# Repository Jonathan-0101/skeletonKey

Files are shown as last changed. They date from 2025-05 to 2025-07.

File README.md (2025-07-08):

# Skeleton Key




Final year BEng Project, creating a Penetration Testing Device based on an ESP32 microcontroller, to highlight common and prevelent security vulnerabilities in devices and networks.

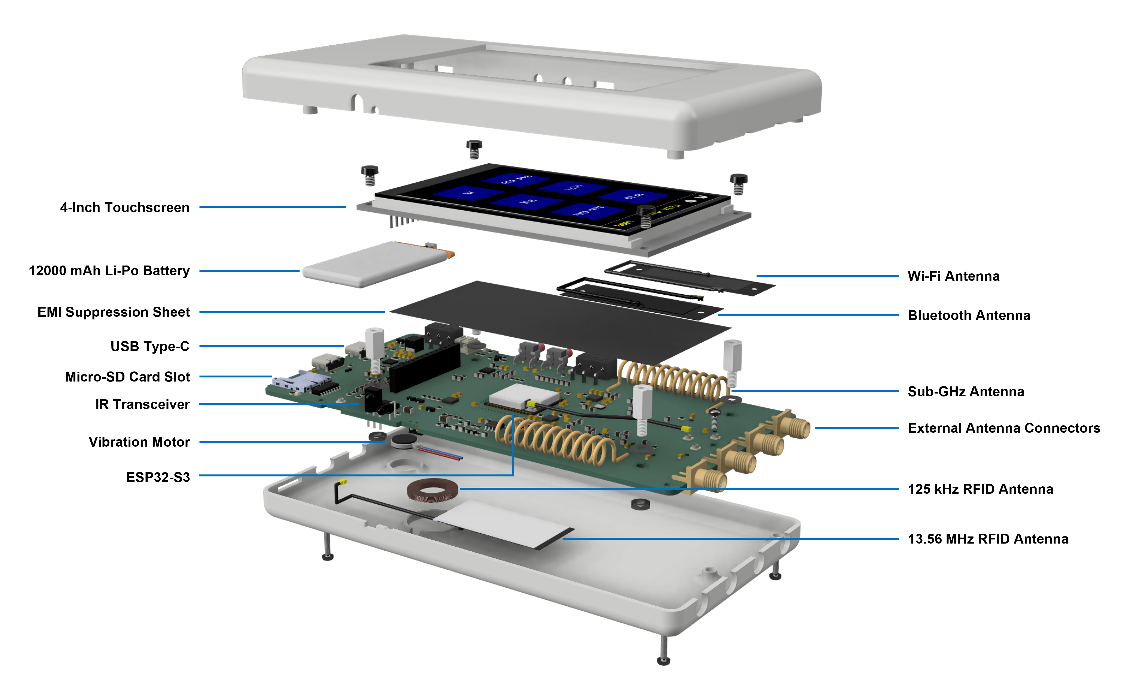
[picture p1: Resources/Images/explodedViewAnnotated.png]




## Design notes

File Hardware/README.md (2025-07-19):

# Project Hardware

The schematics and PCB designs for the device are contained in this directory, designed in KiCad.

It would not have been possible to create the project without the assistance of open source designs and resources, most notibly from [Adafruit Industries](https://github.com/adafruit) and [Flipper Devices](https://github.com/flipperdevices)

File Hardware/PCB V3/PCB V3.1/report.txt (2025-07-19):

Plotted to 'C:\Users\Jonathan Woolf\OneDrive - The University of Nottingham\Documents\0 Project\1_PCB\PCB V3\PCB V3.1\Jonathan_Woolf_PCB_V3_Gerber\PCB V3.1-F_Cu.gbr'.
Plotted to 'C:\Users\Jonathan Woolf\OneDrive - The University of Nottingham\Documents\0 Project\1_PCB\PCB V3\PCB V3.1\Jonathan_Woolf_PCB_V3_Gerber\PCB V3.1-In1_Cu.gbr'.
Plotted to 'C:\Users\Jonathan Woolf\OneDrive - The University of Nottingham\Documents\0 Project\1_PCB\PCB V3\PCB V3.1\Jonathan_Woolf_PCB_V3_Gerber\PCB V3.1-In2_Cu.gbr'.
Plotted to 'C:\Users\Jonathan Woolf\OneDrive - The University of Nottingham\Documents\0 Project\1_PCB\PCB V3\PCB V3.1\Jonathan_Woolf_PCB_V3_Gerber\PCB V3.1-B_Cu.gbr'.
Plotted to 'C:\Users\Jonathan Woolf\OneDrive - The University of Nottingham\Documents\0 Project\1_PCB\PCB V3\PCB V3.1\Jonathan_Woolf_PCB_V3_Gerber\PCB V3.1-F_Paste.gbr'.
Plotted to 'C:\Users\Jonathan Woolf\OneDrive - The University of Nottingham\Documents\0 Project\1_PCB\PCB V3\PCB V3.1\Jonathan_Woolf_PCB_V3_Gerber\PCB V3.1-B_Paste.gbr'.
Plotted to 'C:\Users\Jonathan Woolf\OneDrive - The University of Nottingham\Documents\0 Project\1_PCB\PCB V3\PCB V3.1\Jonathan_Woolf_PCB_V3_Gerber\PCB V3.1-F_Silkscreen.gbr'.
Plotted to 'C:\Users\Jonathan Woolf\OneDrive - The University of Nottingham\Documents\0 Project\1_PCB\PCB V3\PCB V3.1\Jonathan_Woolf_PCB_V3_Gerber\PCB V3.1-B_Silkscreen.gbr'.
Plotted to 'C:\Users\Jonathan Woolf\OneDrive - The University of Nottingham\Documents\0 Project\1_PCB\PCB V3\PCB V3.1\Jonathan_Woolf_PCB_V3_Gerber\PCB V3.1-F_Mask.gbr'.
Plotted to 'C:\Users\Jonathan Woolf\OneDrive - The University of Nottingham\Documents\0 Project\1_PCB\PCB V3\PCB V3.1\Jonathan_Woolf_PCB_V3_Gerber\PCB V3.1-B_Mask.gbr'.
Plotted to 'C:\Users\Jonathan Woolf\OneDrive - The University of Nottingham\Documents\0 Project\1_PCB\PCB V3\PCB V3.1\Jonathan_Woolf_PCB_V3_Gerber\PCB V3.1-Edge_Cuts.gbr'.
Created Gerber job file 'C:\Users\Jonathan Woolf\OneDrive - The University of Nottingham\Documents\0 Project\1_PCB\PCB V3\PCB V3.1\Jonathan_Woolf_PCB_V3_Gerber\PCB V3.1-job.gbrjob'.
Info: Done.

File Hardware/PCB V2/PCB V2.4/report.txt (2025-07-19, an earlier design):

Info: Output directory 'C:\Users\Jonathan Woolf\OneDrive - The University of Nottingham\Documents\0 Project\1_PCB\PCB V2\PCB V2.4\Gerber' created.
Plotted to 'C:\Users\Jonathan Woolf\OneDrive - The University of Nottingham\Documents\0 Project\1_PCB\PCB V2\PCB V2.4\Gerber\PCB V2.4-F_Cu.gbr'.
Plotted to 'C:\Users\Jonathan Woolf\OneDrive - The University of Nottingham\Documents\0 Project\1_PCB\PCB V2\PCB V2.4\Gerber\PCB V2.4-In1_Cu.gbr'.
Plotted to 'C:\Users\Jonathan Woolf\OneDrive - The University of Nottingham\Documents\0 Project\1_PCB\PCB V2\PCB V2.4\Gerber\PCB V2.4-In2_Cu.gbr'.
Plotted to 'C:\Users\Jonathan Woolf\OneDrive - The University of Nottingham\Documents\0 Project\1_PCB\PCB V2\PCB V2.4\Gerber\PCB V2.4-B_Cu.gbr'.
Plotted to 'C:\Users\Jonathan Woolf\OneDrive - The University of Nottingham\Documents\0 Project\1_PCB\PCB V2\PCB V2.4\Gerber\PCB V2.4-F_Paste.gbr'.
Plotted to 'C:\Users\Jonathan Woolf\OneDrive - The University of Nottingham\Documents\0 Project\1_PCB\PCB V2\PCB V2.4\Gerber\PCB V2.4-B_Paste.gbr'.
Plotted to 'C:\Users\Jonathan Woolf\OneDrive - The University of Nottingham\Documents\0 Project\1_PCB\PCB V2\PCB V2.4\Gerber\PCB V2.4-F_Silkscreen.gbr'.
Plotted to 'C:\Users\Jonathan Woolf\OneDrive - The University of Nottingham\Documents\0 Project\1_PCB\PCB V2\PCB V2.4\Gerber\PCB V2.4-B_Silkscreen.gbr'.
Plotted to 'C:\Users\Jonathan Woolf\OneDrive - The University of Nottingham\Documents\0 Project\1_PCB\PCB V2\PCB V2.4\Gerber\PCB V2.4-F_Mask.gbr'.
Plotted to 'C:\Users\Jonathan Woolf\OneDrive - The University of Nottingham\Documents\0 Project\1_PCB\PCB V2\PCB V2.4\Gerber\PCB V2.4-B_Mask.gbr'.
Plotted to 'C:\Users\Jonathan Woolf\OneDrive - The University of Nottingham\Documents\0 Project\1_PCB\PCB V2\PCB V2.4\Gerber\PCB V2.4-Edge_Cuts.gbr'.
Created Gerber job file 'C:\Users\Jonathan Woolf\OneDrive - The University of Nottingham\Documents\0 Project\1_PCB\PCB V2\PCB V2.4\Gerber\PCB V2.4-job.gbrjob'.
Plotted to 'C:\Users\Jonathan Woolf\OneDrive - The University of Nottingham\Documents\0 Project\1_PCB\PCB V2\PCB V2.4\Gerber\PCB V2.4-F_Cu.gbr'.
Plotted to 'C:\Users\Jonathan Woolf\OneDrive - The University of Nottingham\Documents\0 Project\1_PCB\PCB V2\PCB V2.4\Gerber\PCB V2.4-In1_Cu.gbr'.
Plotted to 'C:\Users\Jonathan Woolf\OneDrive - The University of Nottingham\Documents\0 Project\1_PCB\PCB V2\PCB V2.4\Gerber\PCB V2.4-In2_Cu.gbr'.
Plotted to 'C:\Users\Jonathan Woolf\OneDrive - The University of Nottingham\Documents\0 Project\1_PCB\PCB V2\PCB V2.4\Gerber\PCB V2.4-B_Cu.gbr'.
Plotted to 'C:\Users\Jonathan Woolf\OneDrive - The University of Nottingham\Documents\0 Project\1_PCB\PCB V2\PCB V2.4\Gerber\PCB V2.4-F_Paste.gbr'.
Plotted to 'C:\Users\Jonathan Woolf\OneDrive - The University of Nottingham\Documents\0 Project\1_PCB\PCB V2\PCB V2.4\Gerber\PCB V2.4-B_Paste.gbr'.
Plotted to 'C:\Users\Jonathan Woolf\OneDrive - The University of Nottingham\Documents\0 Project\1_PCB\PCB V2\PCB V2.4\Gerber\PCB V2.4-F_Silkscreen.gbr'.
Plotted to 'C:\Users\Jonathan Woolf\OneDrive - The University of Nottingham\Documents\0 Project\1_PCB\PCB V2\PCB V2.4\Gerber\PCB V2.4-B_Silkscreen.gbr'.
Plotted to 'C:\Users\Jonathan Woolf\OneDrive - The University of Nottingham\Documents\0 Project\1_PCB\PCB V2\PCB V2.4\Gerber\PCB V2.4-F_Mask.gbr'.
Plotted to 'C:\Users\Jonathan Woolf\OneDrive - The University of Nottingham\Documents\0 Project\1_PCB\PCB V2\PCB V2.4\Gerber\PCB V2.4-B_Mask.gbr'.
Plotted to 'C:\Users\Jonathan Woolf\OneDrive - The University of Nottingham\Documents\0 Project\1_PCB\PCB V2\PCB V2.4\Gerber\PCB V2.4-Edge_Cuts.gbr'.
Created Gerber job file 'C:\Users\Jonathan Woolf\OneDrive - The University of Nottingham\Documents\0 Project\1_PCB\PCB V2\PCB V2.4\Gerber\PCB V2.4-job.gbrjob'.
Info: Done.
Info: Done.

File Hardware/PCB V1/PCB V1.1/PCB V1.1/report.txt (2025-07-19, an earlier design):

Plotted to 'C:\Users\Jonathan Woolf\OneDrive - The University of Nottingham\Documents\0 Project\PCB test\PCB V1.1\PCB V1.1\Gerber\PCB V1.1-F_Cu.gbr'.
Plotted to 'C:\Users\Jonathan Woolf\OneDrive - The University of Nottingham\Documents\0 Project\PCB test\PCB V1.1\PCB V1.1\Gerber\PCB V1.1-B_Cu.gbr'.
Plotted to 'C:\Users\Jonathan Woolf\OneDrive - The University of Nottingham\Documents\0 Project\PCB test\PCB V1.1\PCB V1.1\Gerber\PCB V1.1-F_Paste.gbr'.
Plotted to 'C:\Users\Jonathan Woolf\OneDrive - The University of Nottingham\Documents\0 Project\PCB test\PCB V1.1\PCB V1.1\Gerber\PCB V1.1-B_Paste.gbr'.
Plotted to 'C:\Users\Jonathan Woolf\OneDrive - The University of Nottingham\Documents\0 Project\PCB test\PCB V1.1\PCB V1.1\Gerber\PCB V1.1-F_Silkscreen.gbr'.
Plotted to 'C:\Users\Jonathan Woolf\OneDrive - The University of Nottingham\Documents\0 Project\PCB test\PCB V1.1\PCB V1.1\Gerber\PCB V1.1-B_Silkscreen.gbr'.
Plotted to 'C:\Users\Jonathan Woolf\OneDrive - The University of Nottingham\Documents\0 Project\PCB test\PCB V1.1\PCB V1.1\Gerber\PCB V1.1-F_Mask.gbr'.
Plotted to 'C:\Users\Jonathan Woolf\OneDrive - The University of Nottingham\Documents\0 Project\PCB test\PCB V1.1\PCB V1.1\Gerber\PCB V1.1-B_Mask.gbr'.
Plotted to 'C:\Users\Jonathan Woolf\OneDrive - The University of Nottingham\Documents\0 Project\PCB test\PCB V1.1\PCB V1.1\Gerber\PCB V1.1-Edge_Cuts.gbr'.
Created Gerber job file 'C:\Users\Jonathan Woolf\OneDrive - The University of Nottingham\Documents\0 Project\PCB test\PCB V1.1\PCB V1.1\Gerber\PCB V1.1-job.gbrjob'.
Info: Done.

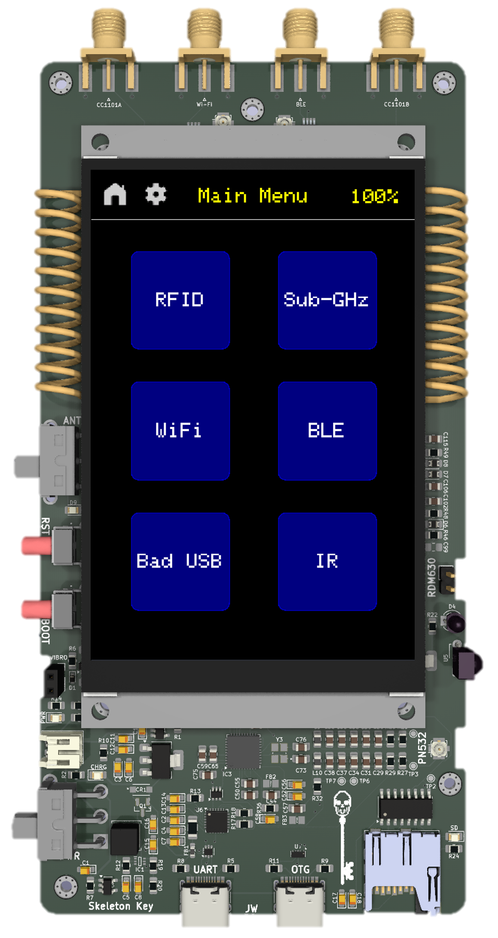
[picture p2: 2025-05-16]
Resources/Images/deviceTopDown.png

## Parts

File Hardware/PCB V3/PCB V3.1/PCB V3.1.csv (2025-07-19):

Id | Designator | Footprint | Quantity | Designation | Supplier and ref
1 | C82,C100,C101,C123,C84,C99,C53,C54,C96,C113,C118,C71,C80,C121,C45 | C_0805_2012Metric_Pad1.18x1.45mm_HandSolder | 15 | ~
2 | TP3 | TestPoint_Pad_D1.0mm | 1 | TX2_PRE
3 | C62,C31,C108,C30,C63,C107 | C_0805_2012Metric_Pad1.18x1.45mm_HandSolder | 6 | 100p
4 | C17,C87,C122,C88,C12,C40,C6,C70,C39,C66,C72,C68,C85,C111,C19,C24,C110,C25,C20,C112,C60,C52,C93,C32,C105,C114,C103,C91,C67,C92,C58,C94,C21,C109 | CP_EIA-2012-12_Kemet-R_Pad1.30x1.05mm_HandSolder | 34 | 0.1u
5 | L24,L13 | L_0805_2012Metric_Pad1.15x1.40mm_HandSolder | 2 | 6.8n
6 | L10,L9 | L_0805_2012Metric_Pad1.15x1.40mm_HandSolder | 2 | 560n
7 | C76,C73 | C_0805_2012Metric_Pad1.18x1.45mm_HandSolder | 2 | 33p
8 | C14,C4,C10 | CP_EIA-2012-12_Kemet-R_Pad1.30x1.05mm_HandSolder | 3 | 100n
9 | Q5 | TSOT-23_HandSoldering | 1 | Q_NPN_BEC
10 | R26,R27 | R_0805_2012Metric_Pad1.20x1.40mm_HandSolder | 2 | NC
11 | C69 | C_0805_2012Metric_Pad1.18x1.45mm_HandSolder | 1 | 0.3p
12 | C13,C16,C8,C15,C2 | CP_EIA-2012-12_Kemet-R_Pad1.30x1.05mm_HandSolder | 5 | 22u
13 | L2 | L_0805_2012Metric_Pad1.15x1.40mm_HandSolder | 1 | 8.2n
14 | TP6 | TestPoint_Pad_D1.0mm | 1 | TX2_POST
15 | C35,C28,C29,C38 | C_0805_2012Metric_Pad1.18x1.45mm_HandSolder | 4 | NC
16 | TP1 | TestPoint_Pad_D1.0mm | 1 | TX1_PRE
17 | Q6 | TSOT-23_HandSoldering | 1 | Q_PNP_BEC
18 | R51,R39,R38,R53 | R_0805_2012Metric_Pad1.20x1.40mm_HandSolder | 4 | 0
19 | L17,L26 | L_0805_2012Metric_Pad1.15x1.40mm_HandSolder | 2 | 2.2n
20 | L12,L23 | L_0805_2012Metric_Pad1.15x1.40mm_HandSolder | 2 | 3.3n
21 | L1 | L_Changjiang_FNR5045S | 1 | 1u
22 | J6 | PinHeader_1x02_P2.54mm_Vertical | 1 | RDM630_ANT_CONN
23 | Q4 | SOT-223-3_TabPin2 | 1 | PZT3904
24 | C18,C22,C86,C41,C119,C3,C56,C64,C11 | CP_EIA-2012-12_Kemet-R_Pad1.30x1.05mm_HandSolder | 9 | 10u
25 | R14,R59,R10,R24 | R_0805_2012Metric_Pad1.20x1.40mm_HandSolder | 4 | 1.5K
26 | R33,R47 | R_0805_2012Metric_Pad1.20x1.40mm_HandSolder | 2 | 56K
27 | R25 | R_0805_2012Metric_Pad1.20x1.40mm_HandSolder | 1 | 22k
28 | USB_OTG1,USB_UART1 | USB_C_Receptacle_HRO_TYPE-C-31-M-12 | 2 | USB_C_Receptacle_USB2.0_16P
29 | J10,J8 | PinSocket_1x14_P1.27mm_Vertical | 2 | Conn_01x14
30 | L18,L19,L4,L5,L20,L7 | L_0805_2012Metric_Pad1.15x1.40mm_HandSolder | 6 | 0
31 | R12,R20,R7 | R_0805_2012Metric_Pad1.20x1.40mm_HandSolder | 3 | 100k
32 | R1 | R_0805_2012Metric_Pad1.20x1.40mm_HandSolder | 1 | 4.7K
33 | L14,L15 | L_0805_2012Metric_Pad1.15x1.40mm_HandSolder | 2 | 2.4n
34 | C48 | C_0805_2012Metric_Pad1.18x1.45mm_HandSolder | 1 | 4.7p
35 | R16,R15,R2,R23,R4,R43 | R_0805_2012Metric_Pad1.20x1.40mm_HandSolder | 6 | 10K
36 | FB1 | L_0603_1608Metric_Pad1.05x0.95mm_HandSolder | 1 | BLM21PG221
37 | C115,C102 | C_0805_2012Metric_Pad1.18x1.45mm_HandSolder | 2 | 1n
38 | U9 | ESP32-S3-WROOM-1U_EXP | 1 | ESP32-S3-WROOM-1U-N16R2
39 | C104,C61 | C_0805_2012Metric_Pad1.18x1.45mm_HandSolder | 2 | 0.6p
40 | R49,R48,R52,R31,R57 | R_0805_2012Metric_Pad1.20x1.40mm_HandSolder | 5 | 1M
41 | C47 | C_0805_2012Metric_Pad1.18x1.45mm_HandSolder | 1 | 2.2n
42 | FB2,FB4 | BEADC2012X145N | 2 | FerriteBead
43 | U7 | Diodes_UDFN-10_1.0x2.5mm_P0.5mm | 1 | ESD7104MUTAG
44 | R35,R34,R36 | R_0805_2012Metric_Pad1.20x1.40mm_HandSolder | 3 | 1K
45 | R58,R55,R45,R50,R41,R54,R40,R56,R44 | R_0805_2012Metric_Pad1.20x1.40mm_HandSolder | 9 | 1k
46 | U13,U20,U11,U17,U16,U18,U15,U14 | Infineon_PG-TSNP-6-10_0.7x1.1mm_0.7x1.1mm_P0.4mm | 8 | BGS12WN6E6327XTSA1
47 | L25,L16 | L_0805_2012Metric_Pad1.15x1.40mm_HandSolder | 2 | ~
48 | PWR_SW1,ANT_SW1 | PWR-SW | 2 | 734-7296
49 | R37 | R_0805_2012Metric_Pad1.20x1.40mm_HandSolder | 1 | 20K
50 | C55,C59,C65,C83,C44 | C_0805_2012Metric_Pad1.18x1.45mm_HandSolder | 5 | 0.1u
51 | C1,C5 | CP_EIA-2012-12_Kemet-R_Pad1.30x1.05mm_HandSolder | 2 | 1u
52 | U4 | SOT-223-3_TabPin2 | 1 | AMS1117-3.3
53 | RESET1,BOOT1 | 118250272 | 2 | 1-1825027-2
54 | IC1 | SOTFL50P160X60-6N | 1 | TPS61023DRLT
55 | R46 | R_0805_2012Metric_Pad1.20x1.40mm_HandSolder | 1 | 10R
56 | IC7,IC5 | SOT95P284X110-6N | 2 | DG2001EDV-T1-GE3
57 | D7,D6,D8 | D_0805_2012Metric_Pad1.15x1.40mm_HandSolder | 3 | D
58 | U1 | SOT-23-5 | 1 | MCP73831-2-OT
59 | U19 | SOIC127P600X175-8N | 1 | LM358
60 | C57 | C_0805_2012Metric_Pad1.18x1.45mm_HandSolder | 1 | 1000p
61 | L11,L22 | L_0805_2012Metric_Pad1.15x1.40mm_HandSolder | 2 | 56n
62 | C97,C46 | C_0805_2012Metric_Pad1.18x1.45mm_HandSolder | 2 | 8.2p
63 | IC4 | QFN50P400X400X100-21N-D | 1 | C8051F330-GM
64 | IC3 | HVQFN-40-1EP_6x6mm_P0.5mm_EP4.1x4.1mm_ThermalVias | 1 | PN5321A3HN_C106,55
65 | IC2,IC6 | QFN50P400X400X100-21N-D | 2 | CC1101RGPR
66 | Y3 | XTAL_7M-27.120MAAJ-T | 1 | 27.12M
67 | J1 | PinSocket_1x02_P2.54mm_Vertical | 1 | Conn_01x02
68 | R5,R8,R11,R9 | R_0805_2012Metric_Pad1.20x1.40mm_HandSolder | 4 | 5k1
69 | C77,C116 | C_0805_2012Metric_Pad1.18x1.45mm_HandSolder | 2 | 1.2p
70 | C98,C95 | C_1206_3216Metric_Pad1.33x1.80mm_HandSolder | 2 | 3.3n
71 | C43,C33,C42,C34 | C_0805_2012Metric_Pad1.18x1.45mm_HandSolder | 4 | 22p
72 | Q7 | SOT-23 | 1 | MMBT5551L
73 | D4 | LED_D3.0mm_IRBlack | 1 | IR204A
74 | L8,L21,L3 | L_0805_2012Metric_Pad1.15x1.40mm_HandSolder | 3 | 2.7n
75 | R32 | R_0805_2012Metric_Pad1.20x1.40mm_HandSolder | 1 | 1.69K
76 | Q2 | SOT-23 | 1 | DMN2058U
77 | C49,C78,C79,C74,C81 | C_0805_2012Metric_Pad1.18x1.45mm_HandSolder | 5 | 1.5p
78 | FL2,FL1 | B0310J50100AHF | 2 | B0310J50100AHF
79 | U3 | SOT-23-5 | 1 | TLV70036_SOT23-5
80 | JSTPH1 | JST_PH_S2B-PH-K_1x02_P2.00mm_Horizontal | 1 | Battery Plug
81 | TP5,TP2 | TestPoint_Pad_D1.0mm | 2 | TGND
82 | R3 | R_0805_2012Metric_Pad1.20x1.40mm_HandSolder | 1 | 150
83 | J3 | GCT_MEM2061-01-188-00-A_REVA | 1 | MEM2061-01-188-00-A_REVA
84 | C37,C36 | C_0805_2012Metric_Pad1.18x1.45mm_HandSolder | 2 | 220p
85 | C23 | C_0805_2012Metric_Pad1.18x1.45mm_HandSolder | 1 | 33n
86 | R19 | R_0805_2012Metric_Pad1.20x1.40mm_HandSolder | 1 | 732k
87 | U2 | SOT-666 | 1 | USBLC6-2P6
88 | U6 | QFN-24-1EP_4x4mm_P0.5mm_EP2.6x2.6mm | 1 | CP2104
89 | C27,C90,C89,C26 | C_0805_2012Metric_Pad1.18x1.45mm_HandSolder | 4 | 9p
90 | D9 | LED_0805_2012Metric_Pad1.15x1.40mm_HandSolder | 1 | ANT_LED
91 | AE3 | SMA_Molex_73251-1153_EdgeMount_Horizontal | 1 | Antenna_CC1101B_SMA
92 | U5 | Vishay_MINICAST-3Pin | 1 | TSOP382xx
93 | AE8 | U.FL_Molex_MCRF_73412-0110_Vertical | 1 | Antenna_Wi-Fi_TBAR
94 | R13 | R_0805_2012Metric_Pad1.20x1.40mm_HandSolder | 1 | 10k
95 | R6 | R_0805_2012Metric_Pad1.20x1.40mm_HandSolder | 1 | 22
96 | R18,R17 | R_0805_2012Metric_Pad1.20x1.40mm_HandSolder | 2 | 22R
97 | C106,C120 | C_0805_2012Metric_Pad1.18x1.45mm_HandSolder | 2 | 4.7u
98 | Y2 | XTAL_7M-27.120MAAJ-T | 1 | 16M
99 | CR1 | SDO_SOD-123FL498_OSI | 1 | MBR120
100 | TP7 | TestPoint_Pad_D1.0mm | 1 | RX
101 | Y1,Y4 | Crystal_SMD_3225-4Pin_3.2x2.5mm_HandSoldering | 2 | 26MHz
102 | R22 | R_0805_2012Metric_Pad1.20x1.40mm_HandSolder | 1 | 50
103 | D3 | LED_0805_2012Metric_Pad1.15x1.40mm_HandSolder | 1 | Power_LED
104 | AE4 | XDCR_ANT-433-HESM | 1 | Antenna_CC1101B_PCB
105 | R42,R30,R21 | R_0805_2012Metric_Pad1.20x1.40mm_HandSolder | 3 | 330
106 | R28,R29 | R_0805_2012Metric_Pad1.20x1.40mm_HandSolder | 2 | 1.5
107 | C75,C50 | C_0805_2012Metric_Pad1.18x1.45mm_HandSolder | 2 | 10u
108 | U10 | QFN-20-1EP_4x4mm_P0.5mm_EP2.5x2.5mm | 1 | nRF24L01P
109 | FB3 | BEADC2012X145N | 1 | FerriteBead_Small
110 | D5 | LED_0805_2012Metric_Pad1.15x1.40mm_HandSolder | 1 | SD_ACT_LED
111 | Q1 | SOT95P240X105-3N | 1 | DMG3415U
112 | C51 | C_0805_2012Metric_Pad1.18x1.45mm_HandSolder | 1 | 1p
113 | F1 | Fuse_1206_3216Metric_Pad1.42x1.75mm_HandSolder | 1 | Polyfuse 1A
114 | D2 | LED_0805_2012Metric_Pad1.15x1.40mm_HandSolder | 1 | Charging_LED
115 | C7 | CP_EIA-2012-12_Kemet-R_Pad1.30x1.05mm_HandSolder | 1 | 4u7
116 | J5 | U.FL_Molex_MCRF_73412-0110_Vertical | 1 | PN532_Antenna_Coax
117 | U8 | SOIC-16_3.9x9.9mm_P1.27mm | 1 | 4050
118 | D1 | D_SOD-523 | 1 | 1N4148WT
119 | Q3 | SOT-363_SC-70-6 | 1 | UMH3N
120 | AE1 | SMA_Molex_73251-1153_EdgeMount_Horizontal | 1 | Antenna_CC1101A_SMA
121 | AE7 | SMA_Molex_73251-1153_EdgeMount_Horizontal | 1 | Antenna_Wi-Fi_SMA
122 | SCREEN1 | 4.0_TFT_Display | 1 | ~
123 | J9 | PinSocket_1x12_P1.27mm_Vertical | 1 | Conn_01x12
124 | TP4 | TestPoint_Pad_D1.0mm | 1 | TX1_POST
125 | C117 | C_0805_2012Metric_Pad1.18x1.45mm_HandSolder | 1 | 100n
126 | U12 | RFX2401C_SKY | 1 | RFX2401C
127 | AE2 | XDCR_ANT-433-HESM | 1 | Antenna_CC1101A_PCB
128 | J7 | U.FL_Molex_MCRF_73412-0110_Vertical | 1 | Wi-Fi_ANT_Coax
129 | L6 | L_0805_2012Metric_Pad1.15x1.40mm_HandSolder | 1 | 3.9n
130 | AE6 | U.FL_Molex_MCRF_73412-0110_Vertical | 1 | Antenna_NRF24_IPEX
131 | AE5 | SMA_Molex_73251-1153_EdgeMount_Horizontal | 1 | Antenna_NRF24_SMA

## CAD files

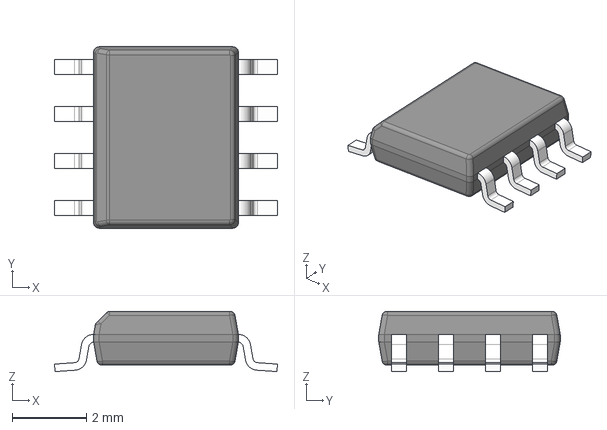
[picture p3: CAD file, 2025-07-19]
Hardware/Symbols_Footprints_3D_Models/3D Models/LM358MX_NOPB.stp
6.02 x 4.90 x 1.63 mm
BODY-SO
LEAD-D0008A x 8

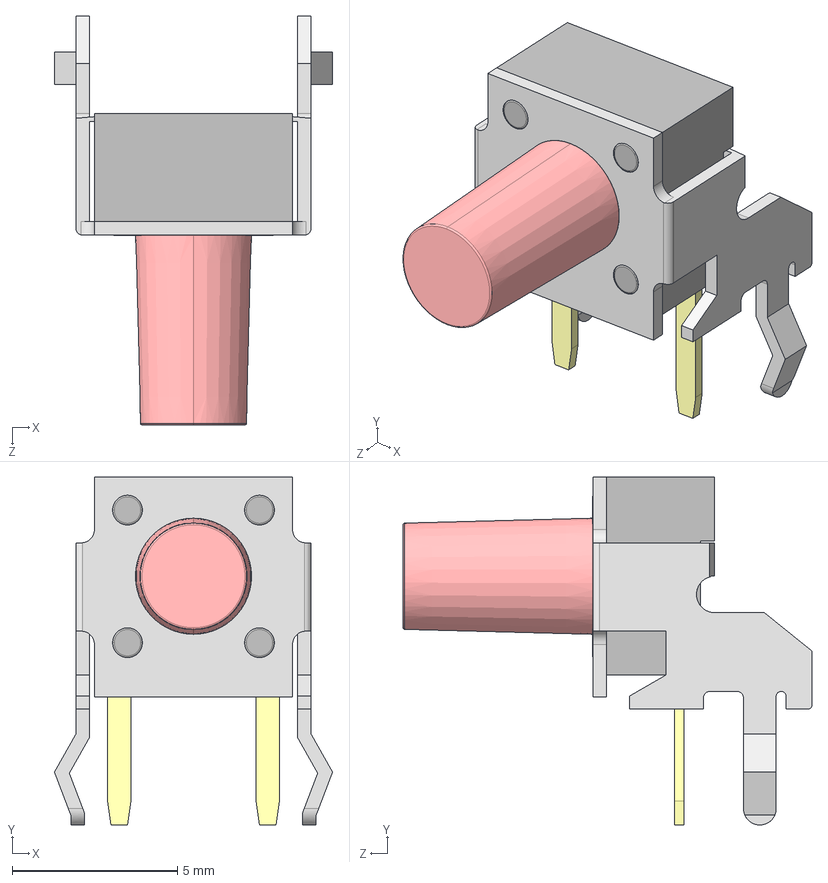
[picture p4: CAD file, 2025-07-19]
Hardware/Symbols_Footprints_3D_Models/3D Models/1-1825027-2.stp
8.41 x 10.5 x 12.4 mm

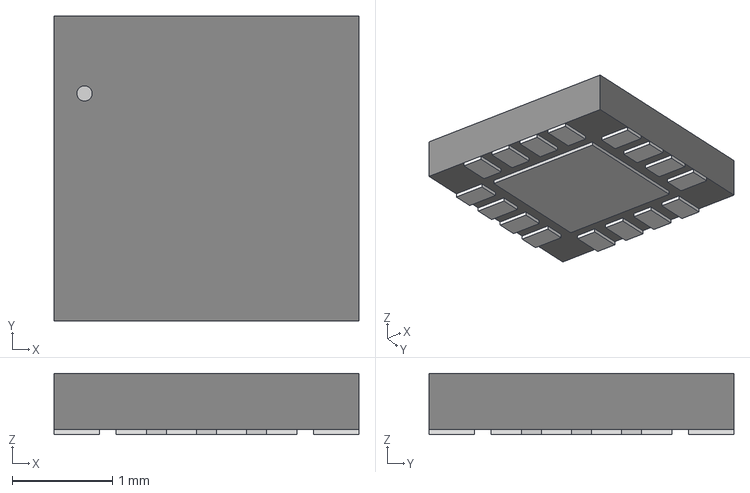
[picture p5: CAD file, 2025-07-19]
Hardware/Symbols_Footprints_3D_Models/3D Models/RFX2401C_SKY.step
3.05 x 3.05 x 0.612 mm

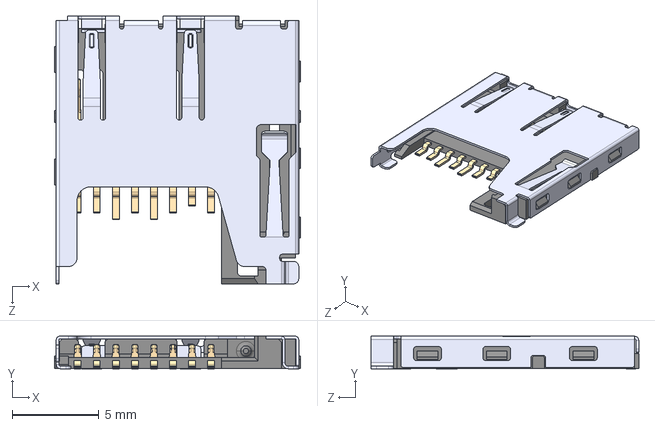
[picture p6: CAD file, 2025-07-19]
Hardware/Symbols_Footprints_3D_Models/3D Models/MEM2061-01-188-00-A_REVA.step
14.2 x 1.88 x 15.4 mm

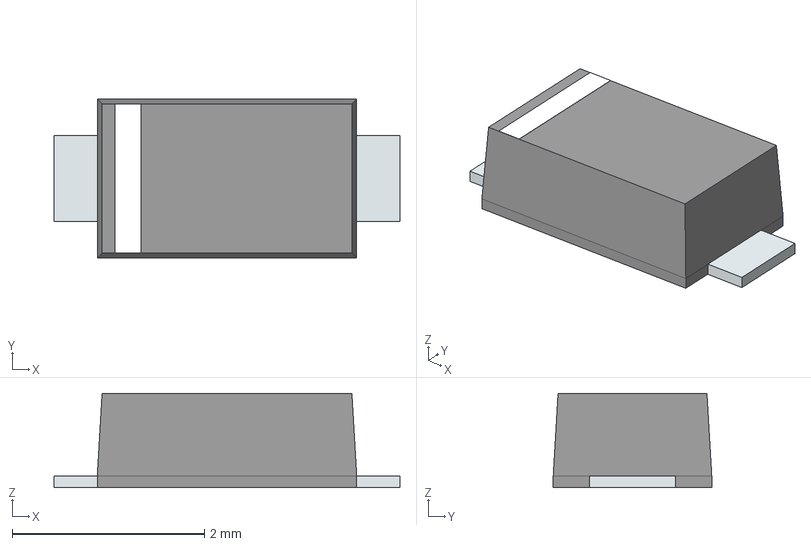
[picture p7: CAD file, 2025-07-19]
Hardware/Symbols_Footprints_3D_Models/3D Models/MBR120ESFT3G.stp
3.60 x 1.65 x 0.98 mm
PinKIdent
PinK
PinA

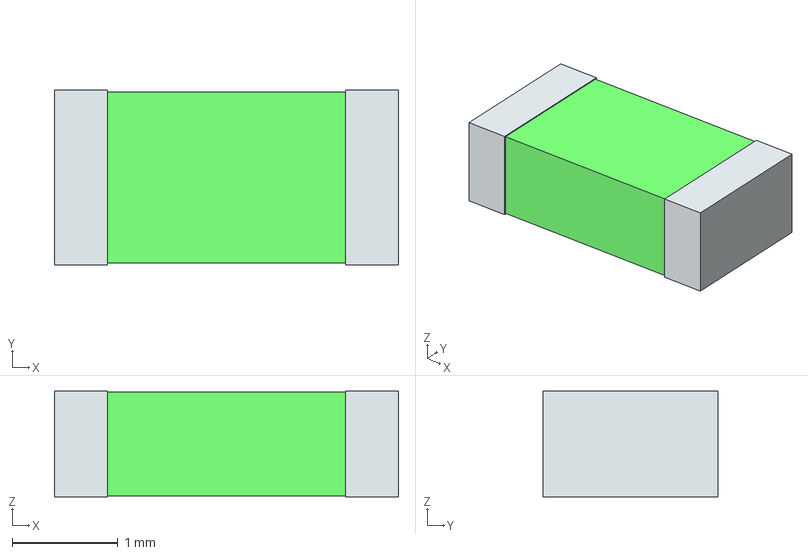
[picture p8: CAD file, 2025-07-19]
Hardware/Symbols_Footprints_3D_Models/3D Models/0ZCJ0100FF2E.stp
3.25 x 1.65 x 1.00 mm
term1
term2

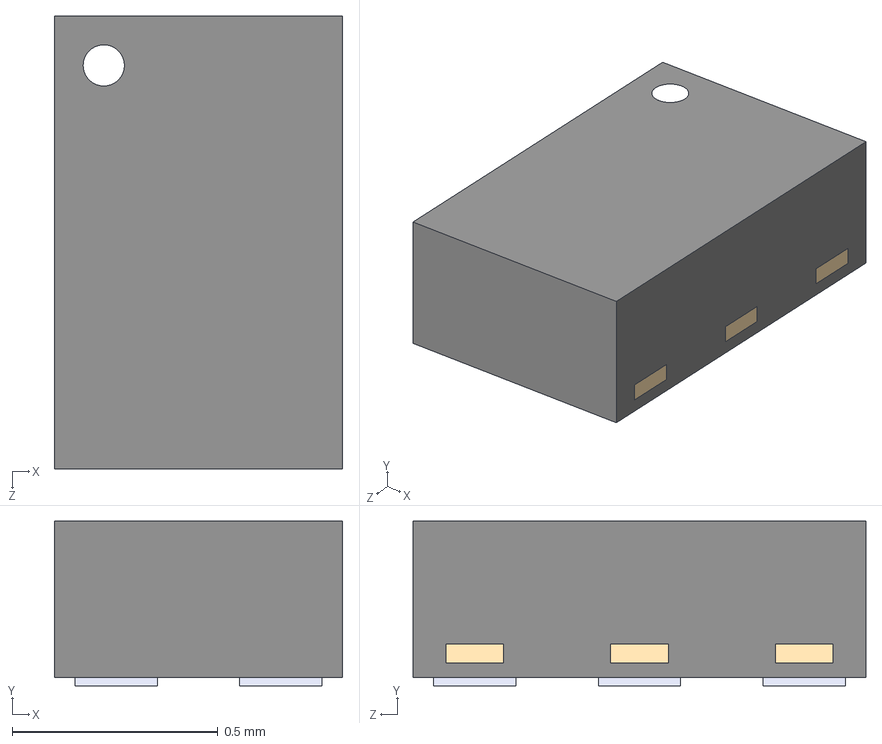
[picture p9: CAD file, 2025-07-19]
Hardware/Symbols_Footprints_3D_Models/3D Models/BGS12WN6E6327XTSA1.stp
0.7 x 0.4 x 1.10 mm

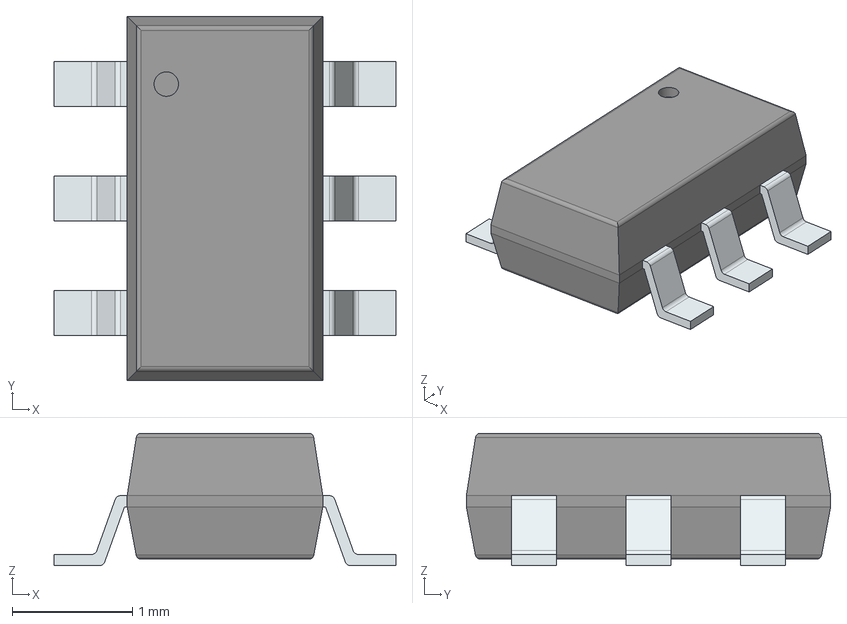
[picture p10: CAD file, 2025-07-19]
Hardware/Symbols_Footprints_3D_Models/3D Models/DG2001EDV-T1-GE3.stp
2.84 x 3.02 x 1.10 mm
PinsArrayLR

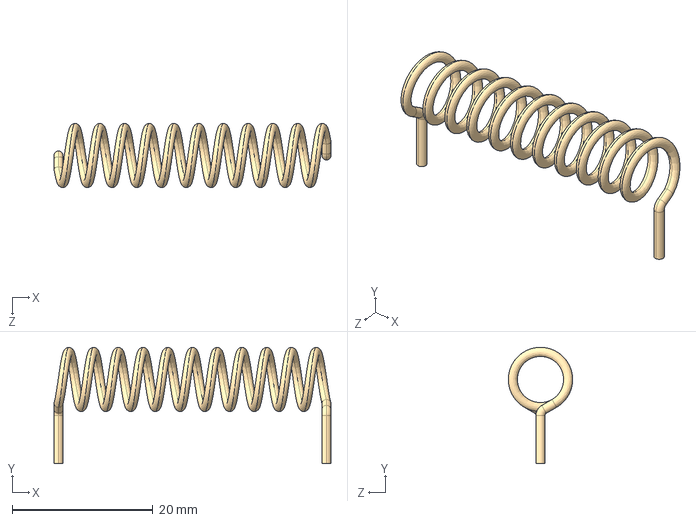
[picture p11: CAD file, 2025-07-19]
Hardware/Symbols_Footprints_3D_Models/3D Models/ANT-433-HETH.step
39.4 x 16.5 x 9.14 mm

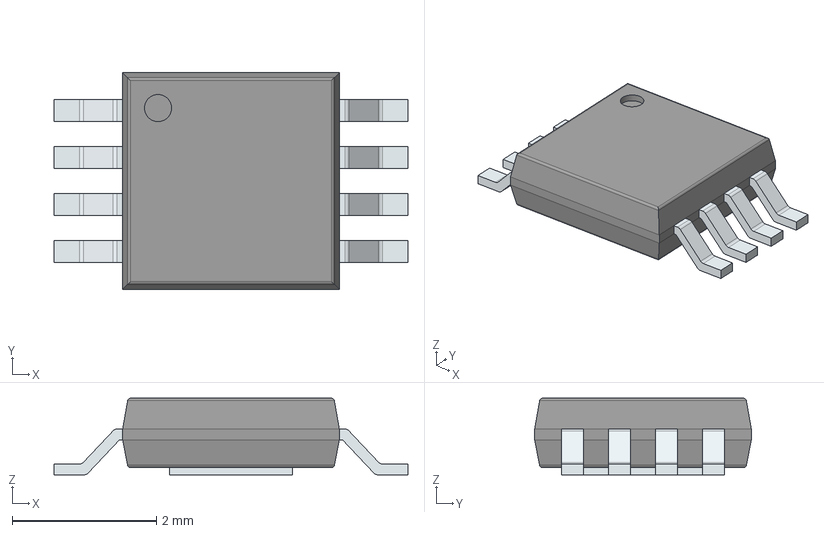
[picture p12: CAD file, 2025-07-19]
Hardware/Symbols_Footprints_3D_Models/3D Models/PE4251MLI-Z.stp
4.90 x 3.00 x 1.06 mm
PinsArrayLR
ThermalPad

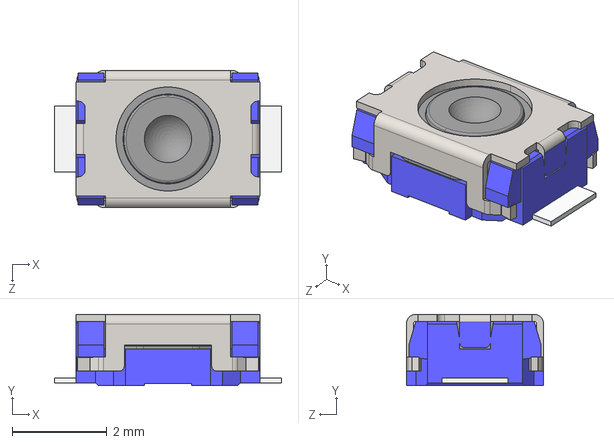
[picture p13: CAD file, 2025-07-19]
Hardware/Symbols_Footprints_3D_Models/3D Models/SKRKAGE020.stp
4.80 x 1.51 x 2.90 mm

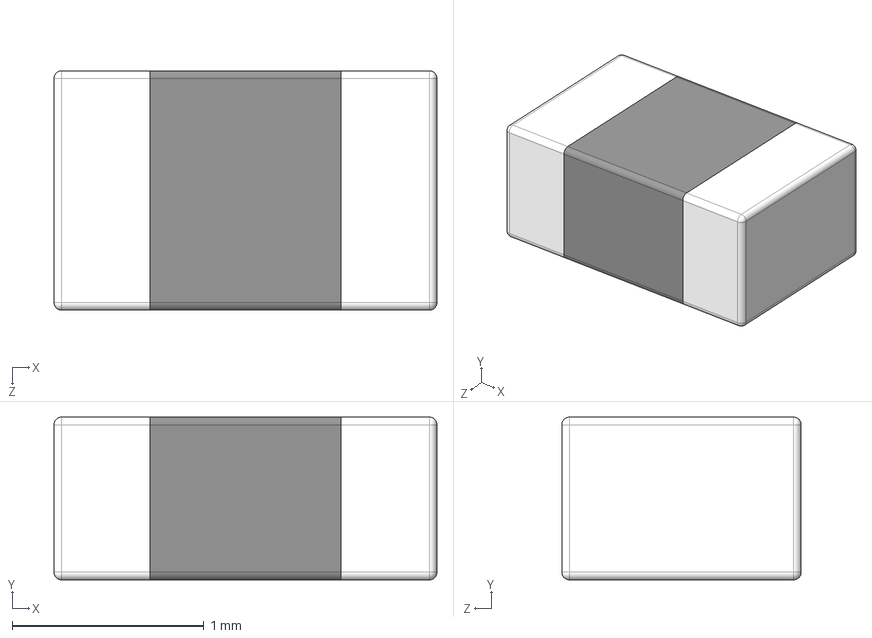
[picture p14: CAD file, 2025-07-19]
Hardware/Symbols_Footprints_3D_Models/3D Models/BLM21AG601SH1D.stp
2.00 x 0.85 x 1.25 mm

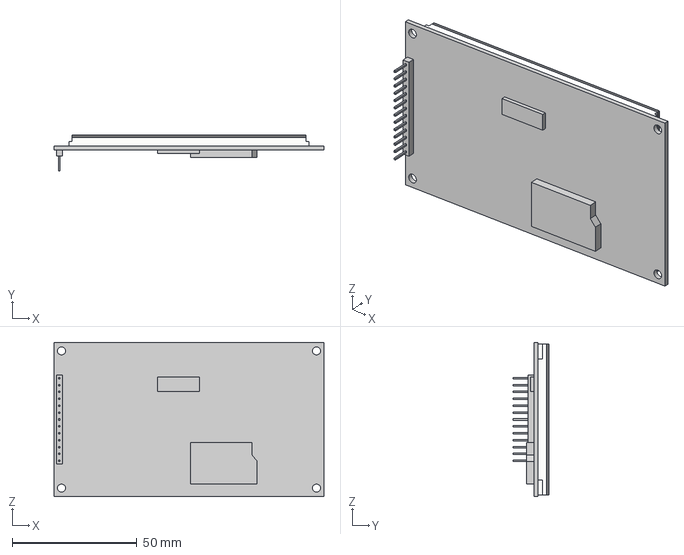
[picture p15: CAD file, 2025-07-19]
Hardware/Symbols_Footprints_3D_Models/3D Models/4 Inch TFT SPI 480x320 V1.2.step
108.0 x 14.5 x 61.6 mm

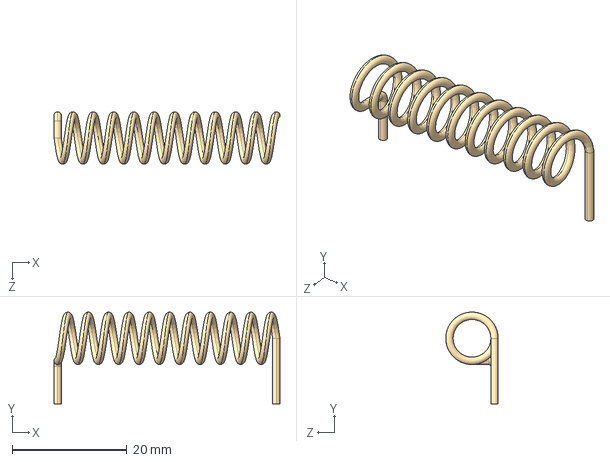
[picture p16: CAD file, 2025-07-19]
Hardware/Symbols_Footprints_3D_Models/3D Models/ANT-433-HESM.step
39.4 x 16.0 x 9.14 mm

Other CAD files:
Hardware/Symbols_Footprints_3D_Models/3D Models/DMG3415UQ-7.stp
Hardware/Symbols_Footprints_3D_Models/3D Models/C8051F330-GM.stp
Hardware/Symbols_Footprints_3D_Models/3D Models/B0310J50100AHF.stp
Hardware/Symbols_Footprints_3D_Models/3D Models/PN5321A3HN_C106,55.stp
Hardware/PCB V1/PCB V1.0/PCB V1.0/PCB V1.0.step
Hardware/PCB V1/PCB V1.1/PCB V1.1/PCB V1.1.step
Hardware/PCB V1/PCB/PCB.step
Hardware/PCB V2/PCB V2.0/PCB V2.0.step
Hardware/Symbols_Footprints_3D_Models/3D Models/7347296.stp
Hardware/Symbols_Footprints_3D_Models/3D Models/CC1101RGPR.stp
Hardware/Symbols_Footprints_3D_Models/3D Models/TPS61023DRLT.stp

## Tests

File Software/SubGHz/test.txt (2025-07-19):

//
// CC1101 interactive terminal tool
// allows for sending / receiving data over serial port
// on selected radio channel, modulation, ..
//
// (C) Adam Loboda '2023 , adam.loboda@wp.pl
//
// based on great SmartRC library by Little_S@tan
// Please download ZIP from
// https://github.com/LSatan/SmartRC-CC1101-Driver-Lib
// and attach it as ZIP library for Arduino
//
// Also uses Arduino Command Line interpreter by Edgar Bonet
// from https://gist.github.com/edgar-bonet/607b387260388be77e96
//
// This code will ONLY work with ESP32 board
//

#include <EEPROM.h>
#include <ELECHOUSE_CC1101_SRC_DRV.h>

#define CCBUFFERSIZE 64
#define RECORDINGBUFFERSIZE 4096  // Buffer for recording the frames
#define EPROMSIZE 512             // Size of EEPROM in your Arduino chip. For ESP32 it is Flash simulated so very slow
#define BUF_LENGTH 128            // Buffer for the incoming command.

// defining PINs set for ESP32 module
// Example for XIAO ESP32 C3
/* byte sck = 8;
byte miso = 4;
byte mosi = 10;
byte ss = 20;
int gdo0 = 21;
int gdo2 = 7; */

// defining PINs set for ESP32 WROOM module

// // ---------------------------------------
// // CC1101A
// byte sck = 39;
// byte miso = 41;
// byte mosi = 40;
// byte ss = 8;
// int gdo0 = 9;
// int rfSwitch = 10;
// // ---------------------------------------

// ---------------------------------------
// CC1101B
byte sck = 17;
byte miso = 15;
byte mosi = 16;
byte ss = 3;
int gdo0 = 11;
int rfSwitch = 12;
// ---------------------------------------

// position in big recording buffer
int bigrecordingbufferpos = 0;

// number of frames in big recording buffer
int framesinbigrecordingbuffer = 0;

// check if CLI receiving mode enabled
int receivingmode = 0;

// check if CLI jamming mode enabled
int jammingmode = 0;

// check if CLI recording mode enabled
int recordingmode = 0;

// check if CLI chat mode enabled
int chatmode = 0;

static bool do_echo = true;

// buffer for receiving  CC1101
byte ccreceivingbuffer[CCBUFFERSIZE] = {0};

// buffer for sending  CC1101
byte ccsendingbuffer[CCBUFFERSIZE] = {0};
// char ccsendingbuffer[CCBUFFERSIZE] = {0};

// buffer for recording and replaying of many frames
byte bigrecordingbuffer[RECORDINGBUFFERSIZE] = {0};

// buffer for hex to ascii conversions
byte textbuffer[BUF_LENGTH];
// char textbuffer[BUF_LENGTH];

// convert bytes in table to string with hex numbers
void asciitohex(byte *ascii_ptr, byte *hex_ptr, int len) {
    byte i, j, k;
    for (i = 0; i < len; i++) {
        // high byte first
        j = ascii_ptr[i] / 16;
        if (j > 9) {
            k = j - 10 + 65;
        } else {
            k = j + 48;
        }
        hex_ptr[2 * i] = k;
        // low byte second
        j = ascii_ptr[i] % 16;
        if (j > 9) {
            k = j - 10 + 65;
        } else {
            k = j + 48;
        }
        hex_ptr[(2 * i) + 1] = k;
    };
    hex_ptr[(2 * i) + 2] = '\0';
}

// convert string with hex numbers to array of bytes
void hextoascii(byte *ascii_ptr, byte *hex_ptr, int len) {
    byte i, j;
    for (i = 0; i < (len / 2); i++) {
        j = hex_ptr[i * 2];
        if ((j > 47) && (j < 58)) ascii_ptr[i] = (j - 48) * 16;
        if ((j > 64) && (j < 71)) ascii_ptr[i] = (j - 55) * 16;
        if ((j > 96) && (j < 103)) ascii_ptr[i] = (j - 87) * 16;
        j = hex_ptr[i * 2 + 1];
        if ((j > 47) && (j < 58)) ascii_ptr[i] = ascii_ptr[i] + (j - 48);
        if ((j > 64) && (j < 71)) ascii_ptr[i] = ascii_ptr[i] + (j - 55);
        if ((j > 96) && (j < 103)) ascii_ptr[i] = ascii_ptr[i] + (j - 87);
    };
    ascii_ptr[i++] = '\0';
}

// Initialize CC1101 board with default settings, you may change your preferences here
static void cc1101initialize(void) {
    // initializing library with custom pins selected
    ELECHOUSE_cc1101.setSpiPin(sck, miso, mosi, ss);
    // ELECHOUSE_cc1101.setGDO(gdo0, gdo2);

    // Main part to tune CC1101 with proper frequency, modulation and encoding
    ELECHOUSE_cc1101.Init();                 // must be set to initialize the cc1101!
    ELECHOUSE_cc1101.setGDO0(gdo0);          // set lib internal gdo pin (gdo0). Gdo2 not use for this example.
    ELECHOUSE_cc1101.setCCMode(1);           // set config for internal transmission mode. value 0 is for RAW recording/replaying
    ELECHOUSE_cc1101.setModulation(2);       // set modulation mode. 0 = 2-FSK, 1 = GFSK, 2 = ASK/OOK, 3 = 4-FSK, 4 = MSK.
    ELECHOUSE_cc1101.setMHZ(433.92);         // Here you can set your basic frequency. The lib calculates the frequency automatically (default = 433.92).The cc1101 can: 300-348 MHZ, 387-464MHZ and 779-928MHZ. Read More info from datasheet.
    ELECHOUSE_cc1101.setDeviation(47.60);    // Set the Frequency deviation in kHz. Value from 1.58 to 380.85. Default is 47.60 kHz.
    ELECHOUSE_cc1101.setChannel(0);          // Set the Channelnumber from 0 to 255. Default is cahnnel 0.
    ELECHOUSE_cc1101.setChsp(199.95);        // The channel spacing is multiplied by the channel number CHAN and added to the base frequency in kHz. Value from 25.39 to 405.45. Default is 199.95 kHz.
    ELECHOUSE_cc1101.setRxBW(812.50);        // Set the Receive Bandwidth in kHz. Value from 58.03 to 812.50. Default is 812.50 kHz.
    ELECHOUSE_cc1101.setDRate(9.6);          // Set the Data Rate in kBaud. Value from 0.02 to 1621.83. Default is 99.97 kBaud!
    ELECHOUSE_cc1101.setPA(10);              // Set TxPower. The following settings are possible depending on the frequency band.  (-30  -20  -15  -10  -6    0    5    7    10   11   12) Default is max!
    ELECHOUSE_cc1101.setSyncMode(2);         // Combined sync-word qualifier mode. 0 = No preamble/sync. 1 = 16 sync word bits detected. 2 = 16/16 sync word bits detected. 3 = 30/32 sync word bits detected. 4 = No preamble/sync, carrier-sense above threshold. 5 = 15/16 + carrier-sense above threshold. 6 = 16/16 + carrier-sense above threshold. 7 = 30/32 + carrier-sense above threshold.
    ELECHOUSE_cc1101.setSyncWord(211, 145);  // Set sync word. Must be the same for the transmitter and receiver. Default is 211,145 (Syncword high, Syncword low)
    ELECHOUSE_cc1101.setAdrChk(0);           // Controls address check configuration of received packages. 0 = No address check. 1 = Address check, no broadcast. 2 = Address check and 0 (0x00) broadcast. 3 = Address check and 0 (0x00) and 255 (0xFF) broadcast.
    ELECHOUSE_cc1101.setAddr(0);             // Address used for packet filtration. Optional broadcast addresses are 0 (0x00) and 255 (0xFF).
    ELECHOUSE_cc1101.setWhiteData(0);        // Turn data whitening on / off. 0 = Whitening off. 1 = Whitening on.
    ELECHOUSE_cc1101.setPktFormat(0);        // Format of RX and TX data. 0 = Normal mode, use FIFOs for RX and TX. 1 = Synchronous serial mode, Data in on GDO0 and data out on either of the GDOx pins. 2 = Random TX mode; sends random data using PN9 generator. Used for test. Works as normal mode, setting 0 (00), in RX. 3 = Asynchronous serial mode, Data in on GDO0 and data out on either of the GDOx pins.
    ELECHOUSE_cc1101.setLengthConfig(1);     // 0 = Fixed packet length mode. 1 = Variable packet length mode. 2 = Infinite packet length mode. 3 = Reserved
    ELECHOUSE_cc1101.setPacketLength(0);     // Indicates the packet length when fixed packet length mode is enabled. If variable packet length mode is used, this value indicates the maximum packet length allowed.
    ELECHOUSE_cc1101.setCrc(0);              // 1 = CRC calculation in TX and CRC check in RX enabled. 0 = CRC disabled for TX and RX.
    ELECHOUSE_cc1101.setCRC_AF(0);           // Enable automatic flush of RX FIFO when CRC is not OK. This requires that only one packet is in the RXIFIFO and that packet length is limited to the RX FIFO size.
    ELECHOUSE_cc1101.setDcFilterOff(0);      // Disable digital DC blocking filter before demodulator. Only for data rates ≤ 250 kBaud The recommended IF frequency changes when the DC blocking is disabled. 1 = Disable (current optimized). 0 = Enable (better sensitivity).
    ELECHOUSE_cc1101.setManchester(0);       // Enables Manchester encoding/decoding. 0 = Disable. 1 = Enable.
    ELECHOUSE_cc1101.setFEC(0);              // Enable Forward Error Correction (FEC) with interleaving for packet payload (Only supported for fixed packet length mode. 0 = Disable. 1 = Enable.
    ELECHOUSE_cc1101.setPRE(0);              // Sets the minimum number of preamble bytes to be transmitted. Values: 0 : 2, 1 : 3, 2 : 4, 3 : 6, 4 : 8, 5 : 12, 6 : 16, 7 : 24
    ELECHOUSE_cc1101.setPQT(0);              // Preamble quality estimator threshold. The preamble quality estimator increases an internal counter by one each time a bit is received that is different from the previous bit, and decreases the counter by 8 each time a bit is received that is the same as the last bit. A threshold of 4∙PQT for this counter is used to gate sync word detection. When PQT=0 a sync word is always accepted.
    ELECHOUSE_cc1101.setAppendStatus(0);     // When enabled, two status bytes will be appended to the payload of the packet. The status bytes contain RSSI and LQI values, as well as CRC OK.
}

// Execute a complete CC1101 command.

static void exec(char *cmdline) {
    char *command = strsep(&cmdline, " ");
    int setting, setting2, len;
    uint16_t brute, poweroftwo;
    byte j, k;
    float settingf1;
    float settingf2;
    // variables for frequency scanner
    float freq;
    long compare_freq;
    float mark_freq;
    int rssi;
    int mark_rssi = -100;

    // identification of the command & actions

    if (strcmp_P(command, PSTR("help")) == 0) {
        Serial.println(F(
            "setmodulation <mode> : Set modulation mode. 0 = 2-FSK, 1 = GFSK, 2 = ASK/OOK, 3 = 4-FSK, 4 = MSK.\r\n\r\n"
            "setmhz <frequency>   : Here you can set your basic frequency. default = 433.92).The cc1101 can: 300-348 MHZ, 387-464MHZ and 779-928MHZ.\r\n\r\n"
            "setdeviation <deviation> : Set the Frequency deviation in kHz. Value from 1.58 to 380.85.\r\n\r\n"
            "setchannel <channel> : Set the Channelnumber from 0 to 255. Default is cahnnel 0.\r\n\r\n"
            "setchsp <spacing>  :  The channel spacing is multiplied by the channel number CHAN and added to the base frequency in kHz. Value from 25.39 to 405.45. \r\n\r\n"
            "setrxbw <Receive bndwth> : Set the Receive Bandwidth in kHz. Value from 58.03 to 812.50. \r\n\r\n"
            "setdrate <datarate> : Set the Data Rate in kBaud. Value from 0.02 to 1621.83.\r\n\r\n"
            "setpa <power value> : Set RF transmission power. The following settings are possible depending on the frequency band.  (-30  -20  -15  -10  -6    0    5    7    10   11   12) Default is max!\r\n\r\n"
            "setsyncmode  <sync mode> : Combined sync-word qualifier mode. 0 = No preamble/sync. 1 = 16 sync word bits detected. 2 = 16/16 sync word bits detected. 3 = 30/32 sync word bits detected. 4 = No preamble/sync, carrier-sense above threshold. 5 = 15/16 + carrier-sense above threshold. 6 = 16/16 + carrier-sense above threshold. 7 = 30/32 + carrier-sense above threshold.\r\n"));
        Serial.println(F(
            "setsyncword <decimal LOW, decimal HIGH> : Set sync word. Must be the same for the transmitter and receiver. (Syncword high, Syncword low) Default is 211,145\r\n\r\n"
            "setadrchk <address chk> : Controls address check configuration of received packages. 0 = No address check. 1 = Address check, no broadcast. 2 = Address check and 0 (0x00) broadcast. 3 = Address check and 0 (0x00) and 255 (0xFF) broadcast.\r\n\r\n"
            "setaddr <address> : Address used for packet filtration. Optional broadcast addresses are 0 (0x00) and 255 (0xFF).\r\n\r\n"
            "setwhitedata <whitening> : Turn data whitening on / off. 0 = Whitening off. 1 = Whitening on.\r\n\r\n"
            "setpktformat <pktformat> : Format of RX and TX data. 0 = Normal mode, use FIFOs for RX and TX. 1 = Synchronous serial mode, Data in on GDO0 and data out on either of the GDOx pins. 2 = Random TX mode; sends random data using PN9 generator.  3 = Asynchronous serial mode\r\n\r\n"
            "setlengthconfig <mode> : Set packet Length mode : 0 = Fixed packet length mode. 1 = Variable packet length mode. 2 = Infinite packet length mode. 3 = Reserved \r\n\r\n"
            "setpacketlength <mode> : Indicates the packet length when fixed packet length mode is enabled. If variable packet length mode is used, this value indicates the maximum packet length allowed.\r\n\r\n"
            "setcrc <mode> : Switches on/of CRC calculation and check. 1 = CRC calculation in TX and CRC check in RX enabled. 0 = CRC disabled for TX and RX.\r\n\r\n"
            "setcrcaf <mode> : Enable automatic flush of RX FIFO when CRC is not OK. This requires that only one packet is in the RXIFIFO and that packet length is limited to the RX FIFO size.\r\n"));
        Serial.println(F(
            "setdcfilteroff <mode> : Disable digital DC blocking filter before demodulator. Only for data rates ≤ 250 kBaud The recommended IF frequency changes when the DC blocking is disabled. 1 = Disable (current optimized). 0 = Enable (better sensitivity).\r\n\r\n"
            "setmanchester <mode> : Enables Manchester encoding/decoding. 0 = Disable. 1 = Enable.\r\n\r\n"
            "setfec <mode> : Enable Forward Error Correction (FEC) with interleaving for packet payload (Only supported for fixed packet length mode. 0 = Disable. 1 = Enable.\r\n\r\n"
            "setpre <mode> : Sets the minimum number of preamble bytes to be transmitted. Values: 0 : 2, 1 : 3, 2 : 4, 3 : 6, 4 : 8, 5 : 12, 6 : 16, 7 : 24\r\n\r\n"
            "setpqt <mode> : Preamble quality estimator threshold. \r\n\r\n"
            "setappendstatus <mode> : When enabled, two status bytes will be appended to the payload of the packet. The status bytes contain RSSI and LQI values, as well as CRC OK.\r\n\r\n"
            "getrssi : Display quality information about last received frames over RF\r\n\r\n"
            "scan <start> <stop> : Scan frequency range for the highest signal.\r\n\r\n"
            "chat :  Enable chat mode between many devices. No exit available, disconnect device to quit\r\n"));
        Serial.println(F(
            "rx : Sniffer. Enable or disable printing of received RF packets on serial terminal.\r\n\r\n"
            "tx <hex-vals> : Send packet of max 60 bytes <hex values> over RF\r\n\r\n"
            "jam : Enable or disable continous jamming on selected band.\r\n\r\n"
            "brute <microseconds> <number-of-bits> : Brute force garage gate with <nb-of-bits> keyword where symbol time is <usec>.\r\n\r\n"
            "rec : Enable or disable recording frames in the buffer.\r\n\r\n"
            "add <hex-vals> : Manually add single frame payload (max 64 hex values) to the buffer so it can be replayed\r\n\r\n"
            "show : Show content of recording buffer\r\n\r\n"
            "flush : Clear the recording buffer\r\n\r\n"
            "play <N> : Replay 0 = all frames or N-th recorded frame previously stored in the buffer.\r\n\r\n"
            "rxraw <microseconds> : Sniffs radio by sampling with <microsecond> interval and prints received bytes in hex.\r\n\r\n"
            "recraw <microseconds> : Recording RAW RF data with <microsecond> sampling interval.\r\n"));
        Serial.println(F(
            "addraw <hex-vals> : Manually add chunks (max 60 hex values) to the buffer so they can be further replayed.\r\n\r\n"
            "showraw : Showing content of recording buffer in RAW format.\r\n\r\n"
            "playraw <microseconds> : Replaying previously recorded RAW RF data with <microsecond> sampling interval.\r\n\r\n"
            "showbit : Showing content of recording buffer in RAW format as a stream of bits.\r\n\r\n"
            "save : Store recording buffer content in non-volatile memory\r\n\r\n"
            "load : Load the content from non-volatile memory to the recording buffer\r\n\r\n"
            "echo <mode> : Enable or disable Echo on serial terminal. 1 = enabled, 0 = disabled\r\n\r\n"
            "x : Stops jamming/receiving/recording packets.\r\n\r\n"
            "init : Restarts CC1101 board with default parameters\r\n\r\n"));

        // Handling SETMODULATION command
    } else if (strcmp_P(command, PSTR("setmodulation")) == 0) {
        setting = atoi(cmdline);
        ELECHOUSE_cc1101.setModulation(setting);
        Serial.print(F("\r\nModulation: "));
        if (setting == 0) {
            Serial.print(F("2-FSK"));
        } else if (setting == 1) {
            Serial.print(F("GFSK"));
        } else if (setting == 2) {
            Serial.print(F("ASK/OOK"));
        } else if (setting == 3) {
            Serial.print(F("4-FSK"));
        } else if (setting == 4) {
            Serial.print(F("MSK"));
        };
        Serial.print(F(" \r\n"));

        // Handling SETMHZ command
    } else if (strcmp_P(command, PSTR("setmhz")) == 0) {
        settingf1 = atof(cmdline);
        ELECHOUSE_cc1101.setMHZ(settingf1);
        Serial.print(F("\r\nFrequency: "));
        Serial.print(settingf1);
        Serial.print(F(" MHz\r\n"));

        // Handling SETDEVIATION command
    } else if (strcmp_P(command, PSTR("setdeviation")) == 0) {
        settingf1 = atof(cmdline);
        ELECHOUSE_cc1101.setDeviation(settingf1);
        Serial.print(F("\r\nDeviation: "));
        Serial.print(settingf1);
        Serial.print(F(" KHz\r\n"));

        // Handling SETCHANNEL command
    } else if (strcmp_P(command, PSTR("setchannel")) == 0) {
        setting = atoi(cmdline);
        ELECHOUSE_cc1101.setChannel(setting);
        Serial.print(F("\r\nChannel:"));
        Serial.print(setting);
        Serial.print(F("\r\n"));

        // Handling SETCHSP command
    } else if (strcmp_P(command, PSTR("setchsp")) == 0) {
        settingf1 = atof(cmdline);
        ELECHOUSE_cc1101.setChsp(settingf1);
        Serial.print(F("\r\nChann spacing: "));
        Serial.print(settingf1);
        Serial.print(F(" kHz\r\n"));

        // Handling SETRXBW command
    } else if (strcmp_P(command, PSTR("setrxbw")) == 0) {
        settingf1 = atof(cmdline);
        ELECHOUSE_cc1101.setRxBW(settingf1);
        Serial.print(F("\r\nRX bandwidth: "));
        Serial.print(settingf1);
        Serial.print(F(" kHz \r\n"));

        // Handling SETDRATE command
    } else if (strcmp_P(command, PSTR("setdrate")) == 0) {
        settingf1 = atof(cmdline);
        ELECHOUSE_cc1101.setDRate(settingf1);
        Serial.print(F("\r\nDatarate: "));
        Serial.print(settingf1);
        Serial.print(F(" kbaud\r\n"));

        // Handling SETPA command
    } else if (strcmp_P(command, PSTR("setpa")) == 0) {
        setting = atoi(cmdline);
        ELECHOUSE_cc1101.setPA(setting);
        Serial.print(F("\r\nTX PWR: "));
        Serial.print(setting);
        Serial.print(F(" dBm\r\n"));

        // Handling SETSYNCMODE command
    } else if (strcmp_P(command, PSTR("setsyncmode")) == 0) {
        int setting = atoi(cmdline);
        ELECHOUSE_cc1101.setSyncMode(setting);
        Serial.print(F("\r\nSynchronization: "));
        if (setting == 0) {
            Serial.print(F("No preamble"));
        } else if (setting == 1) {
            Serial.print(F("16 sync bits"));
        } else if (setting == 2) {
            Serial.print(F("16/16 sync bits"));
        } else if (setting == 3) {
            Serial.print(F("30/32 sync bits"));
        } else if (setting == 4) {
            Serial.print(F("No preamble/sync, carrier-sense"));
        } else if (setting == 5) {
            Serial.print(F("15/16 + carrier-sense"));
        } else if (setting == 6) {
            Serial.print(F("16/16 + carrier-sense"));
        } else if (setting == 7) {
            Serial.print(F("30/32 + carrier-sense"));
        };
        Serial.print(F("\r\n"));

        // Handling SETSYNCWORD command
    } else if (strcmp_P(command, PSTR("setsyncword")) == 0) {
        setting = atoi(strsep(&cmdline, " "));
        setting2 = atoi(cmdline);
        ELECHOUSE_cc1101.setSyncWord(setting2, setting);
        Serial.print(F("\r\nSynchronization:\r\n"));
        Serial.print(F("high = "));
        Serial.print(setting);
        Serial.print(F("\r\nlow = "));
        Serial.print(setting2);
        Serial.print(F("\r\n"));

        // Handling SETADRCHK command
    } else if (strcmp_P(command, PSTR("setadrchk")) == 0) {
        setting = atoi(cmdline);
        ELECHOUSE_cc1101.setAdrChk(setting);
        Serial.print(F("\r\nAddress checking:"));
        if (setting == 0) {
            Serial.print(F("No adr chk"));
        } else if (setting == 1) {
            Serial.print(F("Adr chk, no bcast"));
        } else if (setting == 2) {
            Serial.print(F("Adr chk and 0 bcast"));
        } else if (setting == 3) {
            Serial.print(F("Adr chk and 0 and FF bcast"));
        };
        Serial.print(F("\r\n"));

        // Handling SETADDR command
    } else if (strcmp_P(command, PSTR("setaddr")) == 0) {
        setting = atoi(cmdline);
        ELECHOUSE_cc1101.setAddr(setting);
        Serial.print(F("\r\nAddress: "));
        Serial.print(setting);
        Serial.print(F("\r\n"));

        // Handling SETWHITEDATA command
    } else if (strcmp_P(command, PSTR("setwhitedata")) == 0) {
        setting = atoi(cmdline);
        ELECHOUSE_cc1101.setWhiteData(setting);
        Serial.print(F("\r\nWhitening "));
        if (setting == 0) {
            Serial.print(F("OFF"));
        } else if (setting == 1) {
            Serial.print(F("ON"));
        }
        Serial.print(F("\r\n"));

        // Handling SETPKTFORMAT command
    } else if (strcmp_P(command, PSTR("setpktformat")) == 0) {
        setting = atoi(cmdline);
        ELECHOUSE_cc1101.setPktFormat(setting);
        Serial.print(F("\r\nPacket format: "));
        if (setting == 0) {
            Serial.print(F("Normal mode"));
        } else if (setting == 1) {
            Serial.print(F("Synchronous serial mode"));
        } else if (setting == 2) {
            Serial.print(F("Random TX mode"));
        } else if (setting == 3) {
            Serial.print(F("Asynchronous serial mode"));
        };
        Serial.print(F("\r\n"));

        // Handling SETLENGTHCONFIG command
    } else if (strcmp_P(command, PSTR("setlengthconfig")) == 0) {
        setting = atoi(cmdline);
        ELECHOUSE_cc1101.setLengthConfig(setting);
        Serial.print(F("\r\nPkt length mode: "));
        if (setting == 0) {
            Serial.print(F("Fixed"));
        } else if (setting == 1) {
            Serial.print(F("Variable"));
        } else if (setting == 2) {
            Serial.print(F("Infinite"));
        } else if (setting == 3) {
            Serial.print(F("Reserved"));
        };
        Serial.print(F("\r\n"));

        // Handling SETPACKETLENGTH command
    } else if (strcmp_P(command, PSTR("setpacketlength")) == 0) {
        setting = atoi(cmdline);
        ELECHOUSE_cc1101.setPacketLength(setting);
        Serial.print(F("\r\nPkt length: "));
        Serial.print(setting);
        Serial.print(F(" bytes\r\n"));

        // Handling SETCRC command
    } else if (strcmp_P(command, PSTR("setcrc")) == 0) {
        setting = atoi(cmdline);
        ELECHOUSE_cc1101.setCrc(setting);
        Serial.print(F("\r\nCRC checking: "));
        if (setting == 0) {
            Serial.print(F("Disabled"));
        } else if (setting == 1) {
            Serial.print(F("Enabled"));
        };
        Serial.print(F("\r\n"));

        // Handling SETCRCAF command
    } else if (strcmp_P(command, PSTR("setcrcaf")) == 0) {
        setting = atoi(cmdline);
        ELECHOUSE_cc1101.setCRC_AF(setting);
        Serial.print(F("\r\nCRC Autoflush: "));
        if (setting == 0) {
            Serial.print(F("Disabled"));
        } else if (setting == 1) {
            Serial.print(F("Enabled"));
        };
        Serial.print(F("\r\n"));
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

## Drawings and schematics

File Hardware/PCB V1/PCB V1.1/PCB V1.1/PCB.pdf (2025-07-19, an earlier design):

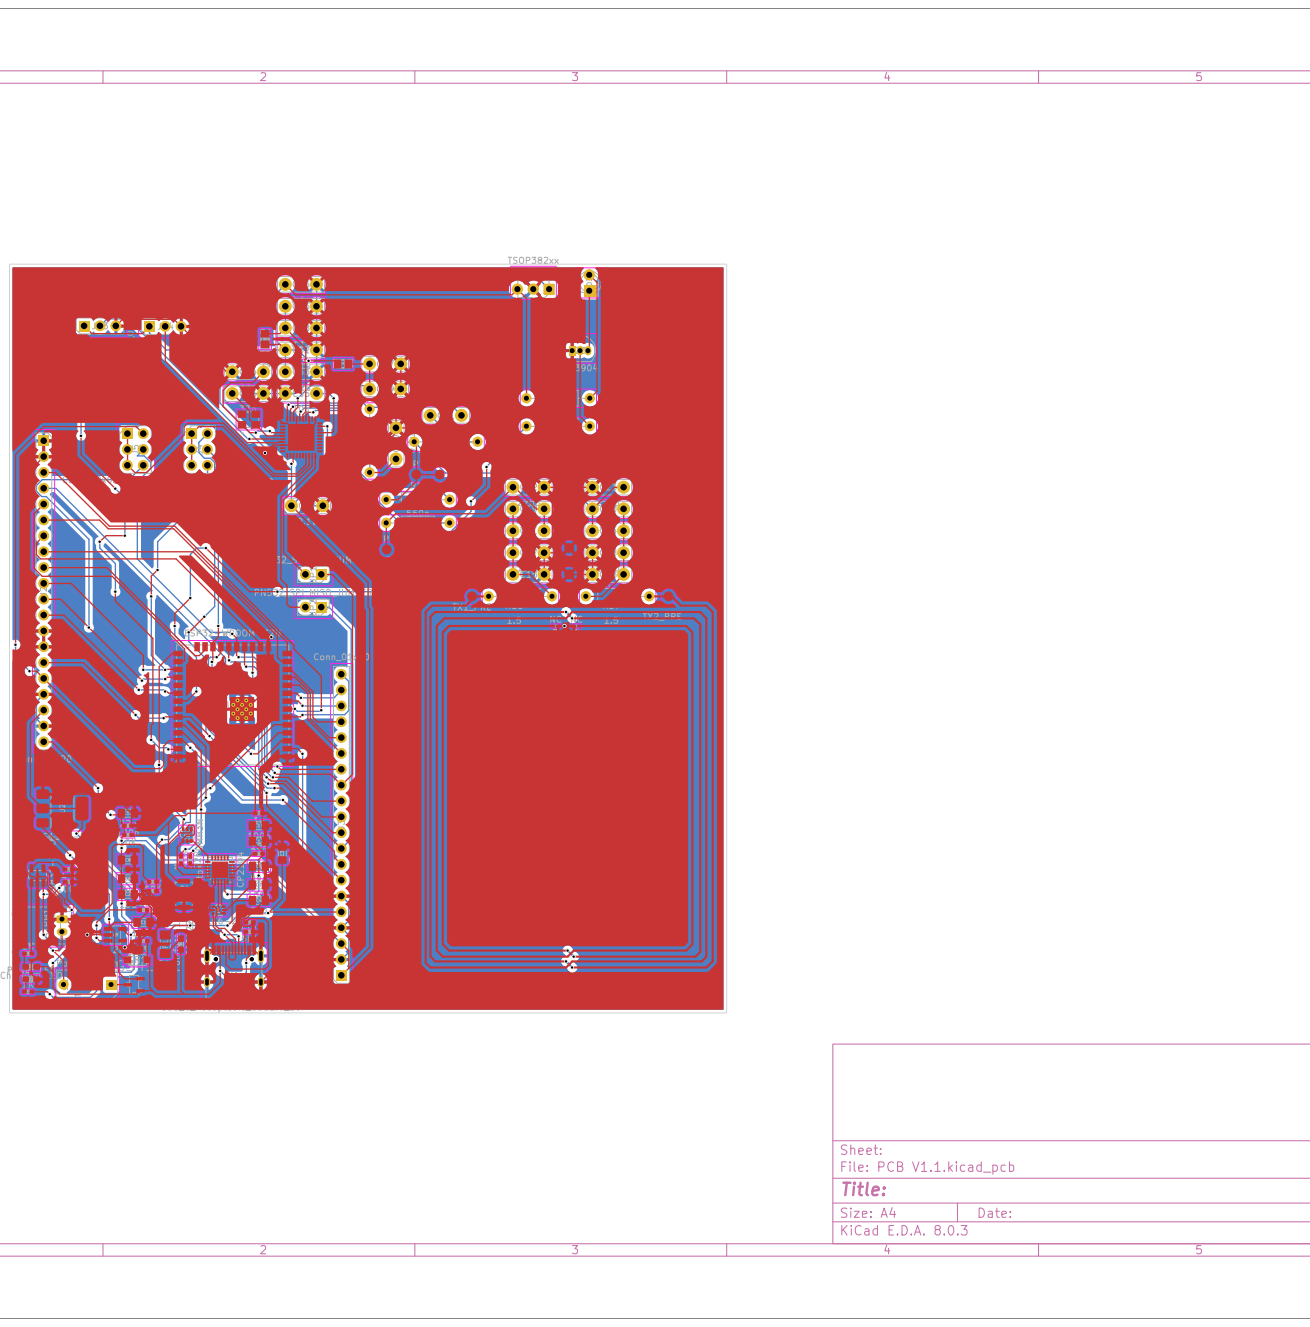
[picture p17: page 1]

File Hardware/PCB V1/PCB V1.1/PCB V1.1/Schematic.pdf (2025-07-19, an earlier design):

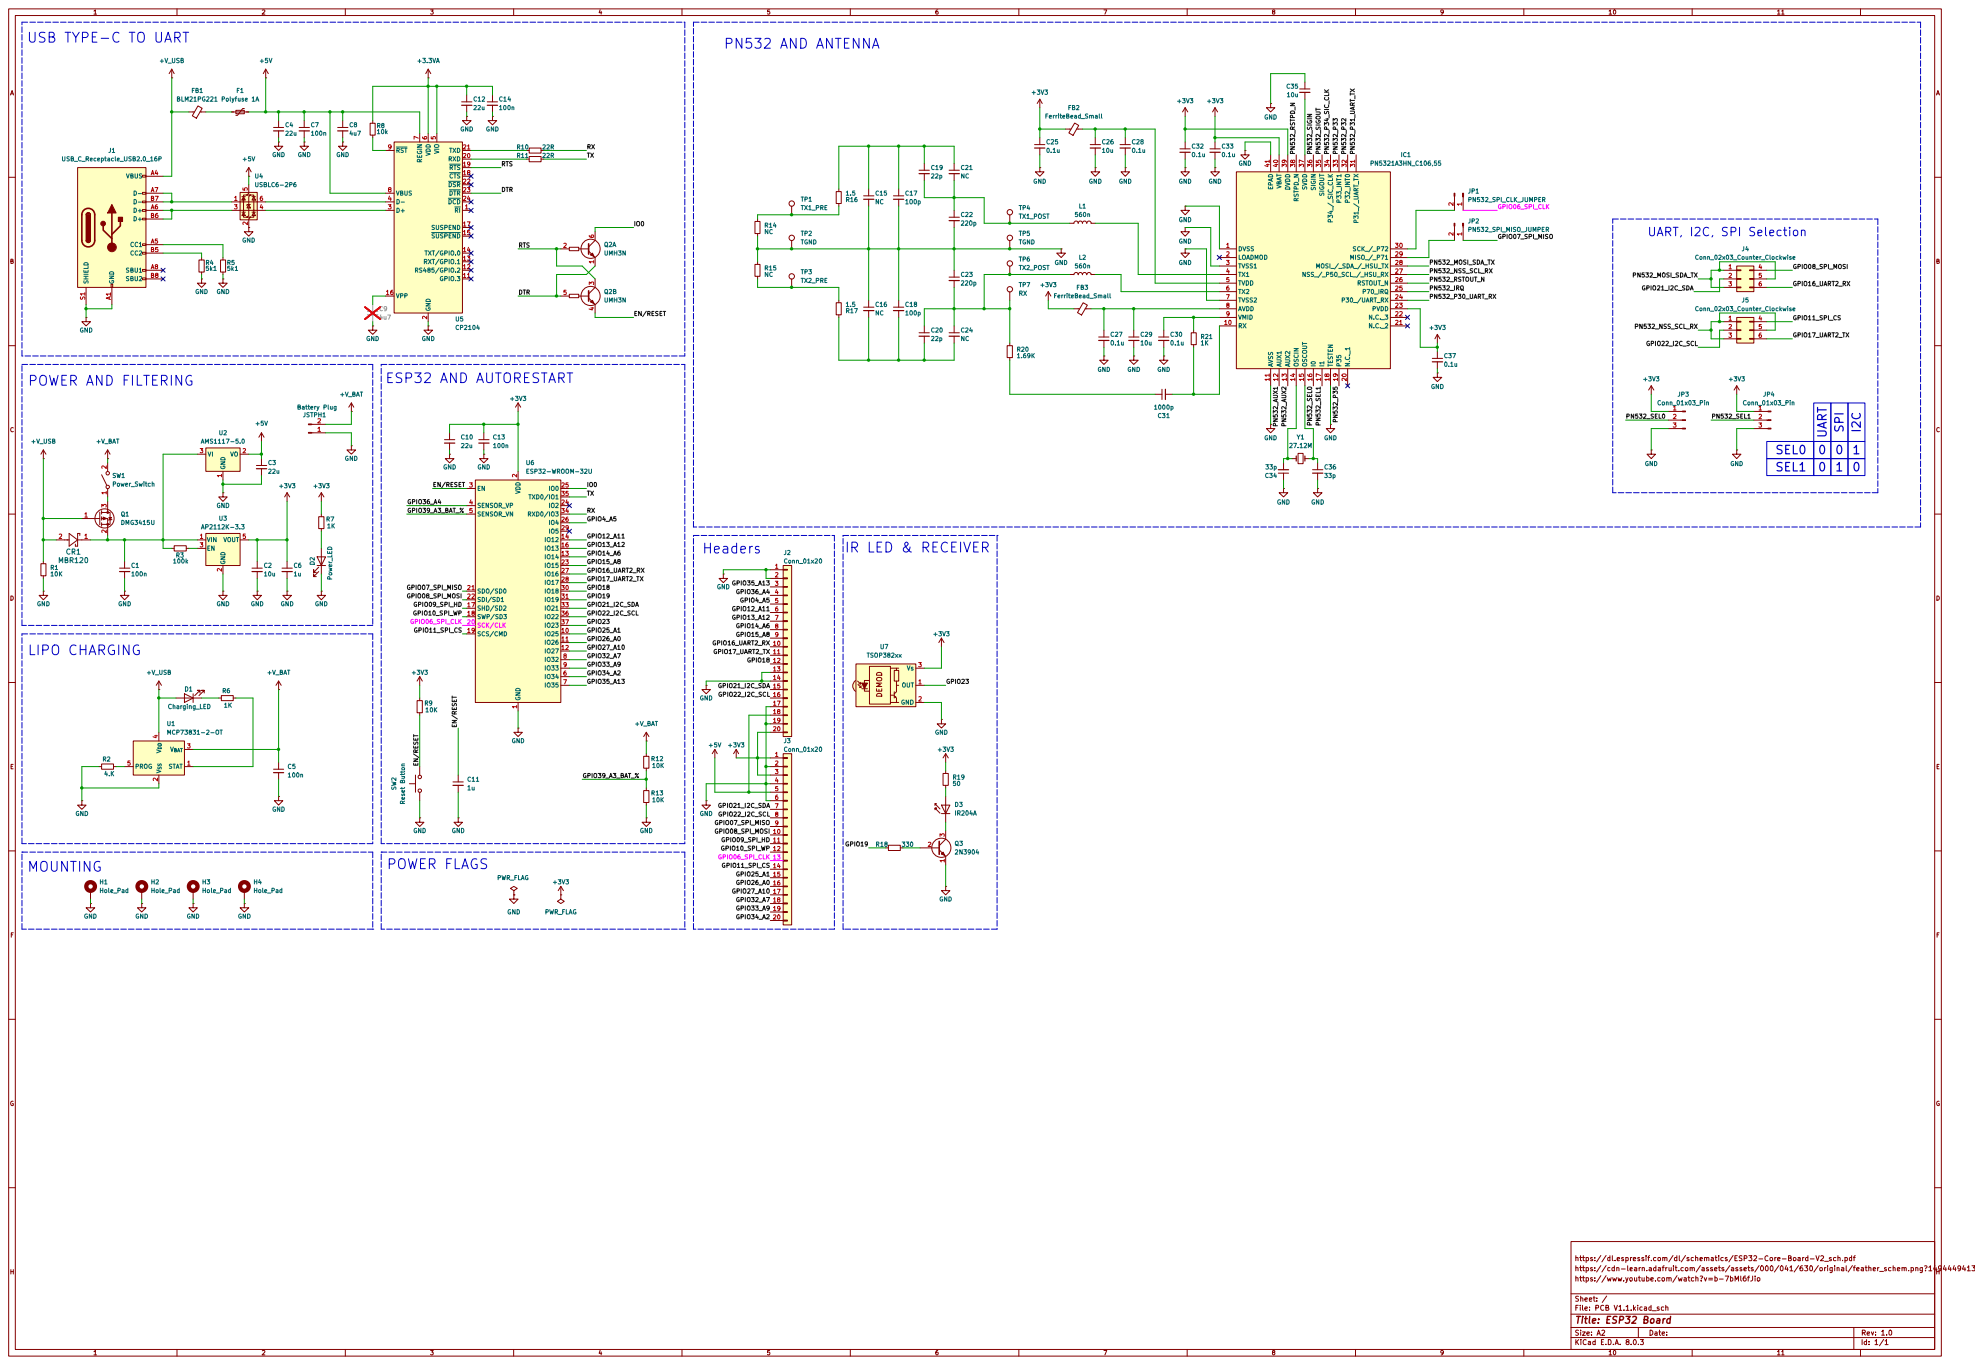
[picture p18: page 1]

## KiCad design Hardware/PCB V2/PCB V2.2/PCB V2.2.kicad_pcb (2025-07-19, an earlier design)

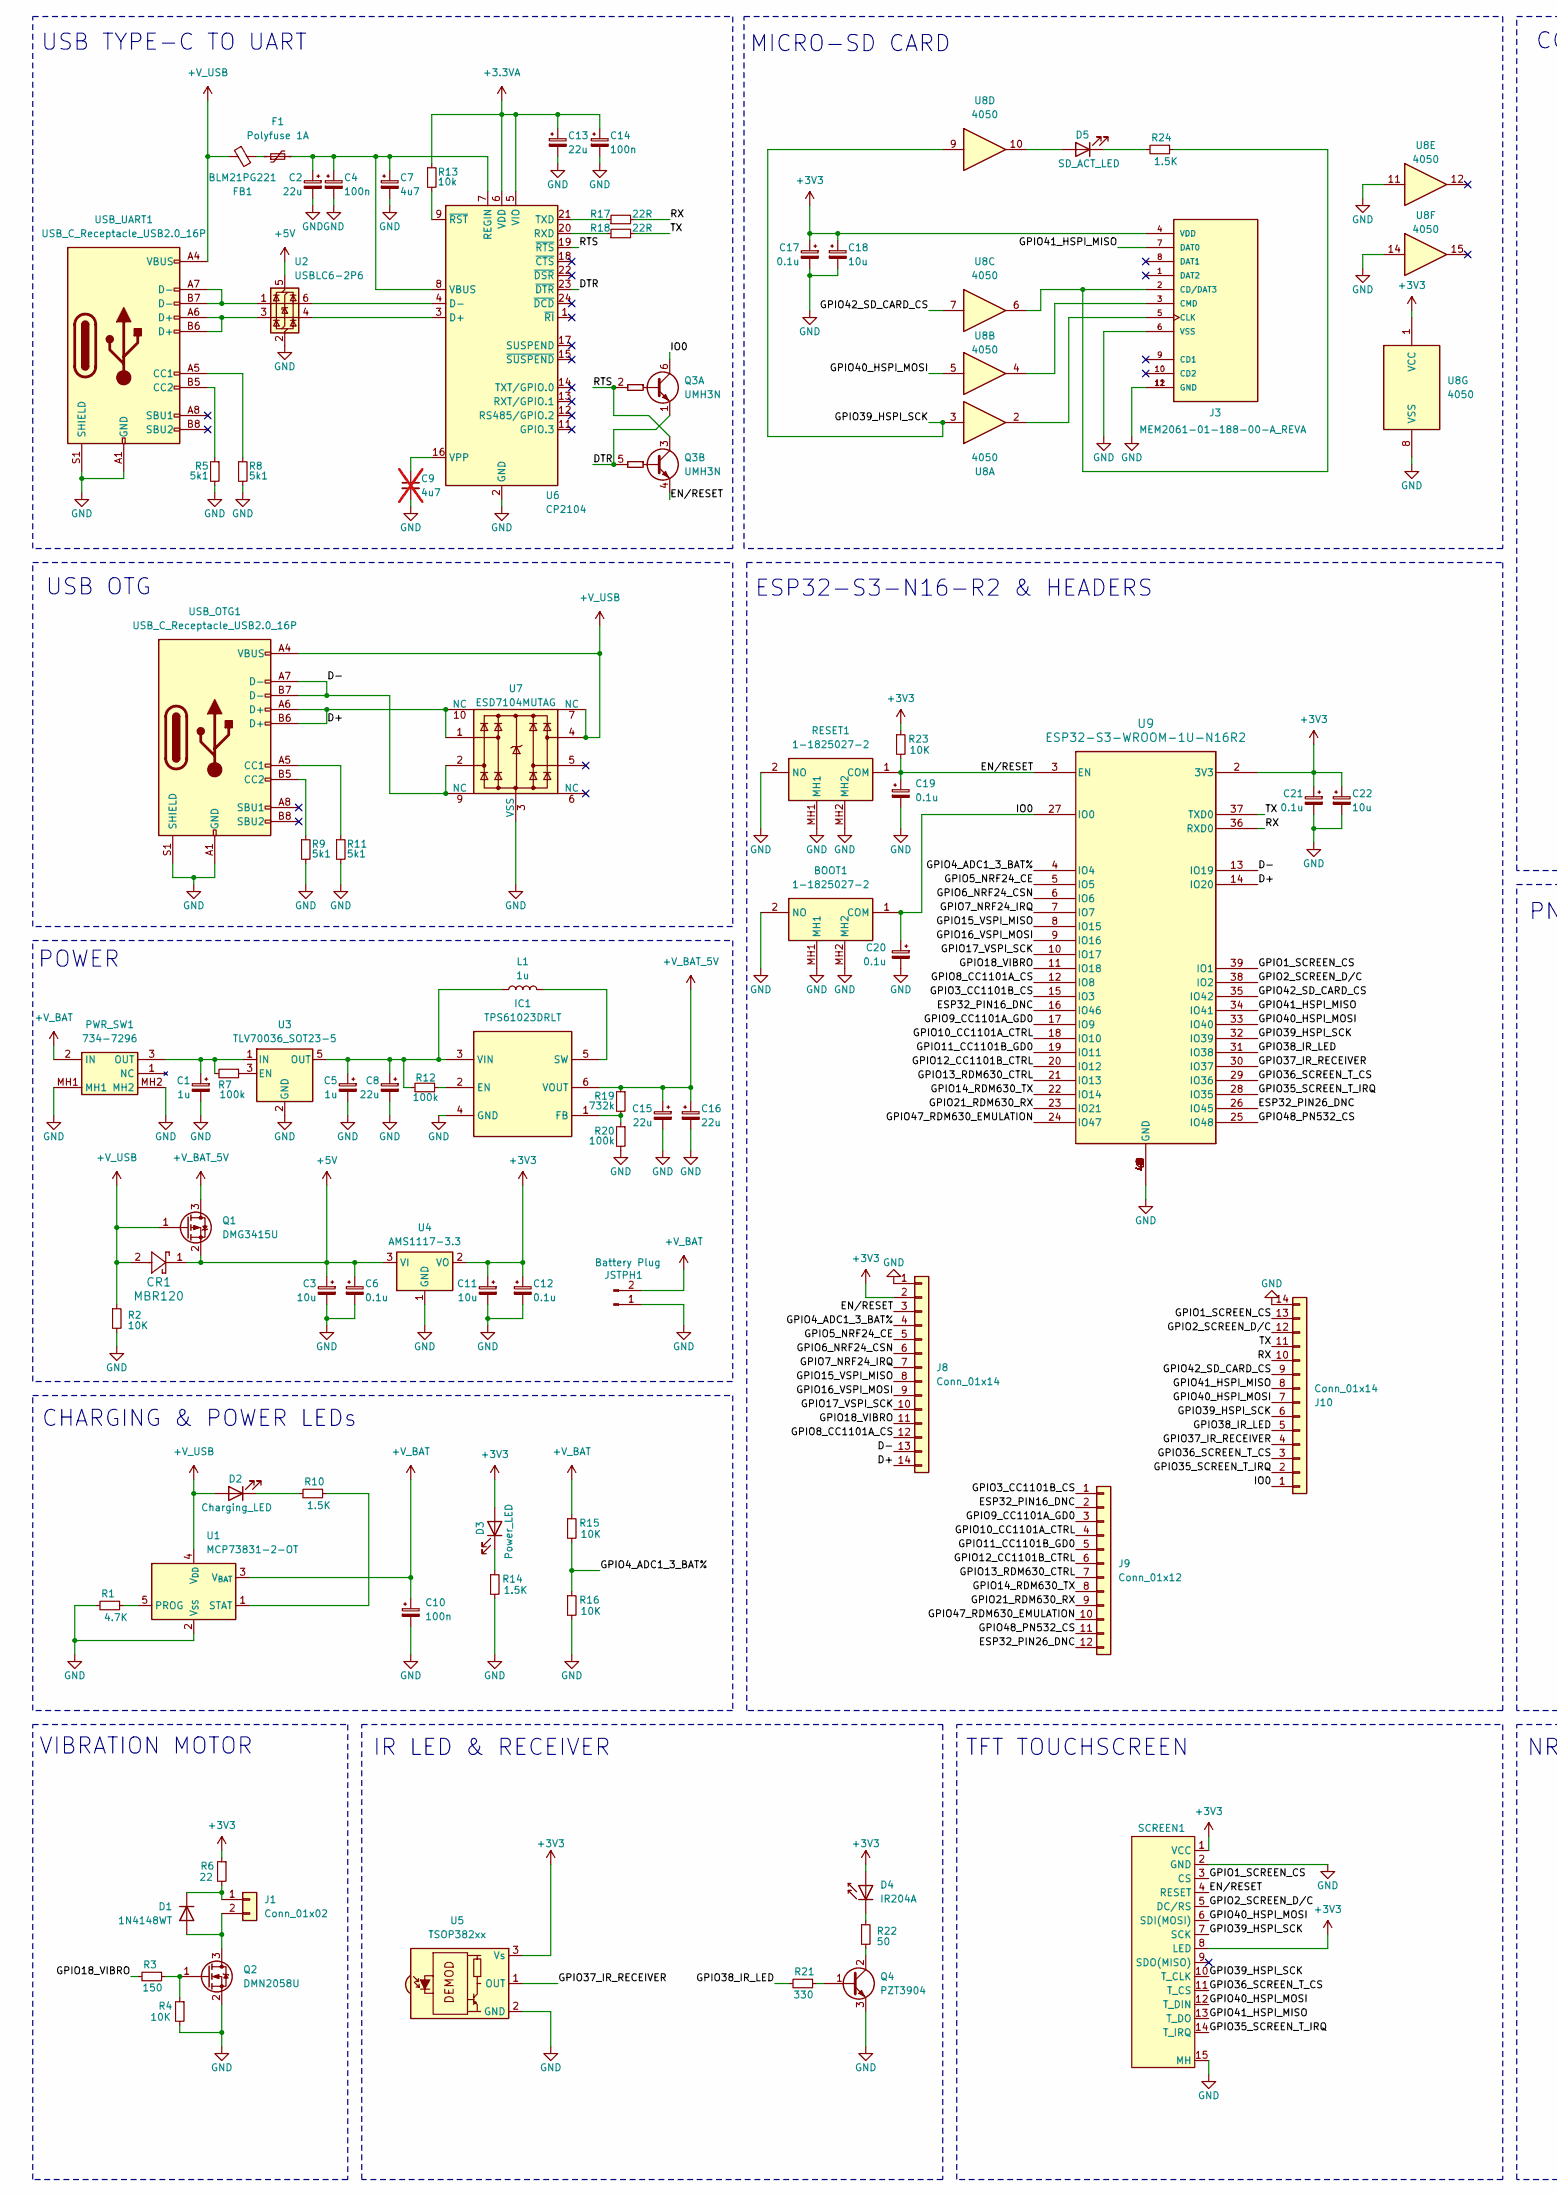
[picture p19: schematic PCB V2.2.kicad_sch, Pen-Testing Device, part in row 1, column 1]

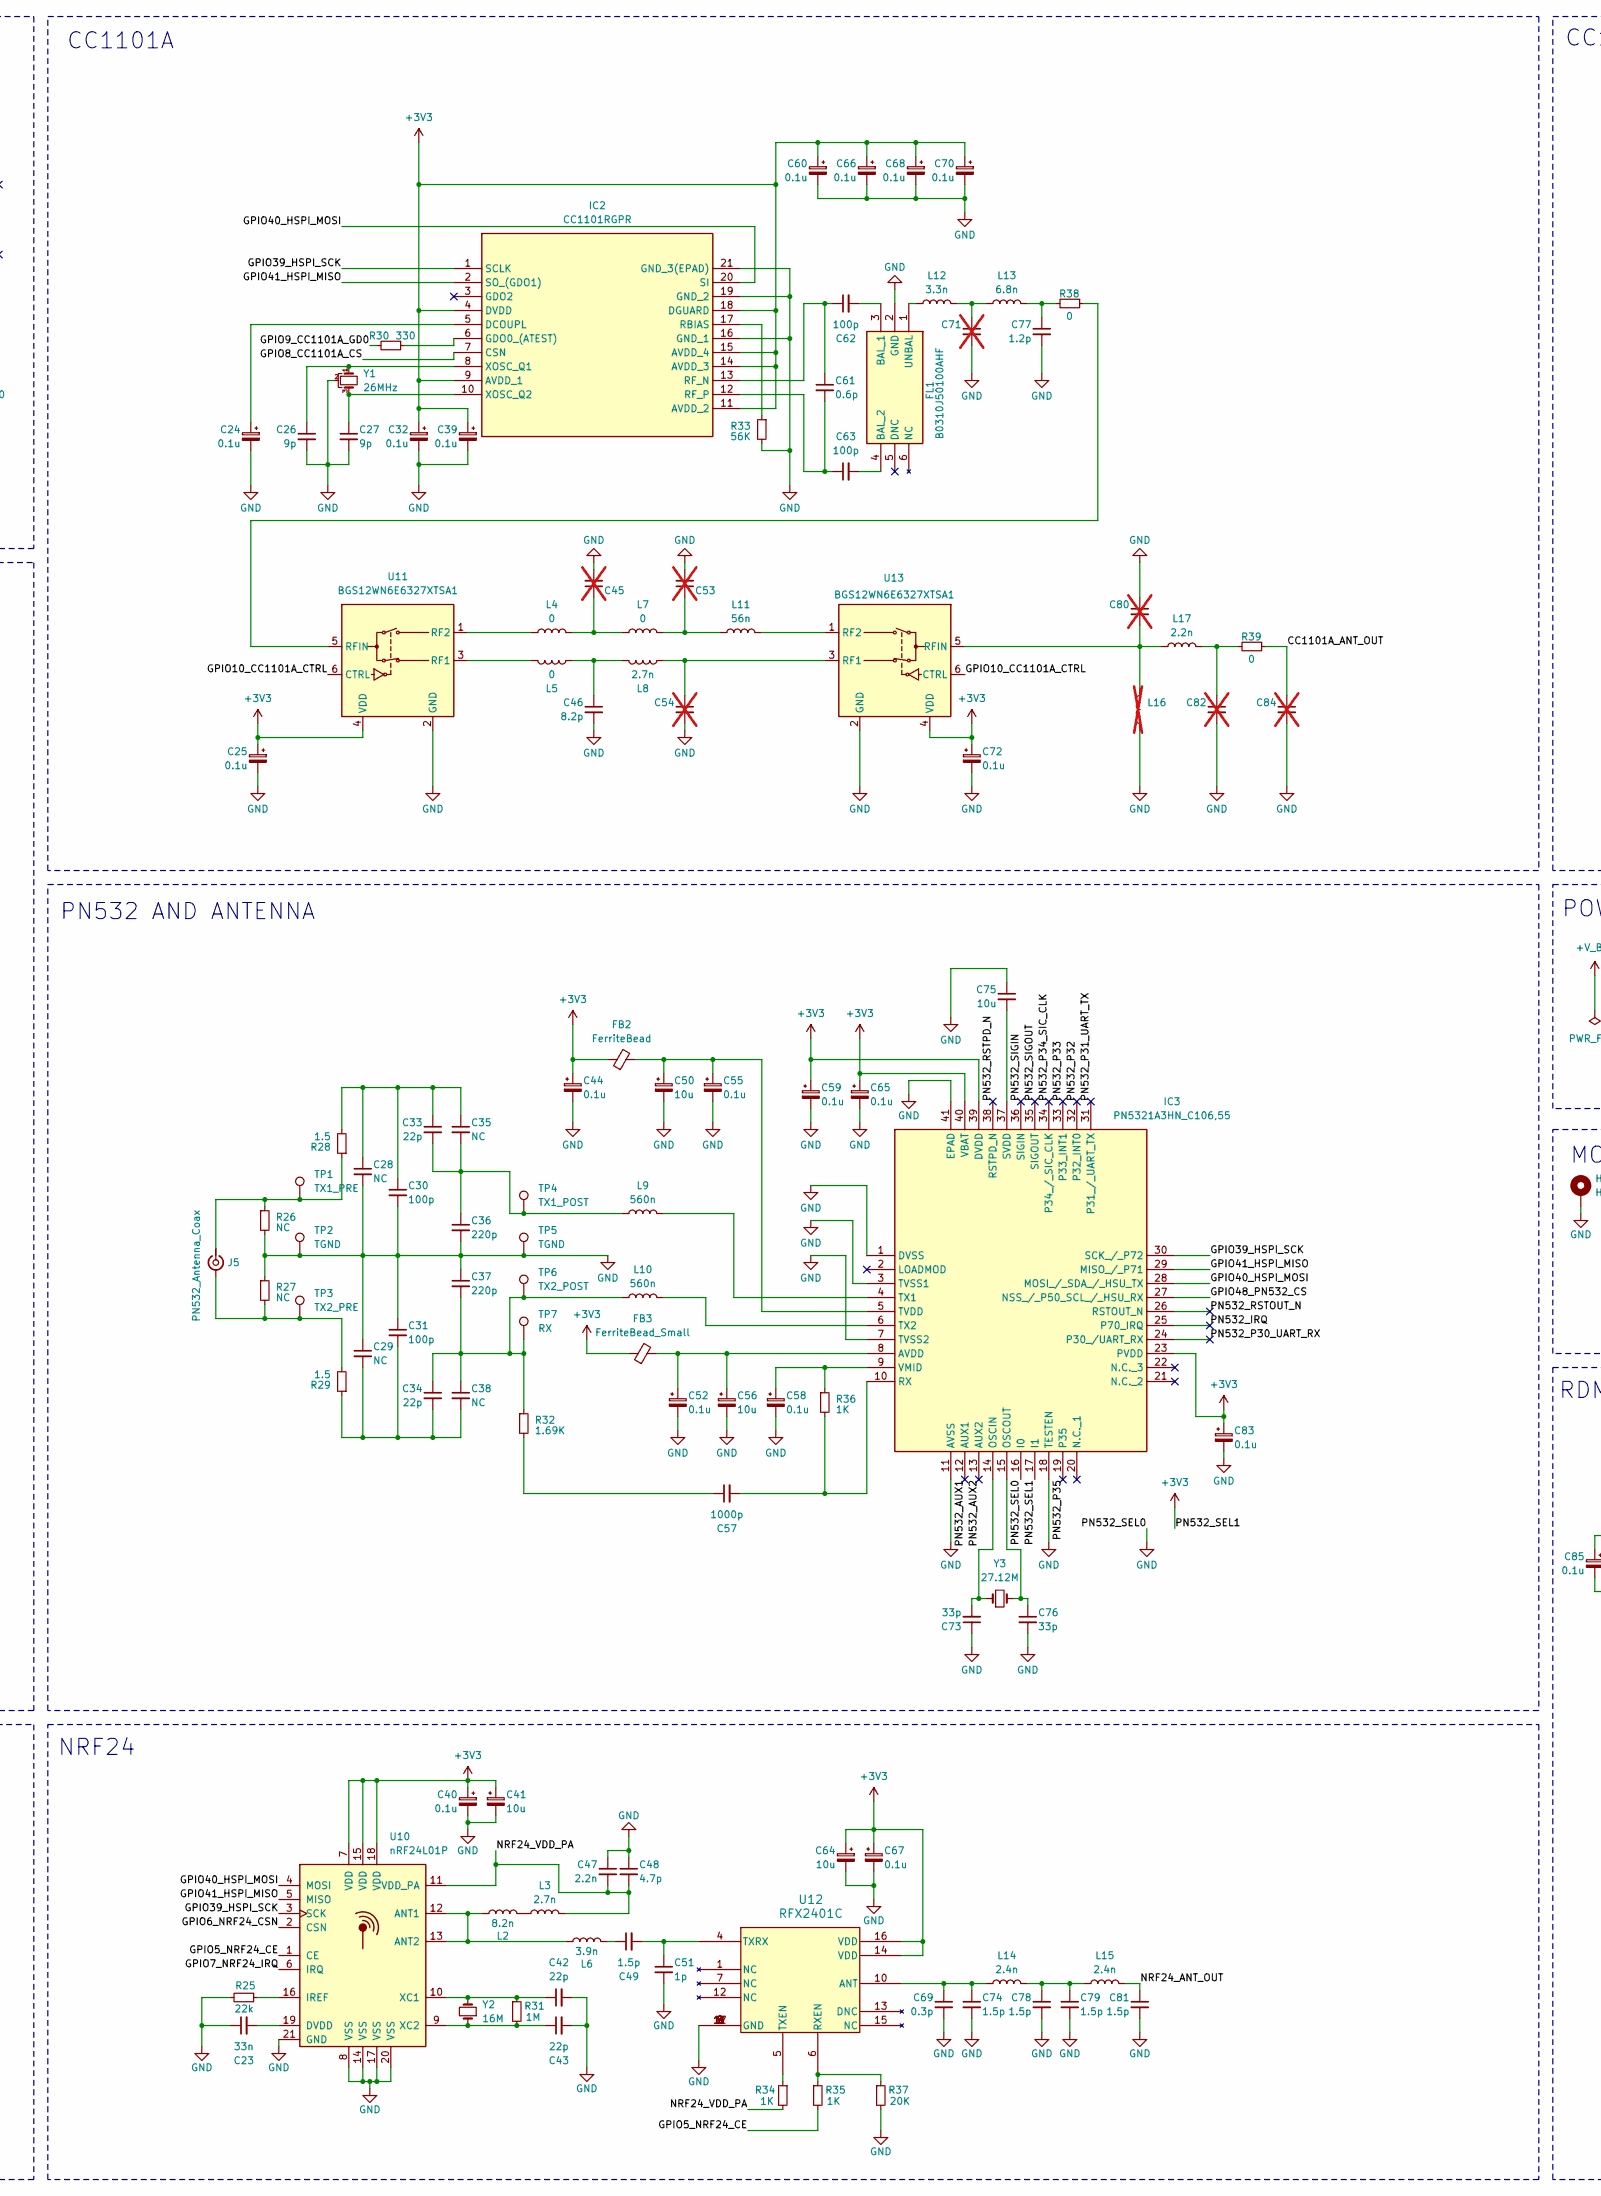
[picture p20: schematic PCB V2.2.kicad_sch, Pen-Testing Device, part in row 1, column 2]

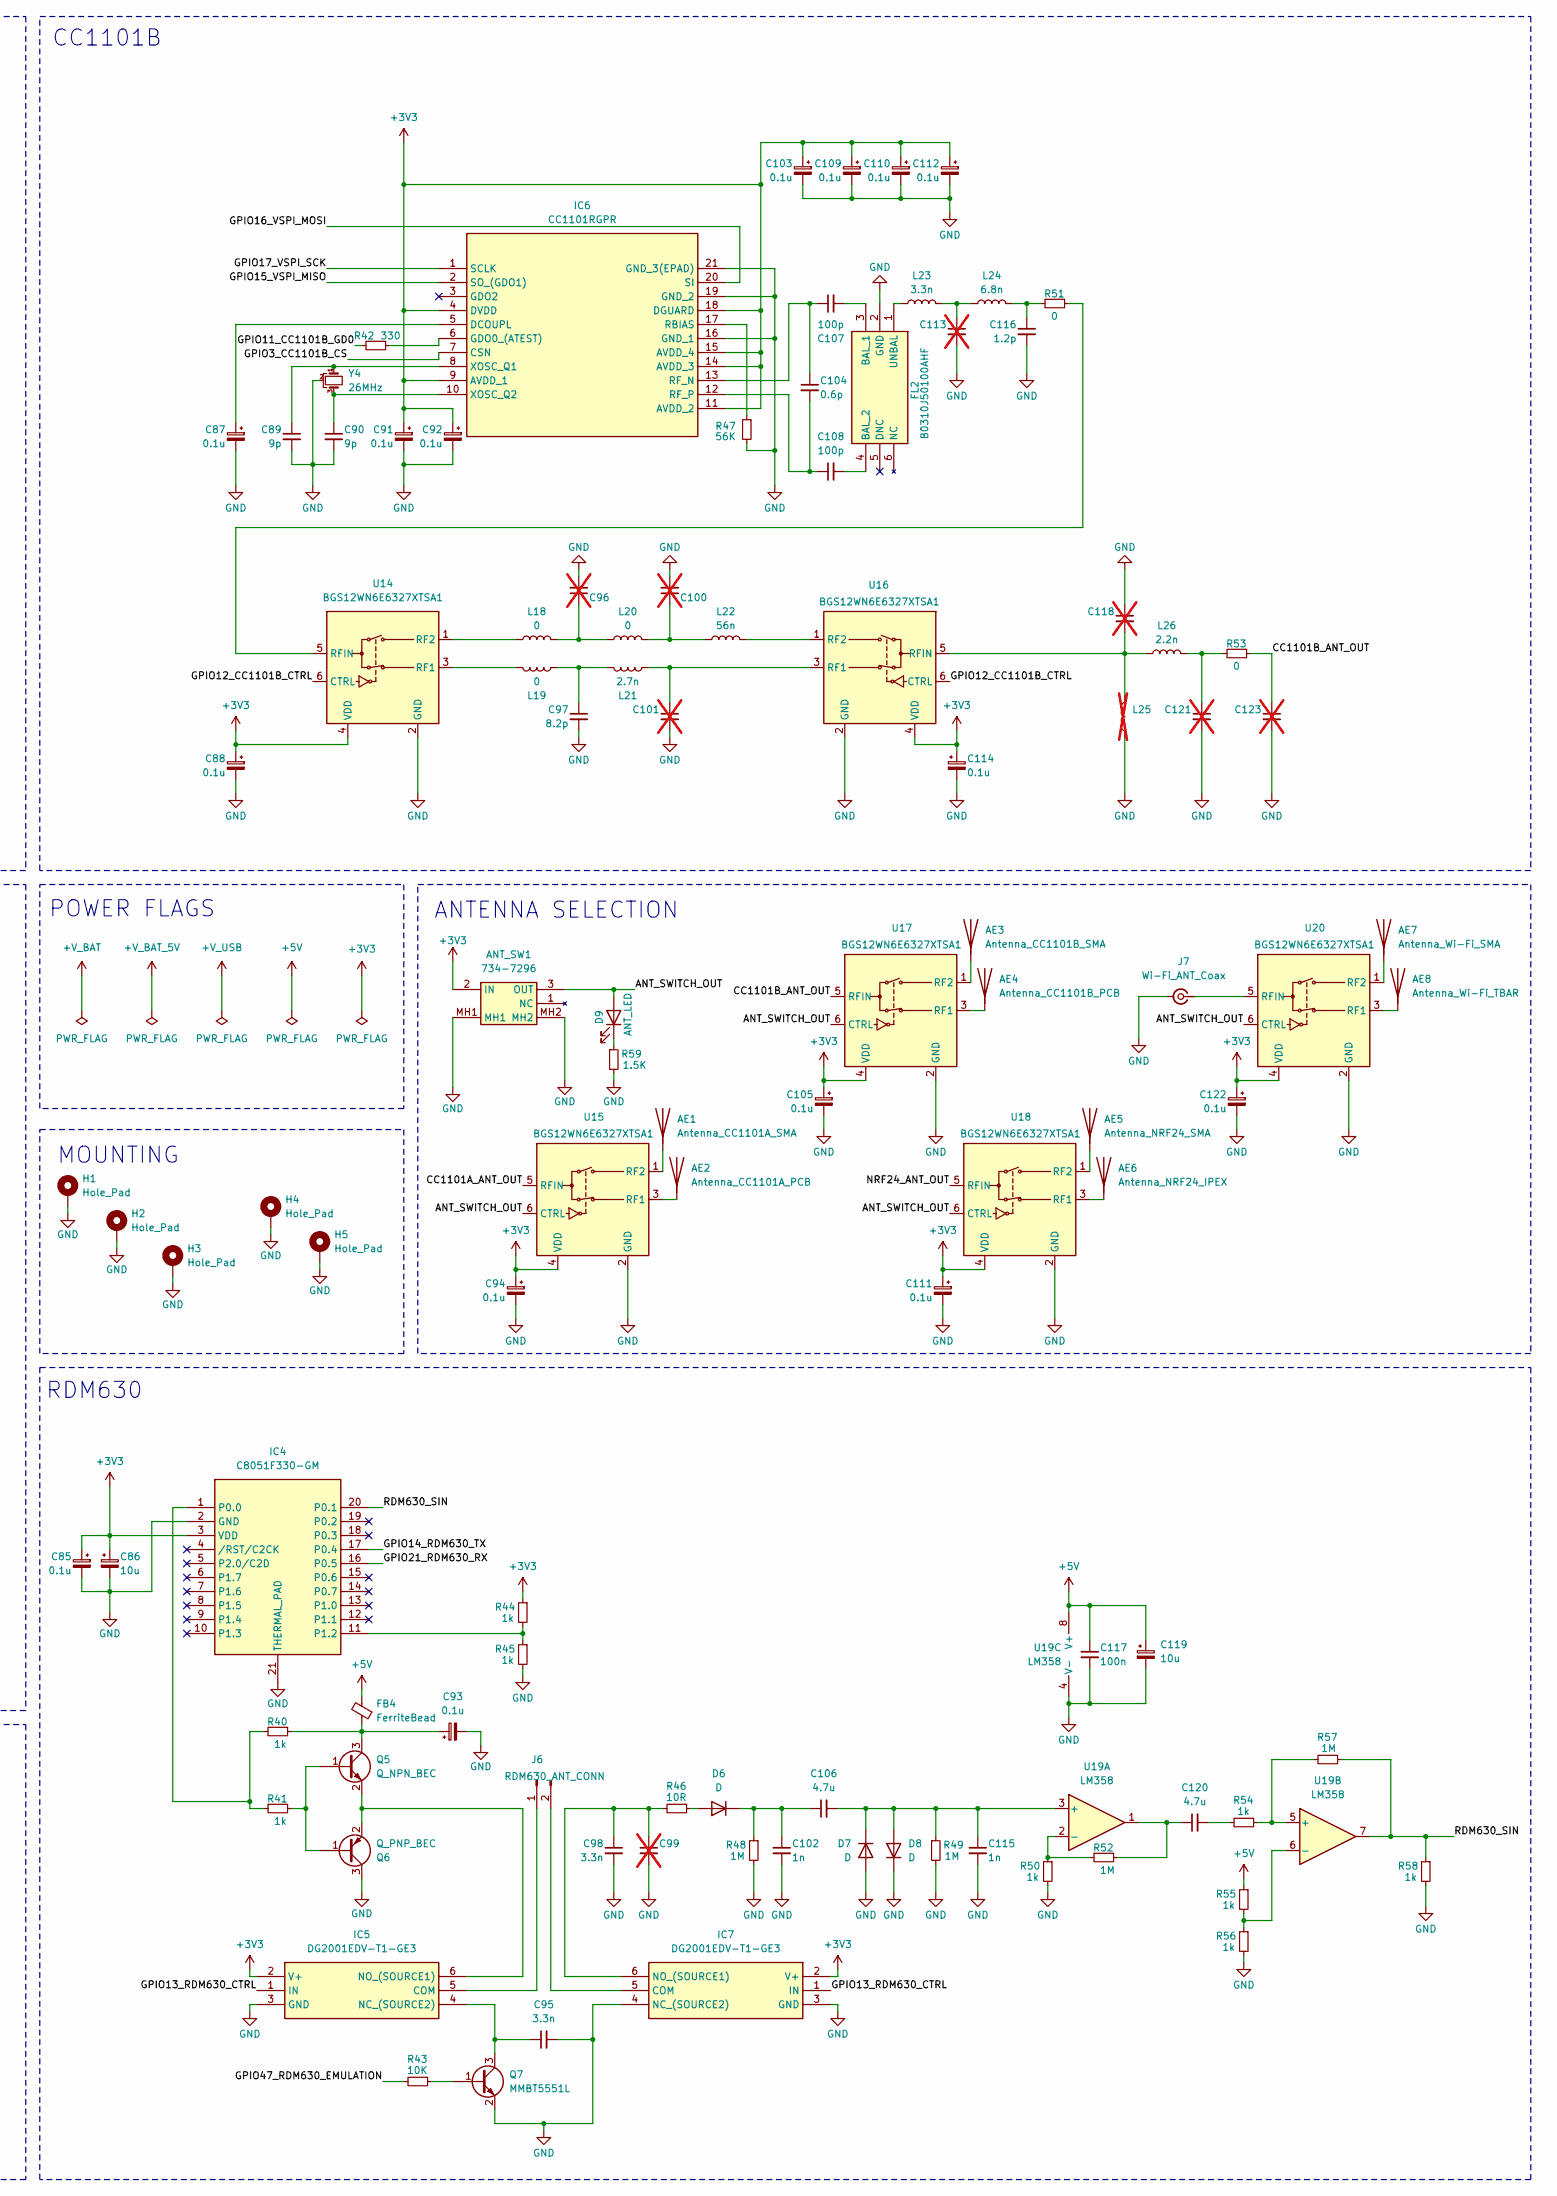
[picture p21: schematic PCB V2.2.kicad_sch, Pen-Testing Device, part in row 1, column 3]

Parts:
AE1: Antenna_CC1101A_SMA; SMA_Molex_73251-1153_EdgeMount_Horizontal
AE2: Antenna_CC1101A_PCB; XDCR_ANT-433-HESM
AE3: Antenna_CC1101B_SMA; SMA_Molex_73251-1153_EdgeMount_Horizontal
AE4: Antenna_CC1101B_PCB; XDCR_ANT-433-HESM
AE5: Antenna_NRF24_SMA; SMA_Molex_73251-1153_EdgeMount_Horizontal
AE6: Antenna_NRF24_IPEX; U.FL_Molex_MCRF_73412-0110_Vertical
AE7: Antenna_Wi-Fi_SMA; SMA_Molex_73251-1153_EdgeMount_Horizontal
AE8: Antenna_Wi-Fi_TBAR; U.FL_Molex_MCRF_73412-0110_Vertical
ANT_SW1: 734-7296; PWR-SW; Manufacturer_Part_Number 734-7296
BOOT1: 1-1825027-2; 118250272; Mouser Part Number 506-1-1825027-2
C1, C5: 1u; CP_EIA-2012-12_Kemet-R_Pad1.30x1.05mm_HandSolder
C2, C8, C13, C15, C16: 22u; CP_EIA-2012-12_Kemet-R_Pad1.30x1.05mm_HandSolder
C3, C11, C18, C22, C41, C56, C64, C86, C119: 10u; CP_EIA-2012-12_Kemet-R_Pad1.30x1.05mm_HandSolder
C4, C10, C14: 100n; CP_EIA-2012-12_Kemet-R_Pad1.30x1.05mm_HandSolder
C6, C12, C17, C19, C20, C21, C24, C25, C32, C39, C40, C52, C58, C60, C66, C67, C68, C70, C72, C85, C87, C88, C91, C92, C93, C94, C103, C105, C109, C110, C111, C112, C114, C122: 0.1u; CP_EIA-2012-12_Kemet-R_Pad1.30x1.05mm_HandSolder
C7: 4u7; CP_EIA-2012-12_Kemet-R_Pad1.30x1.05mm_HandSolder
C9: 4u7; C_0805_2012Metric_Pad1.18x1.45mm_HandSolder; not fitted
C23: 33n; C_0805_2012Metric_Pad1.18x1.45mm_HandSolder
C26, C27, C89, C90: 9p; C_0805_2012Metric_Pad1.18x1.45mm_HandSolder
C28, C29, C35, C38: NC; C_0805_2012Metric_Pad1.18x1.45mm_HandSolder
C30, C31, C62, C63, C107, C108: 100p; C_0805_2012Metric_Pad1.18x1.45mm_HandSolder
C33, C34, C42, C43: 22p; C_0805_2012Metric_Pad1.18x1.45mm_HandSolder
C36, C37: 220p; C_0805_2012Metric_Pad1.18x1.45mm_HandSolder
C44, C55, C59, C65, C83: 0.1u; C_0805_2012Metric_Pad1.18x1.45mm_HandSolder
C45, C53, C54, C71, C80, C82, C84, C96, C99, C100, C101, C113, C118, C121, C123: C_0805_2012Metric_Pad1.18x1.45mm_HandSolder; not fitted
C46, C97: 8.2p; C_0805_2012Metric_Pad1.18x1.45mm_HandSolder
C47: 2.2n; C_0805_2012Metric_Pad1.18x1.45mm_HandSolder
C48: 4.7p; C_0805_2012Metric_Pad1.18x1.45mm_HandSolder
C49, C74, C78, C79, C81: 1.5p; C_0805_2012Metric_Pad1.18x1.45mm_HandSolder
C50, C75: 10u; C_0805_2012Metric_Pad1.18x1.45mm_HandSolder
C51: 1p; C_0805_2012Metric_Pad1.18x1.45mm_HandSolder
C57: 1000p; C_0805_2012Metric_Pad1.18x1.45mm_HandSolder
C61, C104: 0.6p; C_0805_2012Metric_Pad1.18x1.45mm_HandSolder
C69: 0.3p; C_0805_2012Metric_Pad1.18x1.45mm_HandSolder
C73, C76: 33p; C_0805_2012Metric_Pad1.18x1.45mm_HandSolder
C77, C116: 1.2p; C_0805_2012Metric_Pad1.18x1.45mm_HandSolder
C95, C98: 3.3n; C_1206_3216Metric_Pad1.33x1.80mm_HandSolder
C102, C115: 1n; C_0805_2012Metric_Pad1.18x1.45mm_HandSolder
C106, C120: 4.7u; C_0805_2012Metric_Pad1.18x1.45mm_HandSolder
C117: 100n; C_0805_2012Metric_Pad1.18x1.45mm_HandSolder
CR1: MBR120; SDO_SOD-123FL498_OSI
D1: 1N4148WT; D_SOD-523
D2: Charging_LED; LED_0805_2012Metric_Pad1.15x1.40mm_HandSolder
D3: Power_LED; LED_0805_2012Metric_Pad1.15x1.40mm_HandSolder
D4: IR204A; LED_D3.0mm_IRBlack
D5: SD_ACT_LED; LED_0805_2012Metric_Pad1.15x1.40mm_HandSolder
D6, D7, D8: D; D_0805_2012Metric_Pad1.15x1.40mm_HandSolder
D9: ANT_LED; LED_0805_2012Metric_Pad1.15x1.40mm_HandSolder
F1: Polyfuse 1A; Fuse_1206_3216Metric_Pad1.42x1.75mm_HandSolder
FB1: BLM21PG221; L_0603_1608Metric_Pad1.05x0.95mm_HandSolder
FB2, FB4: FerriteBead; BEADC2012X145N
FB3: FerriteBead_Small; BEADC2012X145N
FL1, FL2: B0310J50100AHF; Mouser Part Number 620-B0310J50100AHF
H1, H2, H3, H4, H5: Hole_Pad; MountingHole_2.2mm_M2_Pad_Via
IC1: TPS61023DRLT; SOTFL50P160X60-6N; Mouser Part Number 595-TPS61023DRLT
IC2, IC6: CC1101RGPR; QFN50P400X400X100-21N-D; Mouser Part Number 595-CC1101RGPR
IC3: PN5321A3HN_C106,55; HVQFN-40-1EP_6x6mm_P0.5mm_EP4.1x4.1mm_ThermalVias; Mouser Part Number 771-PN5321A3HNC10
IC4: C8051F330-GM; QFN50P400X400X100-21N-D; Mouser Part Number 634-C8051F330-GM
IC5, IC7: DG2001EDV-T1-GE3; SOT95P284X110-6N; Mouser Part Number 78-DG2001EDV-T1-GE3
J1: Conn_01x02; PinSocket_1x02_P2.54mm_Vertical
J3: MEM2061-01-188-00-A_REVA; GCT_MEM2061-01-188-00-A_REVA
J5: PN532_Antenna_Coax; U.FL_Molex_MCRF_73412-0110_Vertical
J6: RDM630_ANT_CONN; PinHeader_1x02_P2.54mm_Vertical
J7: Wi-Fi_ANT_Coax; U.FL_Molex_MCRF_73412-0110_Vertical
J8, J10: Conn_01x14; PinSocket_1x14_P1.27mm_Vertical
J9: Conn_01x12; PinSocket_1x12_P1.27mm_Vertical
JSTPH1: Battery Plug; JST_PH_S2B-PH-K_1x02_P2.00mm_Horizontal
L1: 1u; L_Changjiang_FNR5045S
L2: 8.2n; L_0805_2012Metric_Pad1.15x1.40mm_HandSolder
L3, L8, L21: 2.7n; L_0805_2012Metric_Pad1.15x1.40mm_HandSolder
L4, L5, L7, L18, L19, L20: 0; L_0805_2012Metric_Pad1.15x1.40mm_HandSolder
L6: 3.9n; L_0805_2012Metric_Pad1.15x1.40mm_HandSolder
L9, L10: 560n; L_0805_2012Metric_Pad1.15x1.40mm_HandSolder
L11, L22: 56n; L_0805_2012Metric_Pad1.15x1.40mm_HandSolder
L12, L23: 3.3n; L_0805_2012Metric_Pad1.15x1.40mm_HandSolder
L13, L24: 6.8n; L_0805_2012Metric_Pad1.15x1.40mm_HandSolder
L14, L15: 2.4n; L_0805_2012Metric_Pad1.15x1.40mm_HandSolder
L16, L25: L_0805_2012Metric_Pad1.15x1.40mm_HandSolder; not fitted
L17, L26: 2.2n; L_0805_2012Metric_Pad1.15x1.40mm_HandSolder
PWR_SW1: 734-7296; PWR-SW; Manufacturer_Part_Number 734-7296
Q1: DMG3415U; SOT95P240X105-3N
Q2: DMN2058U; SOT-23
Q3: UMH3N; SOT-363_SC-70-6
Q4: PZT3904; SOT-223-3_TabPin2
Q5: Q_NPN_BEC; TSOT-23_HandSoldering
Q6: Q_PNP_BEC; TSOT-23_HandSoldering
Q7: MMBT5551L; SOT-23
R1: 4.7K; R_0805_2012Metric_Pad1.20x1.40mm_HandSolder
R2, R4, R15, R16, R23, R43: 10K; R_0805_2012Metric_Pad1.20x1.40mm_HandSolder
R3: 150; R_0805_2012Metric_Pad1.20x1.40mm_HandSolder
R5, R8, R9, R11: 5k1; R_0805_2012Metric_Pad1.20x1.40mm_HandSolder
R6: 22; R_0805_2012Metric_Pad1.20x1.40mm_HandSolder
R7, R12, R20: 100k; R_0805_2012Metric_Pad1.20x1.40mm_HandSolder
R10, R14, R24, R59: 1.5K; R_0805_2012Metric_Pad1.20x1.40mm_HandSolder
R13: 10k; R_0805_2012Metric_Pad1.20x1.40mm_HandSolder
R17, R18: 22R; R_0805_2012Metric_Pad1.20x1.40mm_HandSolder
R19: 732k; R_0805_2012Metric_Pad1.20x1.40mm_HandSolder
R21, R30, R42: 330; R_0805_2012Metric_Pad1.20x1.40mm_HandSolder
R22: 50; R_0805_2012Metric_Pad1.20x1.40mm_HandSolder
R25: 22k; R_0805_2012Metric_Pad1.20x1.40mm_HandSolder
R26, R27: NC; R_0805_2012Metric_Pad1.20x1.40mm_HandSolder
R28, R29: 1.5; R_0805_2012Metric_Pad1.20x1.40mm_HandSolder
R31, R48, R49, R52, R57: 1M; R_0805_2012Metric_Pad1.20x1.40mm_HandSolder
R32: 1.69K; R_0805_2012Metric_Pad1.20x1.40mm_HandSolder
R33, R47: 56K; R_0805_2012Metric_Pad1.20x1.40mm_HandSolder
R34, R35, R36: 1K; R_0805_2012Metric_Pad1.20x1.40mm_HandSolder
R37: 20K; R_0805_2012Metric_Pad1.20x1.40mm_HandSolder
R38, R39, R51, R53: 0; R_0805_2012Metric_Pad1.20x1.40mm_HandSolder
R40, R41, R44, R45, R50, R54, R55, R56, R58: 1k; R_0805_2012Metric_Pad1.20x1.40mm_HandSolder
R46: 10R; R_0805_2012Metric_Pad1.20x1.40mm_HandSolder
RESET1: 1-1825027-2; 118250272; Mouser Part Number 506-1-1825027-2
SCREEN1: 4.0_TFT_Display
TP1: TX1_PRE; TestPoint_Pad_D1.0mm
TP2, TP5: TGND; TestPoint_Pad_D1.0mm
TP3: TX2_PRE; TestPoint_Pad_D1.0mm
TP4: TX1_POST; TestPoint_Pad_D1.0mm
TP6: TX2_POST; TestPoint_Pad_D1.0mm
TP7: RX; TestPoint_Pad_D1.0mm
U1: MCP73831-2-OT; SOT-23-5
U2: USBLC6-2P6; SOT-666
U3: TLV70036_SOT23-5; SOT-23-5
U4: AMS1117-3.3; SOT-223-3_TabPin2
U5: TSOP382xx; Vishay_MINICAST-3Pin
U6: CP2104; QFN-24-1EP_4x4mm_P0.5mm_EP2.6x2.6mm
U7: ESD7104MUTAG; Diodes_UDFN-10_1.0x2.5mm_P0.5mm
U8: 4050; SOIC-16_3.9x9.9mm_P1.27mm
U9: ESP32-S3-WROOM-1U-N16R2; ESP32-S3-WROOM-1U_EXP
U10: nRF24L01P; QFN-20-1EP_4x4mm_P0.5mm_EP2.5x2.5mm
U11, U13, U14, U15, U16, U17, U18, U20: BGS12WN6E6327XTSA1; Infineon_PG-TSNP-6-10_0.7x1.1mm_0.7x1.1mm_P0.4mm
U12: RFX2401C; RFX2401C_SKY
U19: LM358; SOIC127P600X175-8N
USB_OTG1: USB_C_Receptacle_USB2.0_16P; USB_C_Receptacle_HRO_TYPE-C-31-M-12
USB_UART1: USB_C_Receptacle_USB2.0_16P; USB_C_Receptacle_HRO_TYPE-C-31-M-12
Y1, Y4: 26MHz; Crystal_SMD_3225-4Pin_3.2x2.5mm_HandSoldering
Y2: 16M; XTAL_7M-27.120MAAJ-T
Y3: 27.12M; XTAL_7M-27.120MAAJ-T

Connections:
+3.3VA: C13.1, C14.1, R13.1, U6.5 (VIO), U6.6 (VDD)
+3V3: ANT_SW1.2 (IN), C11.1, C12.1, C17.1, C18.1, C21.1, C22.1, C25.1, C32.1, C39.1, C40.1, C41.1, C44.1, C59.1, C60.1, C64.1, C65.1, C66.1, C67.1, C68.1, C70.1, C72.1, C83.1, C85.1, C86.1, C88.1, C91.1, C92.1, C94.1, C103.1, C105.1, C109.1, C110.1, C111.1, C112.1, C114.1, C122.1, D3.2 (A), D4.2 (A), FB2.1, FB3.1, IC2.4 (DVDD), IC2.9 (AVDD_1), IC2.11 (AVDD_2), IC2.14 (AVDD_3), IC2.15 (AVDD_4), IC2.18 (DGUARD), IC3.17 (I1), IC3.23 (PVDD), IC3.39 (DVDD), IC3.40 (VBAT), IC4.3 (VDD), IC5.2 (V+), IC6.4 (DVDD), IC6.9 (AVDD_1), IC6.11 (AVDD_2), IC6.14 (AVDD_3), IC6.15 (AVDD_4), IC6.18 (DGUARD), IC7.2 (V+), J3.4 (VDD), J8.2, R6.1, R23.1, R44.1, SCREEN1.1 (VCC), SCREEN1.8 (LED), U4.2 (VO), U5.3 (Vs), U8.1 (VCC), U9.2 (3V3), U10.7 (VDD), U10.15 (VDD), U10.18 (VDD), U11.4 (VDD), U12.14 (VDD), U12.16 (VDD), U13.4 (VDD), U14.4 (VDD), U15.4 (VDD), U16.4 (VDD), U17.4 (VDD), U18.4 (VDD), U20.4 (VDD)
+5V: C3.1, C6.1, C117.1, C119.1, CR1.1, FB4.2, Q1.2 (S), R55.1, U2.5 (VBUS), U4.3 (VI), U19.8 (V+)
+V_BAT: C10.1, JSTPH1.2, PWR_SW1.2 (IN), R15.1, U1.3 (V_{BAT})
+V_BAT_5V: C15.1, C16.1, IC1.6 (VOUT), Q1.3 (D), R19.1
+V_USB: CR1.2, D2.2 (A), FB1.1, Q1.1 (G), R2.1, U1.4 (V_{DD}), U7.4, U7.7 (NC), USB_OTG1.A4 (VBUS), USB_OTG1.A9 (VBUS), USB_OTG1.B4 (VBUS), USB_OTG1.B9 (VBUS), USB_UART1.A4 (VBUS), USB_UART1.A9 (VBUS), USB_UART1.B4 (VBUS), USB_UART1.B9 (VBUS)
/ANT_SWITCH_OUT: ANT_SW1.3 (OUT), D9.2 (A), U15.6 (CTRL), U17.6 (CTRL), U18.6 (CTRL), U20.6 (CTRL)
/CC1101A_ANT_OUT: C84.1, R39.1, U15.5 (RFIN)
/CC1101B_ANT_OUT: C123.1, R53.1, U17.5 (RFIN)
/D+: J8.14, U7.1, U7.10 (NC), U9.14 (IO20), USB_OTG1.A6 (D+), USB_OTG1.B6 (D+)
/D-: J8.13, U7.2, U7.9 (NC), U9.13 (IO19), USB_OTG1.A7 (D-), USB_OTG1.B7 (D-)
/DTR: Q3.1 (E1), Q3.5 (B2), U6.23 (~DTR)
/EN/RESET: C19.1, J8.3, Q3.4 (E2), R23.2, RESET1.1 (COM), SCREEN1.4 (RESET), U9.3 (EN)
/ESP32_PIN16_DNC: J9.2, U9.16 (IO46)
/ESP32_PIN26_DNC: J9.12, U9.26 (IO45)
/GPIO1_SCREEN_CS: J10.13, SCREEN1.3 (CS), U9.39 (IO1)
/GPIO2_SCREEN_D/C: J10.12, SCREEN1.5 (DC/RS), U9.38 (IO2)
/GPIO3_CC1101B_CS: IC6.7 (CSN), J9.1, U9.15 (IO3)
/GPIO4_ADC1_3_BAT%: J8.4, R15.2, R16.1, U9.4 (IO4)
/GPIO5_NRF24_CE: J8.5, R35.2, U9.5 (IO5), U10.1 (CE)
/GPIO6_NRF24_CSN: J8.6, U9.6 (IO6), U10.2 (CSN)
/GPIO7_NRF24_IRQ: J8.7, U9.7 (IO7), U10.6 (IRQ)
/GPIO8_CC1101A_CS: IC2.7 (CSN), J8.12, U9.12 (IO8)
/GPIO9_CC1101A_GD0: J9.3, R30.2, U9.17 (IO9)
/GPIO10_CC1101A_CTRL: J9.4, U9.18 (IO10), U11.6 (CTRL), U13.6 (CTRL)
/GPIO11_CC1101B_GD0: J9.5, R42.2, U9.19 (IO11)
/GPIO12_CC1101B_CTRL: J9.6, U9.20 (IO12), U14.6 (CTRL), U16.6 (CTRL)
/GPIO13_RDM630_CTRL: IC5.1 (IN), IC7.1 (IN), J9.7, U9.21 (IO13)
/GPIO14_RDM630_TX: IC4.17 (P0.4), J9.8, U9.22 (IO14)
/GPIO15_VSPI_MISO: IC6.2 (SO_(GDO1)), J8.8, U9.8 (IO15)
/GPIO16_VSPI_MOSI: IC6.20 (SI), J8.9, U9.9 (IO16)
/GPIO17_VSPI_SCK: IC6.1 (SCLK), J8.10, U9.10 (IO17)
/GPIO18_VIBRO: J8.11, R3.2, U9.11 (IO18)
/GPIO21_RDM630_RX: IC4.16 (P0.5), J9.9, U9.23 (IO21)
/GPIO35_SCREEN_T_IRQ: J10.2, SCREEN1.14 (T_IRQ), U9.28 (IO35)
/GPIO36_SCREEN_T_CS: J10.3, SCREEN1.11 (T_CS), U9.29 (IO36)
/GPIO37_IR_RECEIVER: J10.4, U5.1 (OUT), U9.30 (IO37)
/GPIO38_IR_LED: J10.5, R21.2, U9.31 (IO38)
/GPIO39_HSPI_SCK: IC2.1 (SCLK), IC3.30 (SCK_/_P72), J10.6, SCREEN1.7 (SCK), SCREEN1.10 (T_CLK), U8.3, U8.9, U9.32 (IO39), U10.3 (SCK)
/GPIO40_HSPI_MOSI: IC2.20 (SI), IC3.28 (MOSI_/_SDA_/_HSU_TX), J10.7, SCREEN1.6 (SDI(MOSI)), SCREEN1.12 (T_DIN), U8.5, U9.33 (IO40), U10.4 (MOSI)
/GPIO41_HSPI_MISO: IC2.2 (SO_(GDO1)), IC3.29 (MISO_/_P71), J3.7 (DAT0), J10.8, SCREEN1.13 (T_DO), U9.34 (IO41), U10.5 (MISO)
/GPIO42_SD_CARD_CS: J10.9, U8.7, U9.35 (IO42)
/GPIO47_RDM630_EMULATION: J9.10, R43.2, U9.24 (IO47)
/GPIO48_PN532_CS: IC3.27 (NSS_/_P50_SCL_/_HSU_RX), J9.11, U9.25 (IO48)
/IO0: BOOT1.1 (COM), C20.1, J10.1, Q3.6 (C1), U9.27 (IO0)
/NRF24_ANT_OUT: C81.1, L15.2, U18.5 (RFIN)
/NRF24_VDD_PA: C47.2, C48.2, L3.2, R34.2, U10.11 (VDD_PA)
/PN532_AUX1: IC3.12 (AUX1)
/PN532_AUX2: IC3.13 (AUX2)
/PN532_IRQ: IC3.25 (P70_IRQ)
/PN532_P30_UART_RX: IC3.24 (P30_/UART_RX)
/PN532_P31_UART_TX: IC3.31 (P31_/_UART_TX)
/PN532_P32: IC3.32 (P32_INT0)
/PN532_P33: IC3.33 (P33_INT1)
/PN532_P34_SIC_CLK: IC3.34 (P34_/_SIC_CLK)
/PN532_P35: IC3.19 (P35)
/PN532_RSTOUT_N: IC3.26 (RSTOUT_N)
/PN532_RSTPD_N: IC3.38 (RSTPD_N)
/PN532_SIGIN: IC3.36 (SIGIN)
/PN532_SIGOUT: IC3.35 (SIGOUT)
/RDM630_SIN: IC4.20 (P0.1), R57.1, R58.1, U19.7
/RTS: Q3.2 (B1), Q3.3 (C2), U6.19 (~RTS)
/RX: J10.10, R17.2, U9.36 (RXD0)
/TX: J10.11, R18.2, U9.37 (TXD0)
GND: ANT_SW1.MH1, ANT_SW1.MH2, BOOT1.2 (NO), BOOT1.MH1, BOOT1.MH2, C1.2, C2.2, C3.2, C4.2, C5.2, C6.2, C7.2, C8.2, C9.2, C10.2, C11.2, C12.2, C13.2, C14.2, C15.2, C16.2, C17.2, C18.2, C19.2, C20.2, C21.2, C22.2, C23.1, C24.2, C25.2, C26.2, C27.2, C28.2, C29.1, C30.2, C31.1, C32.2, C36.2, C37.1, C39.2, C40.2, C41.2, C42.2, C43.2, C44.2, C45.2, C46.2, C47.1, C48.1, C50.2, C51.2, C52.2, C53.2, C54.2, C55.2, C56.2, C58.2, C59.2, C60.2, C64.2, C65.2, C66.2, C67.2, C68.2, C69.2, C70.2, C71.2, C72.2, C73.1, C74.2, C75.1, C76.2, C77.2, C78.2, C79.2, C80.1, C81.2, C82.2, C83.2, C84.2, C85.2, C86.2, C87.2, C88.2, C89.2, C90.2, C91.2, C92.2, C93.2, C94.2, C95.2, C96.2, C97.2, C98.2, C99.2, C100.2, C101.2, C102.2, C103.2, C105.2, C109.2, C110.2, C111.2, C112.2, C113.2, C114.2, C115.2, C116.2, C117.2, C118.1, C119.2, C121.2, C122.2, C123.2, D7.2 (A), D8.1 (K), FL1.2 (GND), FL2.2 (GND), H1.1, H2.1, H3.1, H4.1, H5.1, IC1.4 (GND), IC2.16 (GND_1), IC2.19 (GND_2), IC2.21 (GND_3(EPAD)), IC3.1 (DVSS), IC3.3 (TVSS1), IC3.7 (TVSS2), IC3.11 (AVSS), IC3.16 (I0), IC3.18 (TESTEN), IC3.41 (EPAD), IC4.2 (GND), IC4.21 (THERMAL_PAD), IC5.3 (GND), IC6.16 (GND_1), IC6.19 (GND_2), IC6.21 (GND_3(EPAD)), IC7.3 (GND), IC7.4 (NC_(SOURCE2)), J3.6 (VSS), J3.11 (GND), J3.12 (GND), J7.2 (Ext), J8.1, J10.14, JSTPH1.1, L16.1, L25.1, PWR_SW1.MH1, PWR_SW1.MH2, Q2.2 (S), Q4.3 (E), Q6.3 (C), Q7.2 (E), R1.2, R2.2, R4.2, R5.2, R8.2, R9.2, R11.2, R14.2, R16.2, R20.2, R25.2, R26.2, R27.1, R33.2, R37.2, R45.2, R47.2, R48.2, R49.2, R50.2, R56.2, R58.2, R59.2, RESET1.2 (NO), RESET1.MH1, RESET1.MH2, SCREEN1.2 (GND), SCREEN1.15 (MH), TP2.1, TP5.1, U1.2 (V_{SS}), U2.2 (GND), U3.2 (GND), U4.1 (GND), U5.2 (GND), U6.2 (GND), U6.25 (GND), U7.3 (VSS), U7.8 (VSS), U8.8 (VSS), U8.11, U8.14, U9.1 (GND), U9.40 (GND), U9.41 (GND), U9.42 (GND), U9.43 (GND), U9.44 (GND), U9.45 (GND), U9.46 (GND), U9.47 (GND), U9.48 (GND), U9.49 (GND), U10.8 (VSS), U10.14 (VSS), U10.17 (VSS), U10.20 (VSS), U10.21 (GND), U11.2 (GND), U12.2 (GND), U12.3 (GND), U12.8 (GND), U12.9 (GND), U12.11 (GND), U12.17 (GND), U13.2 (GND), U14.2 (GND), U15.2 (GND), U16.2 (GND), U17.2 (GND), U18.2 (GND), U19.4 (V-), U20.2 (GND), USB_OTG1.A1 (GND), USB_OTG1.A12 (GND), USB_OTG1.B1 (GND), USB_OTG1.B12 (GND), USB_OTG1.S1 (SHIELD), USB_UART1.A1 (GND), USB_UART1.A12 (GND), USB_UART1.B1 (GND), USB_UART1.B12 (GND), USB_UART1.S1 (SHIELD), Y1.2, Y4.2
unnamed: AE1.1 (A), U15.1 (RF2)
unnamed: AE2.1 (A), U15.3 (RF1)
unnamed: AE3.1 (A), U17.1 (RF2)
unnamed: AE4.1 (A), U17.3 (RF1)
unnamed: AE5.1 (A), U18.1 (RF2)
unnamed: AE6.1 (A), U18.3 (RF1)
unnamed: AE7.1 (A), U20.1 (RF2)
unnamed: AE8.1 (A), U20.3 (RF1)
unnamed: C28.1, C30.1, C33.1, C35.1, R28.2
unnamed: C29.2, C31.2, C34.2, C38.2, R29.1
unnamed: C33.2, C35.2, C36.1, L9.1, TP4.1
unnamed: C34.1, C37.2, C38.1, L10.1, R32.1, TP6.1, TP7.1
unnamed: C45.1, L4.2, L7.1
unnamed: C46.1, L5.2, L8.1
unnamed: C49.1, L6.1
unnamed: C53.1, L7.2, L11.1
unnamed: C57.1, R32.2
unnamed: C71.1, L12.2, L13.1
unnamed: C77.1, L13.2, R38.2
unnamed: C78.1, C79.1, L14.2, L15.1
unnamed: C82.1, L17.2, R39.2
unnamed: C96.1, L18.2, L20.1
unnamed: C97.1, L19.2, L21.1
unnamed: C100.1, L20.2, L22.1
unnamed: C113.1, L23.2, L24.1
unnamed: C116.1, L24.2, R51.2
unnamed: C120.1, R52.1, U19.1
unnamed: C120.2, R54.2
unnamed: C121.1, L26.2, R53.2
unnamed: D1.2 (A), J1.2, Q2.3 (D)
unnamed: D1.1 (K), J1.1, R6.2
unnamed: D2.1 (K), R10.2
unnamed: D3.1 (K), R14.1
unnamed: D4.1 (K), R22.1
unnamed: D5.2 (A), U8.10
unnamed: D5.1 (K), R24.2
unnamed: D6.2 (A), R46.1
unnamed: C102.1, C106.1, D6.1 (K), R48.1
unnamed: C106.2, C115.1, D7.1 (K), D8.2 (A), R49.1, U19.3 (+)
unnamed: D9.1 (K), R59.1
unnamed: F1.1, FB1.2
unnamed: C62.2, FL1.3 (BAL_1)
unnamed: C63.2, FL1.4 (BAL_2)
unnamed: FL1.1 (UNBAL), L12.1
unnamed: C107.2, FL2.3 (BAL_1)
unnamed: C108.2, FL2.4 (BAL_2)
unnamed: FL2.1 (UNBAL), L23.1
unnamed: IC1.2 (EN), R12.1
unnamed: IC1.1 (FB), R19.2, R20.1
unnamed: IC1.5 (SW), L1.2
unnamed: C5.1, C8.1, IC1.3 (VIN), L1.1, R12.2, U3.5 (OUT)
unnamed: C24.1, IC2.5 (DCOUPL)
unnamed: IC2.6 (GDO0_(ATEST)), R30.1
unnamed: IC2.17 (RBIAS), R33.1
unnamed: C61.1, C62.1, IC2.13 (RF_N)
unnamed: C61.2, C63.1, IC2.12 (RF_P)
unnamed: C26.1, IC2.8 (XOSC_Q1), Y1.1
unnamed: C27.1, IC2.10 (XOSC_Q2), Y1.3
unnamed: C52.1, C56.1, FB3.2, IC3.8 (AVDD)
unnamed: C73.2, IC3.14 (OSCIN), Y3.1
unnamed: C76.1, IC3.15 (OSCOUT), Y3.2
unnamed: C57.2, IC3.10 (RX), R36.2
unnamed: C75.2, IC3.37 (SVDD)
unnamed: C50.1, C55.1, FB2.2, IC3.5 (TVDD)
unnamed: IC3.4 (TX1), L9.2
unnamed: IC3.6 (TX2), L10.2
unnamed: C58.1, IC3.9 (VMID), R36.1
unnamed: IC4.1 (P0.0), R40.2, R41.2
unnamed: IC4.11 (P1.2), R44.2, R45.1
unnamed: IC5.5 (COM), J6.1
unnamed: C95.1, IC5.4 (NC_(SOURCE2)), Q7.3 (C)
unnamed: IC5.6 (NO_(SOURCE1)), Q5.2 (E), Q6.2 (E)
unnamed: C87.1, IC6.5 (DCOUPL)
unnamed: IC6.6 (GDO0_(ATEST)), R42.1
unnamed: IC6.17 (RBIAS), R47.1
unnamed: C104.1, C107.1, IC6.13 (RF_N)
unnamed: C104.2, C108.1, IC6.12 (RF_P)
unnamed: C89.1, IC6.8 (XOSC_Q1), Y4.1
unnamed: C90.1, IC6.10 (XOSC_Q2), Y4.3
unnamed: IC7.5 (COM), J6.2
unnamed: C98.1, C99.1, IC7.6 (NO_(SOURCE1)), R46.2
unnamed: J3.2 (CD/DAT3), R24.1, U8.6
unnamed: J3.5 (CLK), U8.2
unnamed: J3.3 (CMD), U8.4
unnamed: J5.2 (Ext), R27.2, R29.2, TP3.1
unnamed: J5.1 (In), R26.1, R28.1, TP1.1
unnamed: J7.1 (In), U20.5 (RFIN)
unnamed: L2.1, L3.1
unnamed: C1.1, PWR_SW1.3 (OUT), R7.2, U3.1 (IN)
unnamed: Q2.1 (G), R3.1, R4.1
unnamed: Q4.1 (B), R21.1
unnamed: Q4.2 (C), Q4.4 (C), R22.2
unnamed: Q5.1 (B), Q6.1 (B), R41.1
unnamed: C93.1, FB4.1, Q5.3 (C), R40.1
unnamed: Q7.1 (B), R43.1
unnamed: R1.1, U1.5 (PROG)
unnamed: R10.1, U1.1 (STAT)
unnamed: U2.1 (I/O1), USB_UART1.A7 (D-), USB_UART1.B7 (D-)
unnamed: U2.3 (I/O2), USB_UART1.A6 (D+), USB_UART1.B6 (D+)
unnamed: R7.1, U3.3 (EN)
unnamed: U2.4 (I/O2), U6.3 (D+)
unnamed: U2.6 (I/O1), U6.4 (D-)
unnamed: C2.1, C4.1, C7.1, F1.2, U6.7 (REGIN), U6.8 (VBUS)
unnamed: R18.1, U6.20 (RXD)
unnamed: R17.1, U6.21 (TXD)
unnamed: C9.1, U6.16 (VPP)
unnamed: R13.2, U6.9 (~RST)
unnamed: L2.2, L6.2, U10.12 (ANT1), U10.13 (ANT2)
unnamed: C23.2, U10.19 (DVDD)
unnamed: R25.1, U10.16 (IREF)
unnamed: C42.1, R31.1, U10.10 (XC1), Y2.2
unnamed: C43.1, R31.2, U10.9 (XC2), Y2.1
unnamed: L5.1, U11.3 (RF1)
unnamed: L4.1, U11.1 (RF2)
unnamed: R38.1, U11.5 (RFIN)
unnamed: C69.1, C74.1, L14.1, U12.10 (ANT)
unnamed: R35.1, R37.1, U12.6 (RXEN)
unnamed: R34.1, U12.5 (TXEN)
unnamed: C49.2, C51.1, U12.4 (TXRX)
unnamed: C54.1, L8.2, U13.3 (RF1)
unnamed: L11.2, U13.1 (RF2)
unnamed: C80.2, L16.2, L17.1, U13.5 (RFIN)
unnamed: L19.1, U14.3 (RF1)
unnamed: L18.1, U14.1 (RF2)
unnamed: R51.1, U14.5 (RFIN)
unnamed: C101.1, L21.2, U16.3 (RF1)
unnamed: L22.2, U16.1 (RF2)
unnamed: C118.2, L25.2, L26.1, U16.5 (RFIN)
unnamed: R50.1, R52.2, U19.2 (-)
unnamed: R54.1, R57.2, U19.5 (+)
unnamed: R55.2, R56.1, U19.6 (-)
unnamed: R11.1, USB_OTG1.A5 (CC1)
unnamed: R9.1, USB_OTG1.B5 (CC2)
unnamed: R8.1, USB_UART1.A5 (CC1)
unnamed: R5.1, USB_UART1.B5 (CC2)

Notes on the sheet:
ESP32-S3-N16-R2 & HEADERS
PN532 AND ANTENNA
VIBRATION MOTOR
MOUNTING
NRF24
MICRO-SD CARD
ANTENNA SELECTION
RDM630
POWER FLAGS
TFT TOUCHSCREEN
USB TYPE-C TO UART
IR LED & RECEIVER
CC1101A
POWER
CC1101B
CHARGING & POWER LEDs
USB OTG

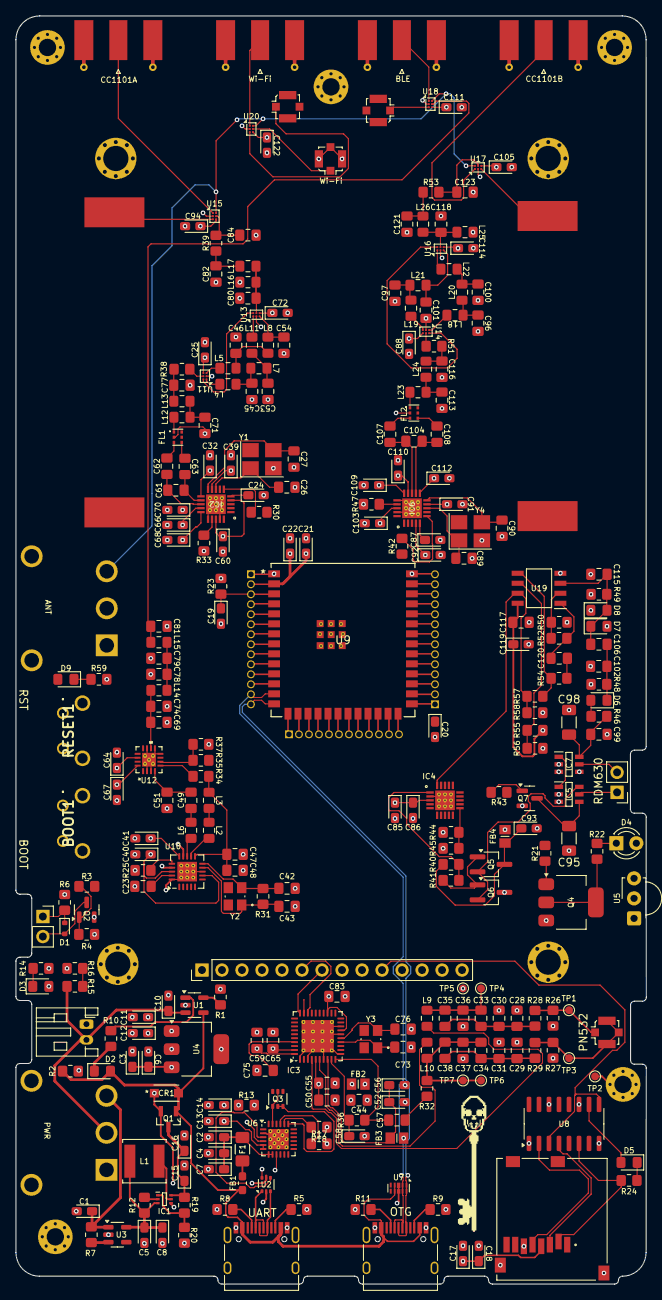
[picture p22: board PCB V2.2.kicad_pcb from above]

Board: 4 copper layers, 80.0 x 161.0 mm, 298 parts (0 on the bottom side), 186 nets.

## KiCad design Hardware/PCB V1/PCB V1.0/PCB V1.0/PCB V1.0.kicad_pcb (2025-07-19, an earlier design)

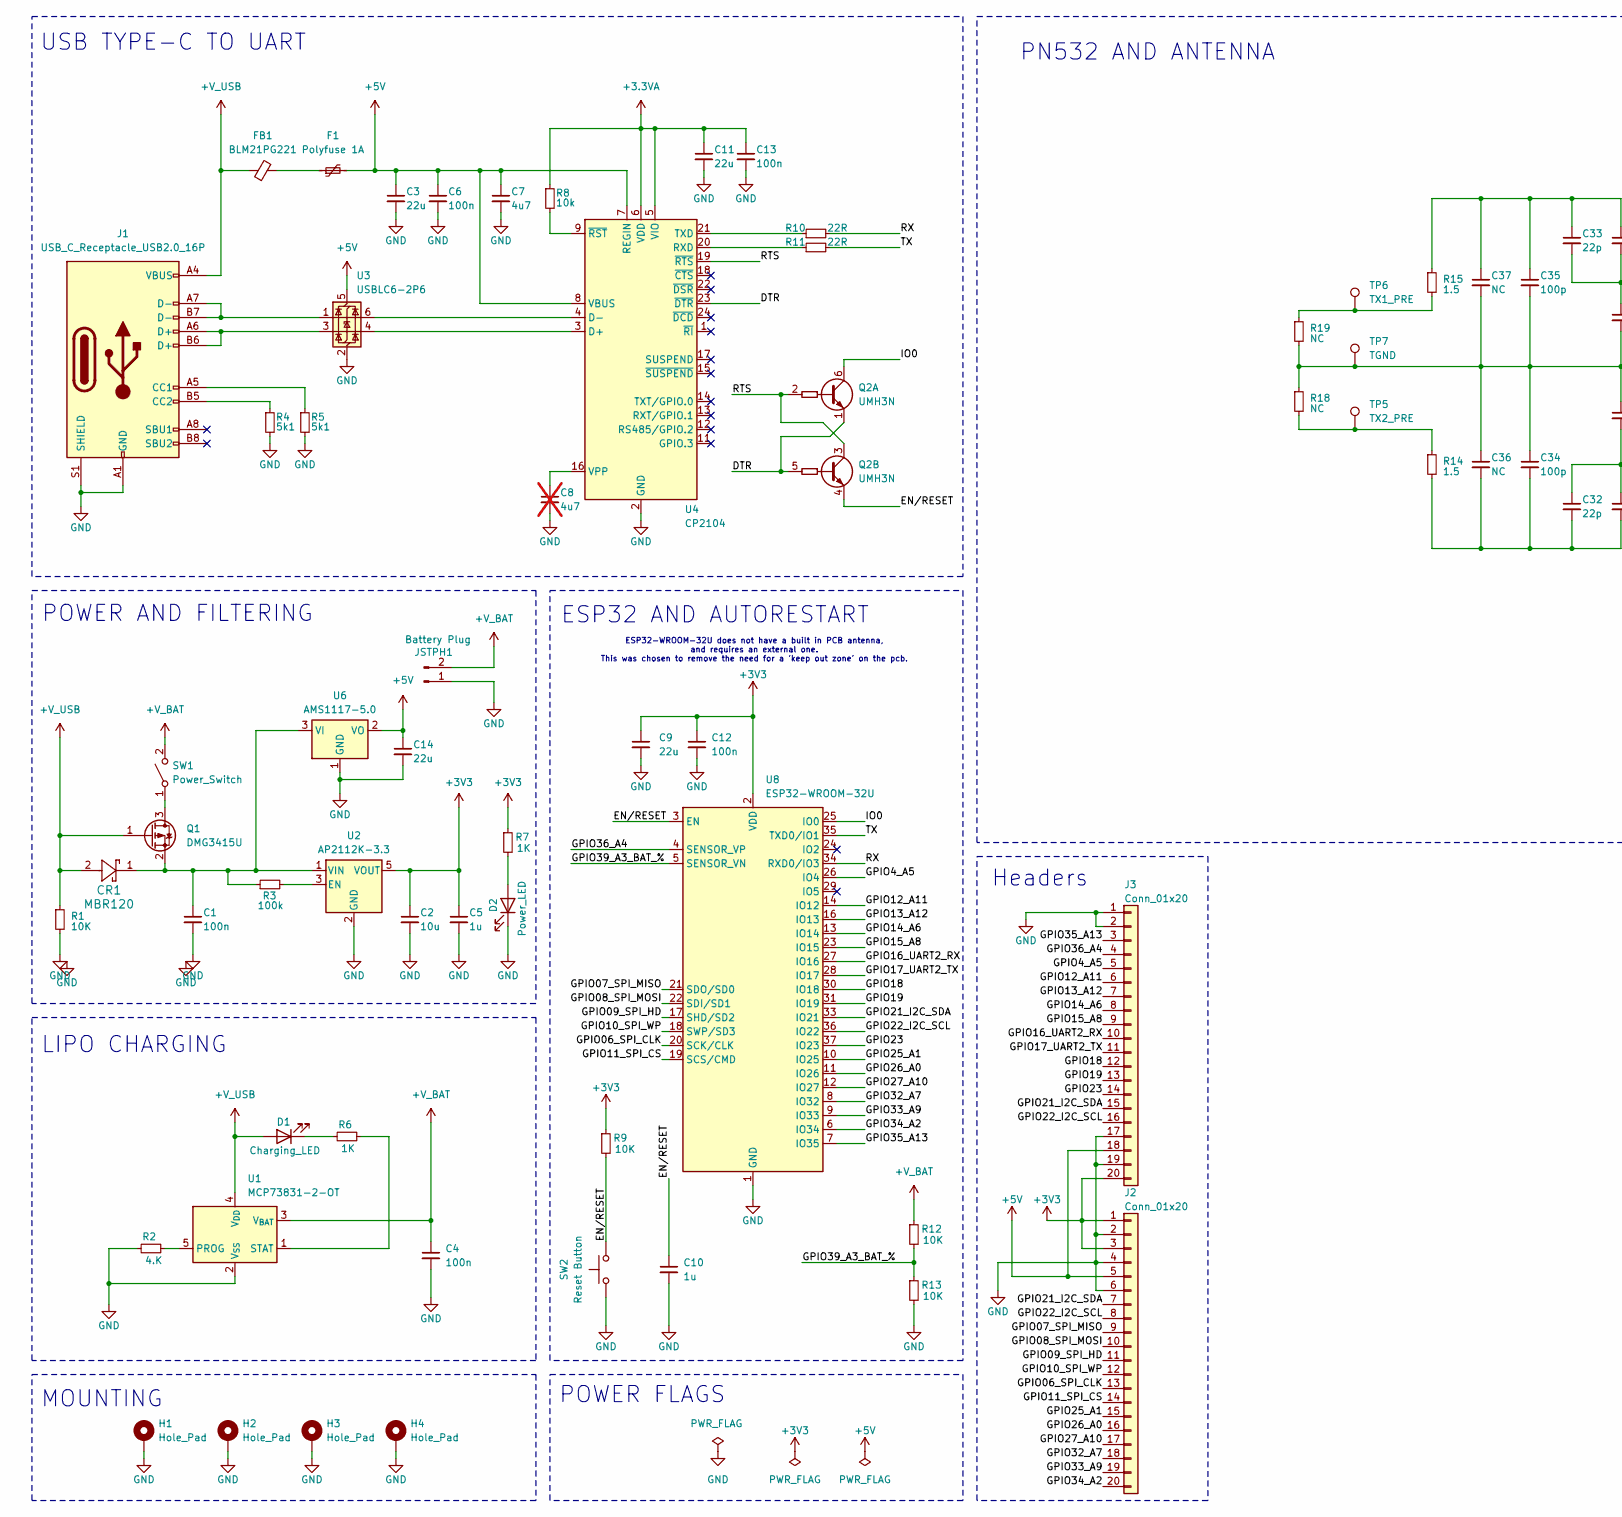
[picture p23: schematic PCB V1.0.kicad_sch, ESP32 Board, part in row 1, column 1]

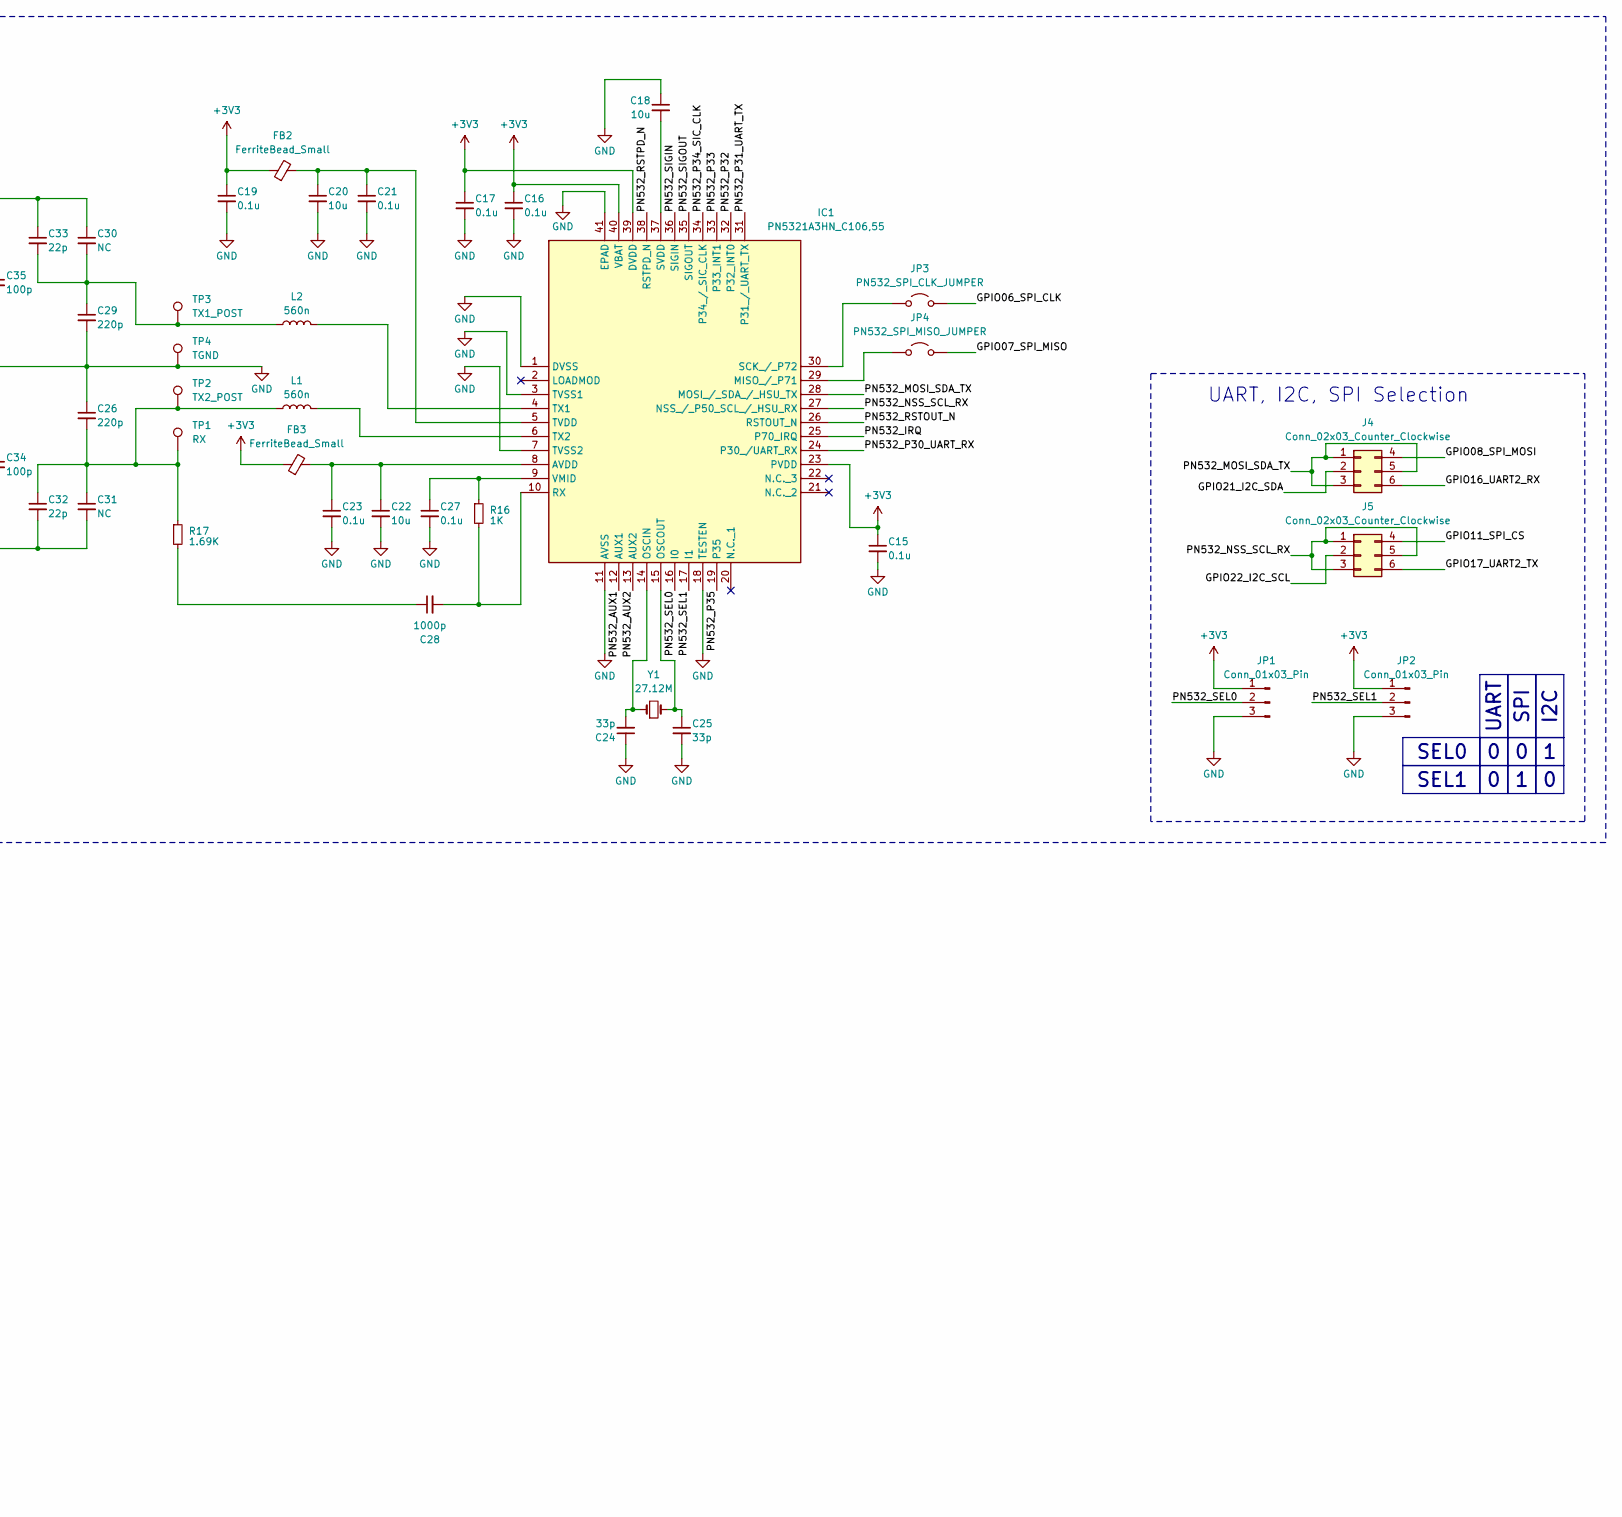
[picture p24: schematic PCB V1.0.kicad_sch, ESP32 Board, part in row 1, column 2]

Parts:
C1, C6, C13: 100n; C_0805_2012Metric_Pad1.18x1.45mm_HandSolder
C2: 10u; C_0805_2012Metric_Pad1.18x1.45mm_HandSolder
C3, C9, C11: 22u; C_0805_2012Metric_Pad1.18x1.45mm_HandSolder
C4, C12: 100n; C_0402_1005Metric_Pad0.74x0.62mm_HandSolder
C5: 1u; C_0805_2012Metric_Pad1.18x1.45mm_HandSolder
C7: 4u7; C_0805_2012Metric_Pad1.18x1.45mm_HandSolder
C8: 4u7; C_0805_2012Metric_Pad1.18x1.45mm_HandSolder; not fitted
C10: 1u; C_0402_1005Metric_Pad0.74x0.62mm_HandSolder
C14: 22u; C_Axial_L3.8mm_D2.6mm_P10.00mm_Horizontal
C15, C16, C17, C19, C21, C23, C27: 0.1u; C_Axial_L3.8mm_D2.6mm_P10.00mm_Horizontal
C18, C20, C22: 10u; C_Axial_L3.8mm_D2.6mm_P10.00mm_Horizontal
C24, C25: 33p; C_Axial_L3.8mm_D2.6mm_P10.00mm_Horizontal
C26, C29: 220p; C_Axial_L3.8mm_D2.6mm_P10.00mm_Horizontal
C28: 1000p; C_Axial_L3.8mm_D2.6mm_P10.00mm_Horizontal
C30, C31, C36, C37: NC; C_Axial_L3.8mm_D2.6mm_P10.00mm_Horizontal
C32, C33: 22p; C_Axial_L3.8mm_D2.6mm_P10.00mm_Horizontal
C34, C35: 100p; C_Axial_L3.8mm_D2.6mm_P10.00mm_Horizontal
CR1: MBR120; SDO_SOD-123FL498_OSI
D1: Charging_LED; LED_0603_1608Metric_Pad1.05x0.95mm_HandSolder
D2: Power_LED; LED_0603_1608Metric_Pad1.05x0.95mm_HandSolder
F1: Polyfuse 1A; Fuse_1206_3216Metric_Pad1.42x1.75mm_HandSolder
FB1: BLM21PG221; L_0603_1608Metric_Pad1.05x0.95mm_HandSolder
FB2, FB3: FerriteBead_Small; BEADC2012X145N
H1, H2, H3, H4: Hole_Pad; MountingHole_2.2mm_M2_Pad_Via
IC1: PN5321A3HN_C106,55; QFN50P600X600X100-41N-D; Mouser Part Number 771-PN5321A3HNC10
J1: USB_C_Receptacle_USB2.0_16P; USB_C_Receptacle_HRO_TYPE-C-31-M-12
J2, J3: Conn_01x20; PinSocket_1x20_P2.54mm_Vertical
J4, J5: Conn_02x03_Counter_Clockwise; PinHeader_2x03_P2.54mm_Vertical
JP1, JP2: Conn_01x03_Pin; PinHeader_1x03_P2.54mm_Vertical
JP3: PN532_SPI_CLK_JUMPER; TestPoint_2Pads_Pitch5.08mm_Drill1.3mm
JP4: PN532_SPI_MISO_JUMPER; TestPoint_2Pads_Pitch5.08mm_Drill1.3mm
JSTPH1: Battery Plug; JST_PH_S2B-PH-K_1x02_P2.00mm_Horizontal
L1, L2: 560n; L_Axial_L5.3mm_D2.2mm_P10.16mm_Horizontal_Vishay_IM-1
Q1: DMG3415U; SOT95P240X105-3N
Q2: UMH3N; SOT-363_SC-70-6
R1, R9, R12, R13: 10K; R_0402_1005Metric_Pad0.72x0.64mm_HandSolder
R2: 4.K; R_0402_1005Metric_Pad0.72x0.64mm_HandSolder
R3: 100k; R_0402_1005Metric_Pad0.72x0.64mm_HandSolder
R4, R5: 5k1; R_0402_1005Metric_Pad0.72x0.64mm_HandSolder
R6, R7: 1K; R_0402_1005Metric_Pad0.72x0.64mm_HandSolder
R8: 10k; R_0402_1005Metric_Pad0.72x0.64mm_HandSolder
R10, R11: 22R; R_0402_1005Metric_Pad0.72x0.64mm_HandSolder
R14, R15: 1.5; R_Axial_DIN0207_L6.3mm_D2.5mm_P10.16mm_Horizontal
R16: 1K; R_Axial_DIN0207_L6.3mm_D2.5mm_P10.16mm_Horizontal
R17: 1.69K; R_Axial_DIN0207_L6.3mm_D2.5mm_P10.16mm_Horizontal
R18, R19: NC; R_Axial_DIN0207_L6.3mm_D2.5mm_P10.16mm_Horizontal
SW1: Power_Switch; SW_DIP_SPSTx01_Slide_9.78x4.72mm_W7.62mm_P2.54mm
SW2: Reset Button; SW_Push_SPST_NO_Alps_SKRK
TP1: RX; TestPoint_Pad_D1.5mm
TP2: TX2_POST; TestPoint_Pad_D1.5mm
TP3: TX1_POST; TestPoint_Pad_D1.5mm
TP4, TP7: TGND; TestPoint_Pad_D1.5mm
TP5: TX2_PRE; TestPoint_Pad_D1.5mm
TP6: TX1_PRE; TestPoint_Pad_D1.5mm
U1: MCP73831-2-OT; SOT-23-5
U2: AP2112K-3.3; SOT-23-5
U3: USBLC6-2P6; SOT-666
U4: CP2104; QFN-24-1EP_4x4mm_P0.5mm_EP2.6x2.6mm
U6: AMS1117-5.0; SOT-223-3_TabPin2
U8: ESP32-WROOM-32U
Y1: 27.12M; XTAL_7M-27.120MAAJ-T

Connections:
+3.3VA: C11.1, C13.1, R8.1, U4.5 (VIO), U4.6 (VDD)
+3V3: C2.1, C5.1, C9.1, C12.1, C15.1, C16.1, C17.1, C19.1, FB2.1, FB3.1, IC1.23 (PVDD), IC1.39 (DVDD), IC1.40 (VBAT), J2.1, J2.3, J3.20, JP1.1, JP2.1, R7.1, R9.1, U2.5 (VOUT), U8.2 (VDD)
+5V: C3.1, C6.1, C7.1, C14.1, F1.2, J2.5, J3.18, U3.5 (VBUS), U4.7 (REGIN), U4.8 (VBUS), U6.2 (VO)
+V_BAT: C4.1, JSTPH1.2, R12.1, SW1.2 (B), U1.3 (V_{BAT})
+V_USB: CR1.2, D1.2 (A), FB1.1, J1.A4 (VBUS), J1.A9 (VBUS), J1.B4 (VBUS), J1.B9 (VBUS), Q1.1 (G), R1.1, U1.4 (V_{DD})
/DTR: Q2.1 (E1), Q2.5 (B2), U4.23 (~DTR)
/EN/RESET: C10.1, Q2.4 (E2), R9.2, SW2.2, U8.3 (EN)
/GPIO4_A5: J3.5, U8.26 (IO4)
/GPIO06_SPI_CLK: J2.13, JP3.2 (B), U8.20 (SCK/CLK)
/GPIO07_SPI_MISO: J2.9, JP4.2 (B), U8.21 (SDO/SD0)
/GPIO08_SPI_MOSI: J2.10, J4.4, U8.22 (SDI/SD1)
/GPIO09_SPI_HD: J2.11, U8.17 (SHD/SD2)
/GPIO10_SPI_WP: J2.12, U8.18 (SWP/SD3)
/GPIO11_SPI_CS: J2.14, J5.4, U8.19 (SCS/CMD)
/GPIO12_A11: J3.6, U8.14 (IO12)
/GPIO13_A12: J3.7, U8.16 (IO13)
/GPIO14_A6: J3.8, U8.13 (IO14)
/GPIO15_A8: J3.9, U8.23 (IO15)
/GPIO16_UART2_RX: J3.10, J4.6, U8.27 (IO16)
/GPIO17_UART2_TX: J3.11, J5.6, U8.28 (IO17)
/GPIO18: J3.12, U8.30 (IO18)
/GPIO19: J3.13, U8.31 (IO19)
/GPIO21_I2C_SDA: J2.7, J3.15, J4.2, U8.33 (IO21)
/GPIO22_I2C_SCL: J2.8, J3.16, J5.2, U8.36 (IO22)
/GPIO23: J3.14, U8.37 (IO23)
/GPIO25_A1: J2.15, U8.10 (IO25)
/GPIO26_A0: J2.16, U8.11 (IO26)
/GPIO27_A10: J2.17, U8.12 (IO27)
/GPIO32_A7: J2.18, U8.8 (IO32)
/GPIO33_A9: J2.19, U8.9 (IO33)
/GPIO34_A2: J2.20, U8.6 (IO34)
/GPIO35_A13: J3.3, U8.7 (IO35)
/GPIO36_A4: J3.4, U8.4 (SENSOR_VP)
/GPIO39_A3_BAT_%: R12.2, R13.1, U8.5 (SENSOR_VN)
/IO0: Q2.6 (C1), U8.25 (IO0)
/PN532_AUX1: IC1.12 (AUX1)
/PN532_AUX2: IC1.13 (AUX2)
/PN532_IRQ: IC1.25 (P70_IRQ)
/PN532_MOSI_SDA_TX: IC1.28 (MOSI_/_SDA_/_HSU_TX), J4.1, J4.3, J4.5
/PN532_NSS_SCL_RX: IC1.27 (NSS_/_P50_SCL_/_HSU_RX), J5.1, J5.3, J5.5
/PN532_P30_UART_RX: IC1.24 (P30_/UART_RX)
/PN532_P31_UART_TX: IC1.31 (P31_/_UART_TX)
/PN532_P32: IC1.32 (P32_INT0)
/PN532_P33: IC1.33 (P33_INT1)
/PN532_P34_SIC_CLK: IC1.34 (P34_/_SIC_CLK)
/PN532_P35: IC1.19 (P35)
/PN532_RSTOUT_N: IC1.26 (RSTOUT_N)
/PN532_RSTPD_N: IC1.38 (RSTPD_N)
/PN532_SEL0: IC1.16 (I0), JP1.2
/PN532_SEL1: IC1.17 (I1), JP2.2
/PN532_SIGIN: IC1.36 (SIGIN)
/PN532_SIGOUT: IC1.35 (SIGOUT)
/RTS: Q2.2 (B1), Q2.3 (C2), U4.19 (~RTS)
/RX: R10.2, U8.34 (RXD0/IO3)
/TX: R11.2, U8.35 (TXD0/IO1)
GND: C1.2, C2.2, C3.2, C4.2, C5.2, C6.2, C7.2, C8.2, C9.2, C10.2, C11.2, C12.2, C13.2, C14.2, C15.2, C16.2, C17.2, C18.1, C19.2, C20.2, C21.2, C22.2, C23.2, C24.1, C25.2, C26.1, C27.2, C29.2, C34.1, C35.2, C36.1, C37.2, D2.1 (K), H1.1, H2.1, H3.1, H4.1, IC1.1 (DVSS), IC1.3 (TVSS1), IC1.7 (TVSS2), IC1.11 (AVSS), IC1.18 (TESTEN), IC1.41 (EPAD), J1.A1 (GND), J1.A12 (GND), J1.B1 (GND), J1.B12 (GND), J1.S1 (SHIELD), J2.2, J2.4, J2.6, J3.1, J3.2, J3.17, J3.19, JP1.3, JP2.3, JSTPH1.1, R1.2, R2.2, R4.2, R5.2, R13.2, R18.1, R19.2, SW2.1, TP4.1, TP7.1, U1.2 (V_{SS}), U2.2 (GND), U3.2 (GND), U4.2 (GND), U4.25 (GND), U6.1 (GND), U8.1 (GND), U8.15 (GND), U8.38 (GND), U8.39 (GND)
unnamed: C26.2, C31.1, C32.1, L1.1, R17.1, TP1.1, TP2.1
unnamed: C28.1, R17.2
unnamed: C29.1, C30.2, C33.2, L2.1, TP3.1
unnamed: C30.1, C33.1, C35.1, C37.1, R15.1
unnamed: C31.2, C32.2, C34.2, C36.2, R14.2
unnamed: D1.1 (K), R6.2
unnamed: D2.2 (A), R7.2
unnamed: F1.1, FB1.2
unnamed: C22.1, C23.1, FB3.2, IC1.8 (AVDD)
unnamed: IC1.29 (MISO_/_P71), JP4.1 (A)
unnamed: C24.2, IC1.14 (OSCIN), Y1.1
unnamed: C25.1, IC1.15 (OSCOUT), Y1.2
unnamed: C28.2, IC1.10 (RX), R16.2
unnamed: IC1.30 (SCK_/_P72), JP3.1 (A)
unnamed: C18.2, IC1.37 (SVDD)
unnamed: C20.1, C21.1, FB2.2, IC1.5 (TVDD)
unnamed: IC1.4 (TX1), L2.2
unnamed: IC1.6 (TX2), L1.2
unnamed: C27.1, IC1.9 (VMID), R16.1
unnamed: J1.A5 (CC1), R5.1
unnamed: J1.B5 (CC2), R4.1
unnamed: J1.A6 (D+), J1.B6 (D+), U3.3 (I/O2)
unnamed: J1.A7 (D-), J1.B7 (D-), U3.1 (I/O1)
unnamed: Q1.3 (D), SW1.1 (A)
unnamed: C1.1, CR1.1, Q1.2 (S), R3.1, U2.1 (VIN), U6.3 (VI)
unnamed: R14.1, R18.2, TP5.1
unnamed: R15.2, R19.1, TP6.1
unnamed: R2.1, U1.5 (PROG)
unnamed: R6.1, U1.1 (STAT)
unnamed: R3.2, U2.3 (EN)
unnamed: U3.4 (I/O2), U4.3 (D+)
unnamed: U3.6 (I/O1), U4.4 (D-)
unnamed: R11.1, U4.20 (RXD)
unnamed: R10.1, U4.21 (TXD)
unnamed: C8.1, U4.16 (VPP)
unnamed: R8.2, U4.9 (~RST)

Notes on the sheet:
SPI
I2C
SEL0
UART
SEL1
PN532 AND ANTENNA
LIPO CHARGING
Headers
ESP32-WROOM-32U does not have a built in PCB antenna, and requires an external one. This was chosen to remove the need for a 'keep out zone' on the pcb.
USB TYPE-C TO UART
ESP32 AND AUTORESTART
UART, I2C, SPI Selection
POWER FLAGS
MOUNTING
POWER AND FILTERING

Board: 2 copper layers, 97 parts (0 on the bottom side), 78 nets, no tracks yet.

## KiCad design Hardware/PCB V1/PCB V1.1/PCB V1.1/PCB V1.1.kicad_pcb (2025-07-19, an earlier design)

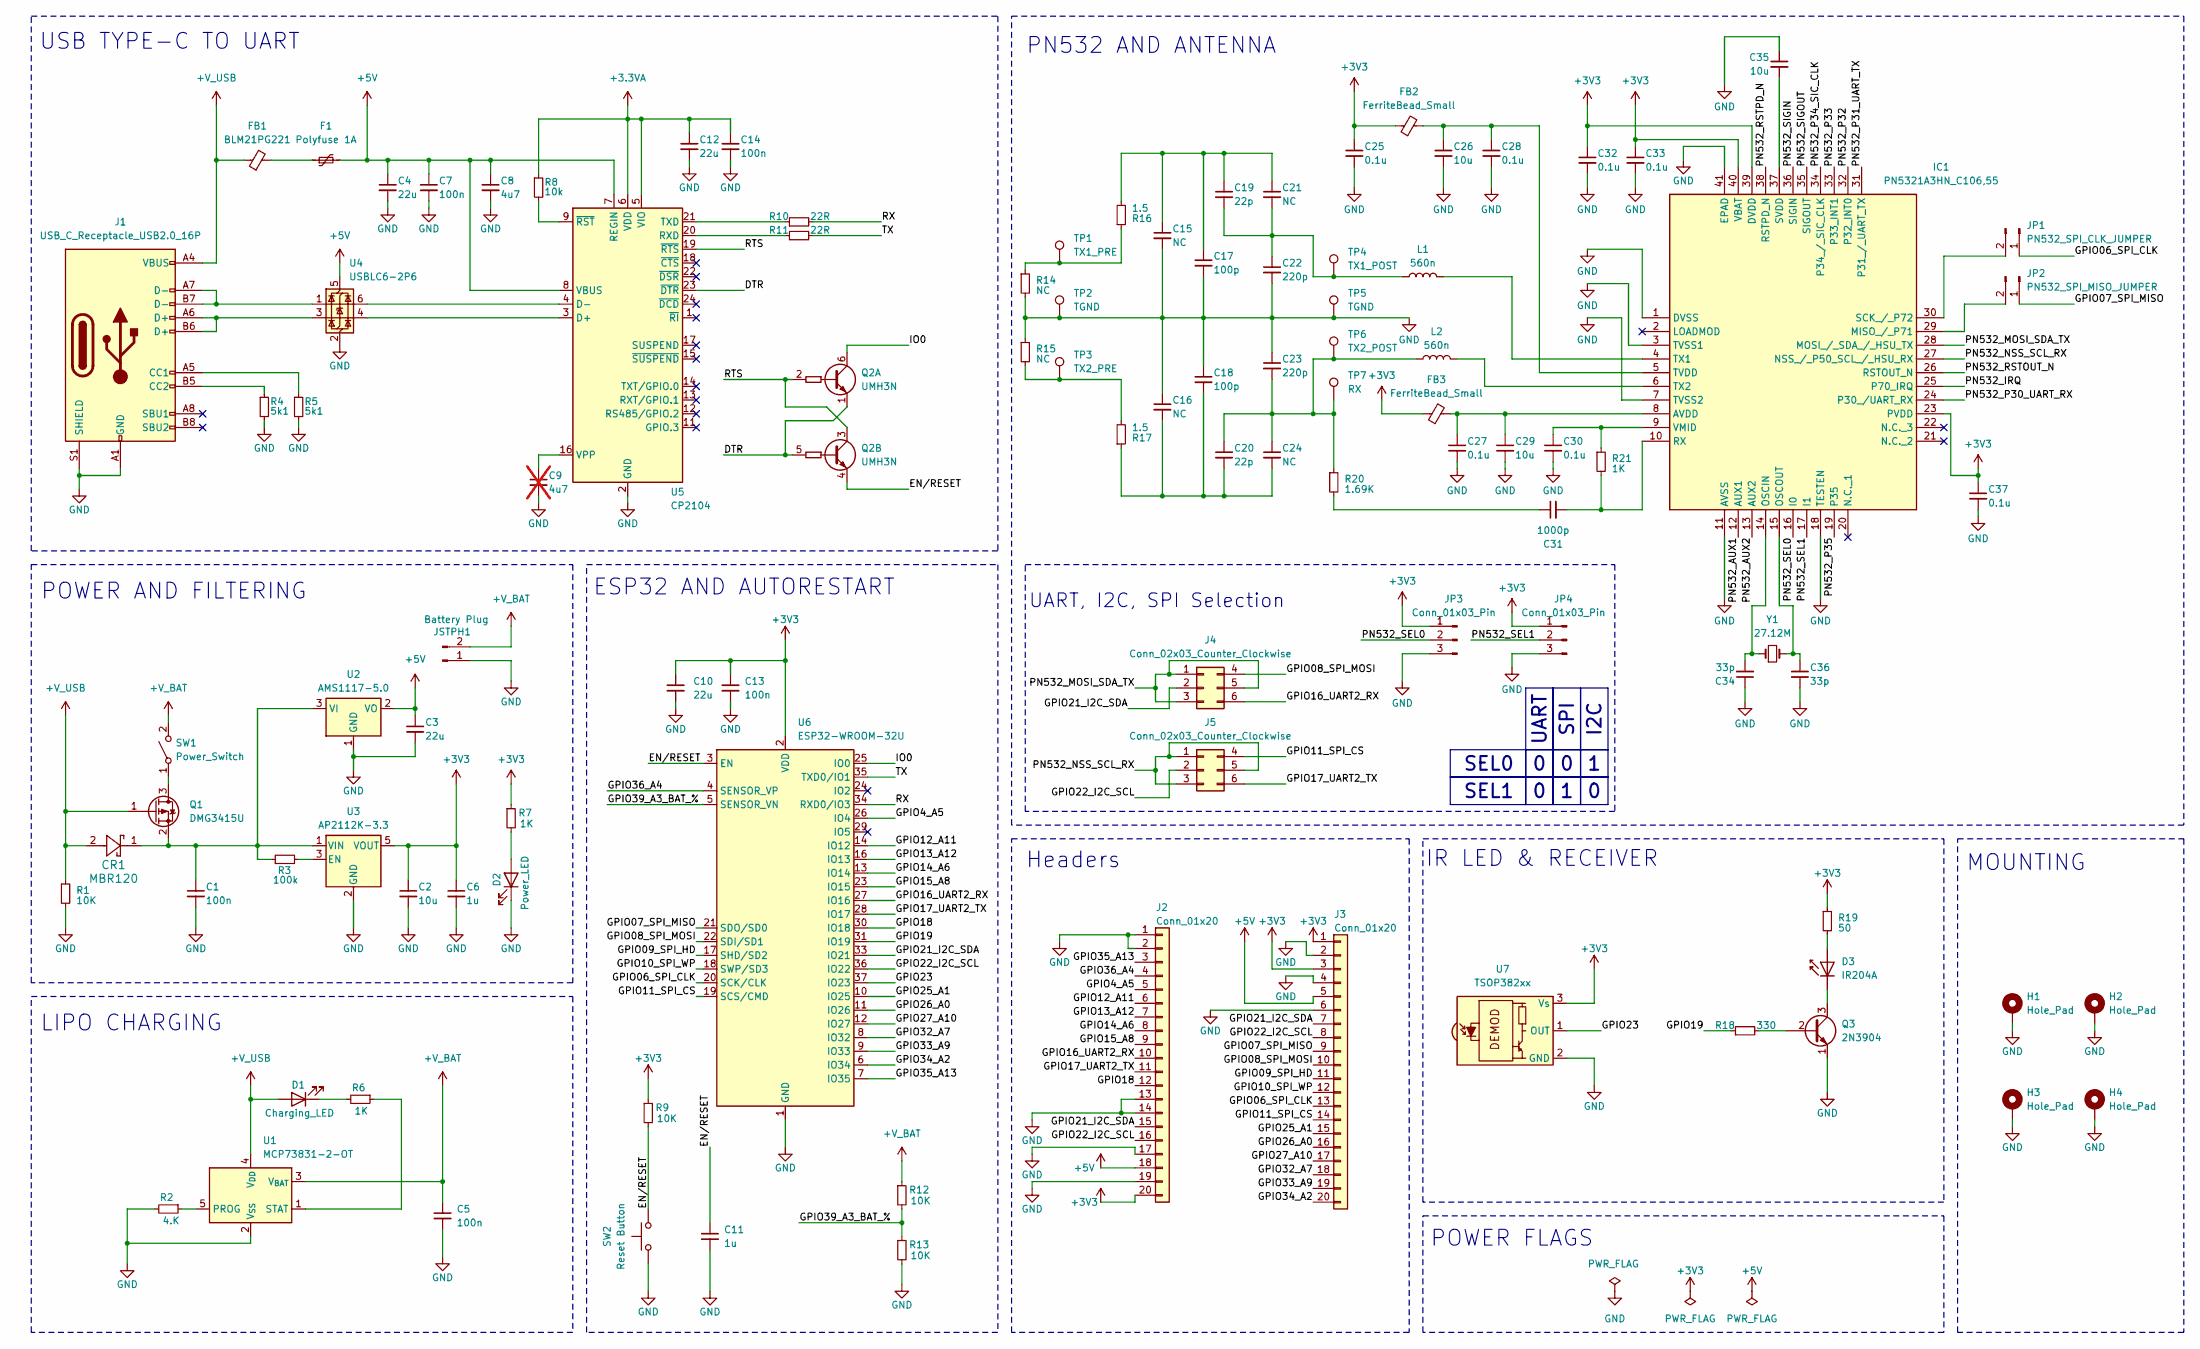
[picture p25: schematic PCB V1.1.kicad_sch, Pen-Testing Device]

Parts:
C1, C7, C14: 100n; C_0805_2012Metric_Pad1.18x1.45mm_HandSolder
C2: 10u; C_0805_2012Metric_Pad1.18x1.45mm_HandSolder
C3, C4, C10, C12: 22u; C_0805_2012Metric_Pad1.18x1.45mm_HandSolder
C5, C13: 100n; C_0402_1005Metric_Pad0.74x0.62mm_HandSolder
C6: 1u; C_0805_2012Metric_Pad1.18x1.45mm_HandSolder
C8: 4u7; C_0805_2012Metric_Pad1.18x1.45mm_HandSolder
C9: 4u7; C_0805_2012Metric_Pad1.18x1.45mm_HandSolder; not fitted
C11: 1u; C_0402_1005Metric_Pad0.74x0.62mm_HandSolder
C15, C16, C21, C24: NC; C_Disc_D7.5mm_W2.5mm_P5.00mm
C17, C18: 100p; C_Disc_D7.5mm_W2.5mm_P5.00mm
C19, C20: 22p; C_Disc_D7.5mm_W2.5mm_P5.00mm
C22, C23: 220p; C_Disc_D7.5mm_W2.5mm_P5.00mm
C25, C27, C28, C30, C32, C33, C37: 0.1u; C_Disc_D7.5mm_W2.5mm_P5.00mm
C26, C29, C35: 10u; C_Disc_D7.5mm_W2.5mm_P5.00mm
C31: 1000p; C_Disc_D7.5mm_W2.5mm_P5.00mm
C34, C36: 33p; C_Disc_D7.5mm_W2.5mm_P5.00mm
CR1: MBR120; SDO_SOD-123FL498_OSI
D1: Charging_LED; LED_0603_1608Metric_Pad1.05x0.95mm_HandSolder
D2: Power_LED; LED_0603_1608Metric_Pad1.05x0.95mm_HandSolder
D3: IR204A; LED_D3.0mm_IRBlack
F1: Polyfuse 1A; Fuse_1206_3216Metric_Pad1.42x1.75mm_HandSolder
FB1: BLM21PG221; L_0603_1608Metric_Pad1.05x0.95mm_HandSolder
FB2, FB3: FerriteBead_Small; BEADC2012X145N
H1, H2, H3, H4: Hole_Pad; MountingHole_2.2mm_M2_Pad_Via
IC1: PN5321A3HN_C106,55; QFN50P600X600X100-41N-D; Mouser Part Number 771-PN5321A3HNC10
J1: USB_C_Receptacle_USB2.0_16P; USB_C_Receptacle_HRO_TYPE-C-31-M-12
J2, J3: Conn_01x20; PinSocket_1x20_P2.54mm_Vertical
J4, J5: Conn_02x03_Counter_Clockwise; PinHeader_2x03_P2.54mm_Vertical
JP1: PN532_SPI_CLK_JUMPER; PinHeader_2x01_P2.54mm_Vertical
JP2: PN532_SPI_MISO_JUMPER; PinHeader_2x01_P2.54mm_Vertical
JP3, JP4: Conn_01x03_Pin; PinHeader_1x03_P2.54mm_Vertical
JSTPH1: Battery Plug; JST_PH_S2B-PH-K_1x02_P2.00mm_Horizontal
L1, L2: 560n; L_Axial_L5.3mm_D2.2mm_P10.16mm_Horizontal_Vishay_IM-1
Q1: DMG3415U; SOT95P240X105-3N
Q2: UMH3N; SOT-363_SC-70-6
Q3: 2N3904; TO-92_Inline
R1, R9, R12, R13: 10K; R_0402_1005Metric_Pad0.72x0.64mm_HandSolder
R2: 4.K; R_0402_1005Metric_Pad0.72x0.64mm_HandSolder
R3: 100k; R_0402_1005Metric_Pad0.72x0.64mm_HandSolder
R4, R5: 5k1; R_0402_1005Metric_Pad0.72x0.64mm_HandSolder
R6, R7: 1K; R_0402_1005Metric_Pad0.72x0.64mm_HandSolder
R8: 10k; R_0402_1005Metric_Pad0.72x0.64mm_HandSolder
R10, R11: 22R; R_0402_1005Metric_Pad0.72x0.64mm_HandSolder
R14, R15: NC; R_0201_0603Metric_Pad0.64x0.40mm_HandSolder
R16, R17: 1.5; R_Axial_DIN0207_L6.3mm_D2.5mm_P10.16mm_Horizontal
R18: 330; R_Axial_DIN0207_L6.3mm_D2.5mm_P10.16mm_Horizontal
R19: 50; R_Axial_DIN0207_L6.3mm_D2.5mm_P10.16mm_Horizontal
R20: 1.69K; R_Axial_DIN0207_L6.3mm_D2.5mm_P10.16mm_Horizontal
R21: 1K; R_Axial_DIN0207_L6.3mm_D2.5mm_P10.16mm_Horizontal
SW1: Power_Switch; SW_DIP_SPSTx01_Slide_9.78x4.72mm_W7.62mm_P2.54mm
SW2: Reset Button; SW_Push_SPST_NO_Alps_SKRK
TP1: TX1_PRE; TestPoint_Pad_D1.5mm
TP2, TP5: TGND; TestPoint_Pad_D1.5mm
TP3: TX2_PRE; TestPoint_Pad_D1.5mm
TP4: TX1_POST; TestPoint_Pad_D1.5mm
TP6: TX2_POST; TestPoint_Pad_D1.5mm
TP7: RX; TestPoint_Pad_D1.5mm
U1: MCP73831-2-OT; SOT-23-5
U2: AMS1117-5.0; SOT-223-3_TabPin2
U3: AP2112K-3.3; SOT-23-5
U4: USBLC6-2P6; SOT-666
U5: CP2104; QFN-24-1EP_4x4mm_P0.5mm_EP2.6x2.6mm
U6: ESP32-WROOM-32U
U7: TSOP382xx; Vishay_MINICAST-3Pin
Y1: 27.12M; XTAL_7M-27.120MAAJ-T

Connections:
+3.3VA: C12.1, C14.1, R8.1, U5.5 (VIO), U5.6 (VDD)
+V_BAT: C5.1, JSTPH1.2, R12.1, SW1.2 (B), U1.3 (V_{BAT})
+V_USB: CR1.2, D1.2 (A), FB1.1, J1.A4 (VBUS), J1.A9 (VBUS), J1.B4 (VBUS), J1.B9 (VBUS), Q1.1 (G), R1.1, U1.4 (V_{DD})
/DTR: Q2.1 (E1), Q2.5 (B2), U5.23 (~DTR)
/EN/RESET: C11.1, Q2.4 (E2), R9.2, SW2.2, U6.3 (EN)
/GPIO4_A5: J2.5, U6.26 (IO4)
/GPIO06_SPI_CLK: J3.13, JP1.1, U6.20 (SCK/CLK)
/GPIO07_SPI_MISO: J3.9, JP2.1, U6.21 (SDO/SD0)
/GPIO08_SPI_MOSI: J3.10, J4.4, U6.22 (SDI/SD1)
/GPIO09_SPI_HD: J3.11, U6.17 (SHD/SD2)
/GPIO10_SPI_WP: J3.12, U6.18 (SWP/SD3)
/GPIO11_SPI_CS: J3.14, J5.4, U6.19 (SCS/CMD)
/GPIO12_A11: J2.6, U6.14 (IO12)
/GPIO13_A12: J2.7, U6.16 (IO13)
/GPIO14_A6: J2.8, U6.13 (IO14)
/GPIO15_A8: J2.9, U6.23 (IO15)
/GPIO16_UART2_RX: J2.10, J4.6, U6.27 (IO16)
/GPIO17_UART2_TX: J2.11, J5.6, U6.28 (IO17)
/GPIO18: J2.12, U6.30 (IO18)
/GPIO19: R18.1, U6.31 (IO19)
/GPIO21_I2C_SDA: J2.15, J3.7, J4.2, U6.33 (IO21)
/GPIO22_I2C_SCL: J2.16, J3.8, J5.2, U6.36 (IO22)
/GPIO23: U6.37 (IO23), U7.1 (OUT)
/GPIO25_A1: J3.15, U6.10 (IO25)
/GPIO26_A0: J3.16, U6.11 (IO26)
/GPIO27_A10: J3.17, U6.12 (IO27)
/GPIO32_A7: J3.18, U6.8 (IO32)
/GPIO33_A9: J3.19, U6.9 (IO33)
/GPIO34_A2: J3.20, U6.6 (IO34)
/GPIO35_A13: J2.3, U6.7 (IO35)
/GPIO36_A4: J2.4, U6.4 (SENSOR_VP)
/GPIO39_A3_BAT_%: R12.2, R13.1, U6.5 (SENSOR_VN)
/IO0: Q2.6 (C1), U6.25 (IO0)
/PN532_AUX1: IC1.12 (AUX1)
/PN532_AUX2: IC1.13 (AUX2)
/PN532_IRQ: IC1.25 (P70_IRQ)
/PN532_MOSI_SDA_TX: IC1.28 (MOSI_/_SDA_/_HSU_TX), J4.1, J4.3, J4.5
/PN532_NSS_SCL_RX: IC1.27 (NSS_/_P50_SCL_/_HSU_RX), J5.1, J5.3, J5.5
/PN532_P30_UART_RX: IC1.24 (P30_/UART_RX)
/PN532_P31_UART_TX: IC1.31 (P31_/_UART_TX)
/PN532_P32: IC1.32 (P32_INT0)
/PN532_P33: IC1.33 (P33_INT1)
/PN532_P34_SIC_CLK: IC1.34 (P34_/_SIC_CLK)
/PN532_P35: IC1.19 (P35)
/PN532_RSTOUT_N: IC1.26 (RSTOUT_N)
/PN532_RSTPD_N: IC1.38 (RSTPD_N)
/PN532_SEL0: IC1.16 (I0), JP3.2
/PN532_SEL1: IC1.17 (I1), JP4.2
/PN532_SIGIN: IC1.36 (SIGIN)
/PN532_SIGOUT: IC1.35 (SIGOUT)
/RTS: Q2.2 (B1), Q2.3 (C2), U5.19 (~RTS)
/RX: R10.2, U6.34 (RXD0/IO3)
/TX: R11.2, U6.35 (TXD0/IO1)
GND: C1.2, C2.2, C3.2, C4.2, C5.2, C6.2, C7.2, C8.2, C9.2, C10.2, C11.2, C12.2, C13.2, C14.2, C15.2, C16.1, C17.2, C18.1, C22.2, C23.1, C25.2, C26.2, C27.2, C28.2, C29.2, C30.2, C32.2, C33.2, C34.1, C35.1, C36.2, C37.2, D2.1 (K), H1.1, H2.1, H3.1, H4.1, IC1.1 (DVSS), IC1.3 (TVSS1), IC1.7 (TVSS2), IC1.11 (AVSS), IC1.18 (TESTEN), IC1.41 (EPAD), J1.A1 (GND), J1.A12 (GND), J1.B1 (GND), J1.B12 (GND), J1.S1 (SHIELD), J2.1, J2.2, J2.13, J2.14, J2.17, J2.19, J3.2, J3.4, J3.6, JP3.3, JP4.3, JSTPH1.1, Q3.1 (E), R1.2, R2.2, R4.2, R5.2, R13.2, R14.2, R15.1, SW2.1, TP2.1, TP5.1, U1.2 (V_{SS}), U2.1 (GND), U3.2 (GND), U4.2 (GND), U5.2 (GND), U5.25 (GND), U6.1 (GND), U6.15 (GND), U6.38 (GND), U6.39 (GND), U7.2 (GND); also elsewhere on the board
unnamed: C15.1, C17.1, C19.1, C21.1, R16.2
unnamed: C16.2, C18.2, C20.2, C24.2, R17.1
unnamed: C19.2, C21.2, C22.1, L1.1, TP4.1
unnamed: C20.1, C23.2, C24.1, L2.1, R20.1, TP6.1, TP7.1
unnamed: C31.1, R20.2
unnamed: D1.1 (K), R6.2
unnamed: D2.2 (A), R7.2
unnamed: D3.2 (A), R19.2
unnamed: D3.1 (K), Q3.3 (C)
unnamed: F1.1, FB1.2
unnamed: C27.1, C29.1, FB3.2, IC1.8 (AVDD)
unnamed: IC1.29 (MISO_/_P71), JP2.2
unnamed: C34.2, IC1.14 (OSCIN), Y1.1
unnamed: C36.1, IC1.15 (OSCOUT), Y1.2
unnamed: C31.2, IC1.10 (RX), R21.2
unnamed: IC1.30 (SCK_/_P72), JP1.2
unnamed: C35.2, IC1.37 (SVDD)
unnamed: C26.1, C28.1, FB2.2, IC1.5 (TVDD)
unnamed: IC1.4 (TX1), L1.2
unnamed: IC1.6 (TX2), L2.2
unnamed: C30.1, IC1.9 (VMID), R21.1
unnamed: J1.A5 (CC1), R5.1
unnamed: J1.B5 (CC2), R4.1
unnamed: J1.A6 (D+), J1.B6 (D+), U4.3 (I/O2)
unnamed: J1.A7 (D-), J1.B7 (D-), U4.1 (I/O1)
unnamed: Q1.3 (D), SW1.1 (A)
unnamed: C1.1, CR1.1, Q1.2 (S), R3.1, U2.3 (VI), U3.1 (VIN)
unnamed: Q3.2 (B), R18.2
unnamed: R14.1, R16.1, TP1.1
unnamed: R15.2, R17.2, TP3.1
unnamed: R2.1, U1.5 (PROG)
unnamed: R6.1, U1.1 (STAT)
unnamed: R3.2, U3.3 (EN)
unnamed: U4.4 (I/O2), U5.3 (D+)
unnamed: U4.6 (I/O1), U5.4 (D-)
unnamed: R11.1, U5.20 (RXD)
unnamed: R10.1, U5.21 (TXD)
unnamed: C9.1, U5.16 (VPP)
unnamed: R8.2, U5.9 (~RST)

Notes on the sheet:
I2C
UART
SPI
SEL0
SEL1
LIPO CHARGING
IR LED & RECEIVER
UART, I2C, SPI Selection
Headers
USB TYPE-C TO UART
PN532 AND ANTENNA
ESP32 AND AUTORESTART
POWER FLAGS
MOUNTING
POWER AND FILTERING

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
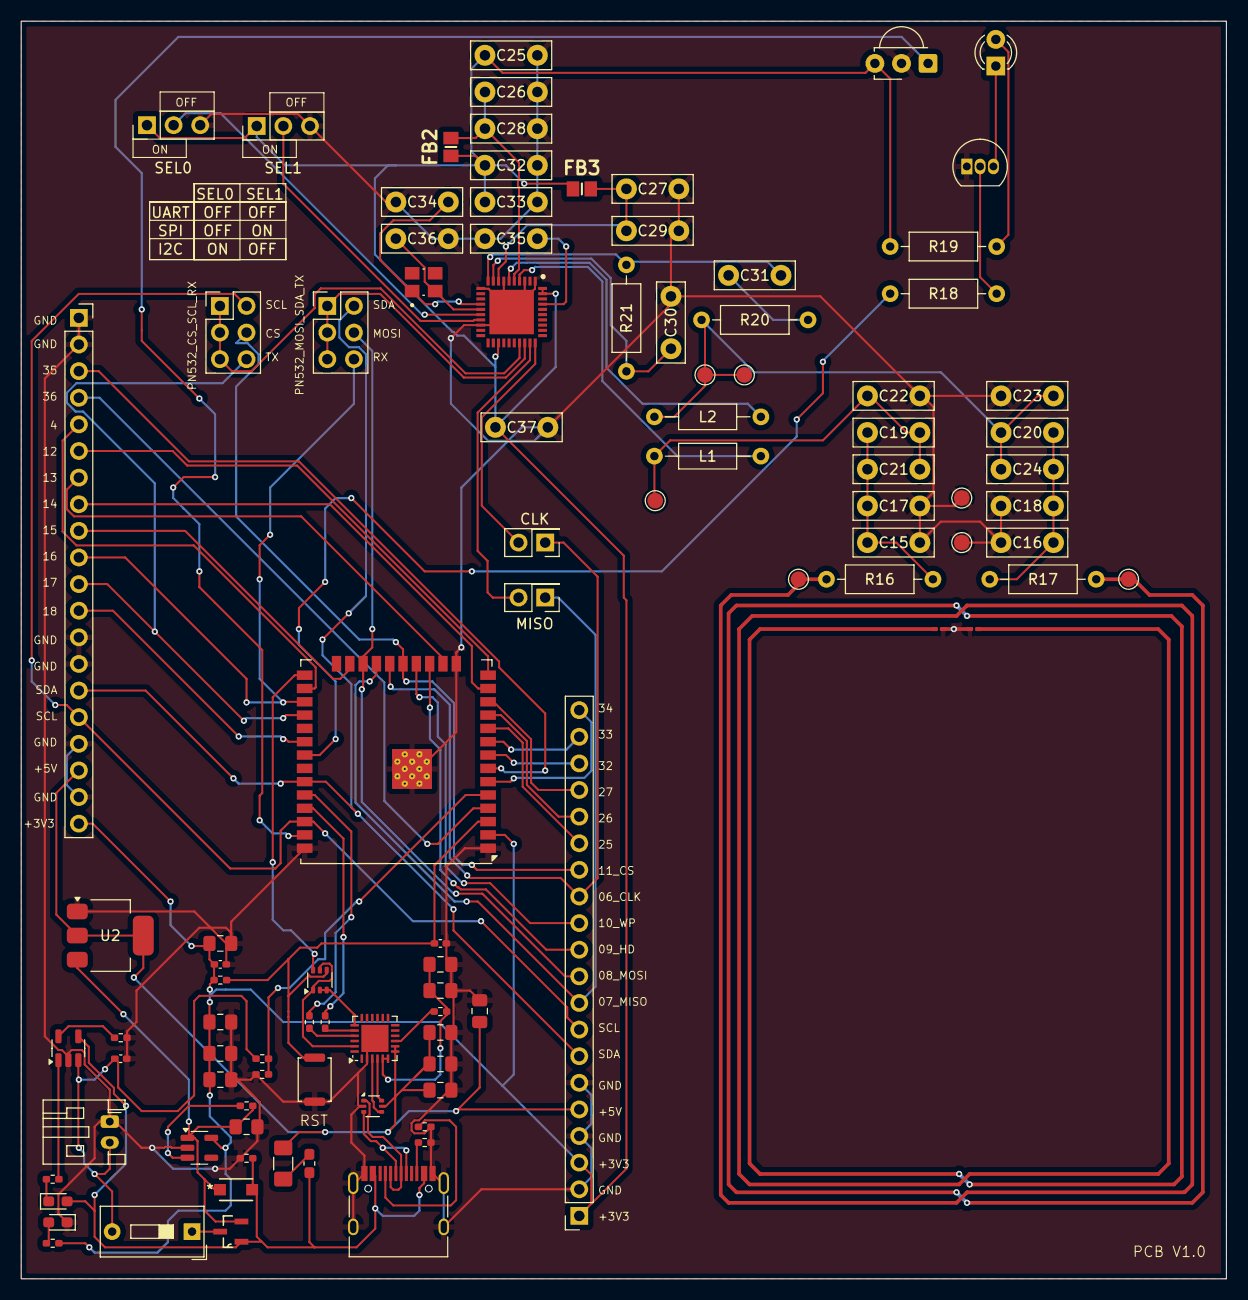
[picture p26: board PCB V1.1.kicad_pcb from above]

Board: 2 copper layers, 115.0 x 120.0 mm, 99 parts (0 on the bottom side), 81 nets.

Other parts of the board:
C8#2: 4u7; C_0805_2012Metric_Pad1.18x1.45mm_HandSolder

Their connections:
GND: C8#2.2; also elsewhere on the board

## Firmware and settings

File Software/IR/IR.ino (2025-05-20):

// IR.ino

/**
 * @file IR.ino
 * @author Jonathan Woolf
 * @brief Test program for IR attack tools
 * @version 1.0
 * @date 2025-03-05
 *
 * @copyright Copyright (c) 2025
 *
 */

#include <FS.h>

#include <string>
#include <vector>

#include "IRTools.h"
#include "SD.h"
#include "SPI.h"

std::vector<IRCommand> deviceCommands;  // Declare deviceCommands globally

IRTools *irTools = new IRTools();  // Create an instance of IRTools
SPIClass spiBus = SPIClass(HSPI);  // Use HSPI for the SD card

uint16_t rawDataACOn[259] = {3302, 1644, 408, 419, 410, 416, 413, 1233, 405, 423, 406, 1239, 409, 419, 410, 417, 412, 415, 414, 1232, 406, 1241, 407, 419, 410, 417, 412, 416, 413, 1233, 405, 1241, 407, 394, 435, 419, 410, 417, 412, 416, 413, 387, 432, 422, 407, 420, 409, 418, 411, 416, 413, 415, 404, 423, 406, 421, 408, 420, 409, 1237, 411, 416, 413, 413, 406, 422, 407, 420, 409, 418, 411, 417, 412, 415, 414, 1232, 406, 421, 408, 420, 409, 418, 411, 416, 413, 1232, 406, 1240, 408, 1238, 410, 1236, 412, 1234, 414, 1232, 406, 1240, 408, 1238, 410, 417, 412, 416, 413, 1233, 405, 422, 407, 421, 408, 419, 410, 417, 412, 414, 404, 397, 432, 421, 408, 420, 409, 1237, 411, 1234, 414, 387, 432, 422, 407, 1239, 409, 418, 411, 416, 413, 414, 405, 423, 406, 1240, 408, 1237, 411, 417, 412, 415, 414, 414, 405, 422, 407, 421, 408, 418, 411, 416, 413, 414, 405, 423, 406, 421, 408, 419, 410, 417, 412, 416, 413, 414, 405, 422, 407, 421, 408, 419, 410, 416, 413, 414, 405, 423, 406, 421, 408, 419, 410, 417, 412, 416, 413, 414, 404, 423, 406, 421, 408, 419, 410, 417, 412, 414, 405, 423, 406, 421, 408, 419, 410, 417, 412, 416, 413, 414, 404, 423, 406, 421, 408, 419, 410, 417, 412, 416, 413, 413, 406, 422, 407, 420, 409, 418, 411, 416, 413, 1233, 405, 422, 407, 421, 408, 1237, 411, 1235, 413, 1206, 432, 1240, 408, 420, 409, 418, 411, 1235, 413, 415, 414};

void setup() {
    Serial.begin(115200);
    delay(1000);
    digitalWrite(48, HIGH);
    digitalWrite(5, HIGH);
    digitalWrite(6, HIGH);
    digitalWrite(8, HIGH);
    digitalWrite(1, HIGH);
    digitalWrite(36, HIGH);
    // delay(250);
    // Start the SPI bus with the specified pins
    spiBus.begin(39, 41, 40, 42);  // SCK, MISO, MOSI, CS pins
    // delay(250);
    // digitalWrite(42, LOW);
    if (!SD.begin(42, spiBus)) {  // Initialize the SD card with the CS pin and SPI bus
        Serial.println("Card Mount Failed");
        return;
    }

    irTools->init(SD);

    Serial.println("Loading avalible device types:");
    irTools->findDeviceTypes();

    std::vector<String> deviceTypes = irTools->getDeviceTypes();

    for (int i = 0; i < deviceTypes.size(); i++) {
        Serial.printf("%d. Device Type: %s\n", i, deviceTypes[i].c_str());
    }

    Serial.println("\nLoading avalible brands:");
    irTools->findDeviceBrands(44);

    std::vector<String> deviceBrands = irTools->getDeviceBrands();

    for (int i = 0; i < deviceBrands.size(); i++) {
        Serial.printf("%d. Device Brand: %s\n", i, deviceBrands[i].c_str());
    }

    irTools->findDevices(36);

    std::vector<String> devices = irTools->getDevices();

    // Print the device name
    Serial.printf("\nDevice Name: %s\n", devices[0].c_str());

    irTools->findDeviceCommands(0);
    deviceCommands = irTools->getDeviceCommands();

    for (int i = 0; i < deviceCommands.size(); i++) {
        Serial.printf("%d. Device Command: %s\n", i, deviceCommands[i].commandName.c_str());
    }
    Serial.println("");
}

void loop() {
    // Get user input for device command
    int deviceCommandIndex = 0;
    Serial.println("Enter the device command index: ");
    while (Serial.available() == 0) {
    }
    deviceCommandIndex = Serial.parseInt();
    Serial.printf("Device Command Index: %d\n", deviceCommandIndex);

    // Send the IR command
    if (irTools != nullptr) {
        irTools->sendIRCommand(deviceCommands[deviceCommandIndex]);
    } else {
        Serial.println("IRTools instance not initialized.");
    }

    delay(100);

    // Clear the input
    while (Serial.available() > 0) {
        Serial.read();
    }

    // irTools->captureIR(15);
    // irTools->sendRawIR(rawDataACOn, 259, 38);
}

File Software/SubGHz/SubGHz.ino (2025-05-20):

// SubGHz.ino

/**
 * @file SubGHz.ino
 * @author Jonathan Woolf
 * @brief Test program for Sub-GHz attack tools
 * @version 1.0
 * @date 2025-04-14
 *
 * @copyright Copyright (c) 2025
 *
 */
#include "SPI.h"
#include "SubGHzTools.h"

SubGHzTools subGHzTools;  // Create an instance of SubGHzTools

void setup() {
    Serial.begin(115200);
    delay(500);

    SPI.begin(39, 41, 40, 8);  // Initialize SPI with custom pins

    delay(250);

    subGHzTools.init();

    // Jam for 10 seconds
    subGHzTools.startJamming();
    Serial.println("Jamming started");
    unsigned long startTime = millis();
    while (millis() - startTime < 10000) {
        subGHzTools.runAction();
    }
    subGHzTools.stopJamming();
    Serial.println("Jamming stopped");

    // delay(5000);

    // Listen until raw data is received
    // subGHzTools.captureRaw(1);
    // Serial.println("Done");

    // delay(5000);

    // // Transmit the recorded raw data
    // subGHzTools.transmitRaw(1);
}

void loop() {
    subGHzTools.runAction();
    // Nothing to do here
}

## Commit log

2025-03-27 Update IR pin assignment
2025-04-15 Jamming and recording / playback of raw data working
    [SubGHz.ino, SubGHzTools.cpp]
2025-04-22 SPI instance acquisition added
2025-04-30 Fix SD card initialisation in WiFiTools
    [GUI.ino, WiFi.ino, WiFiTools.cpp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]
2025-05-13 Added subGHz module initalisation error handeling
    [GUI.ino, GUI_GSLC.h, IRTools.cpp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]
2025-07-19 Adding PCB files
    [0ZCJ0100FF2E.stp, 1-1825027-2.stp, 4 Inch TFT SPI 480x320 V1.2.step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]
